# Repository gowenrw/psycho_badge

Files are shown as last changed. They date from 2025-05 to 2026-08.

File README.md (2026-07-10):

# psycho_badge

This is where all the files for psycho_badge will be stored.

This includes code and art and cad and fab files.  All the things.

## File Structure

This is the file structure of this repository

* [/](/README.md) <- YOU ARE HERE
* [/3d_parts/](./3d_parts/) - 3D models of parts used in this project
* [/art/](./art/) - Artwork and other graphics created by this project
  * [/art/fonts/](./art/fonts/) - Fonts used in art and graphics
  * [/art/inspiration/](./art/inspiration/) - Art and graphics pulled from other sources used as inspiration for this project
  * [/art/logos/](./art/logos/) - Logos used in this project
* [/code/](./code/) - All project related Code / Firmware
* [/docs/](./docs/) - Documentation created by this project including web pages
* [/eda/](./eda/) - Electronic Design Automation files (i.e. KiCad)
  * [/eda/psycho_badge/](./eda/psycho_badge/) - KiCad 9.x project folder for the psycho_badge PCB
* [/reference_parts/](./reference_parts/) - Submodule of Third Party Documentation related to components
* [./README.md](/README.md) - This File
* [./LICENSE](/LICENSE) - Currently set to MIT

Note: the reference_parts directory is a link to a submodule repository.
To add it use the following cmd after cloning this:
```
git submodule add https://github.com/gowenrw/reference_parts reference_parts
```
This will make a link to the current commit of that repo.
To update it to a newer commit after its been added use this cmd:
```
git submodule update --init --recursive
```

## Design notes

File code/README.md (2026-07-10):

# Code

This is where all the project related Code / Firmware is located

# File Structure

This is the file structure of this repository

* [/](/README.md) - Home
* [/code/](/code/) - All project related Code / Firmware <-YOU ARE HERE

# Arduino IDE/CLI

The code presented here is mostly Arduino code.

In order to use this code and push new code to the ESP32 on the badge we recommend using the Arduino IDE/CLI software.
This can be downloaded for various platforms at [arduino.cc](https://www.arduino.cc/en/software).

The Arduino IDE UI will require some manual configuration to work with the badge ESP32 and our code.

The Arduino CLI can be used instead and allows for scripting much of the initial setup and use of whichever IDE you like (in my case I use VSCode).

# Arduino Versions

These are the Arduino IDE and CLI versions we have tested the code with:

* Arduino IDE v 2.3.2
  * [Windows MSI Link](https://downloads.arduino.cc/arduino-ide/arduino-ide_2.3.2_Windows_64bit.msi)
  * [Linux 64bit AppImage Link](https://downloads.arduino.cc/arduino-ide/arduino-ide_2.3.2_Linux_64bit.AppImage)
  * [MacOS ARM64bit DMG Link](https://downloads.arduino.cc/arduino-ide/arduino-ide_2.3.2_macOS_arm64.dmg)
  * [Installation Instructions](https://docs.arduino.cc/software/ide-v2/tutorials/getting-started/ide-v2-downloading-and-installing)
* Arduino CLI v 0.35.3
  * [Windows MSI Link](https://github.com/arduino/arduino-cli/releases/download/v0.35.3/arduino-cli_0.35.3_Windows_64bit.msi)
  * [Linux 64bit Tarball Link](https://github.com/arduino/arduino-cli/releases/download/v0.35.3/arduino-cli_0.35.3_Linux_64bit.tar.gz)
  * [MacOS ARM64bit Tarball Link](https://github.com/arduino/arduino-cli/releases/download/v0.35.3/arduino-cli_0.35.3_macOS_ARM64.tar.gz)
  * [Installation Instructions](https://arduino.github.io/arduino-cli/0.35/installation/)

WARNING - DO NOT use Arduino CLI v 1.x if you want the scripts here to work, it is very buggy concerning local config files and relative paths

# Quickstart

If you want to jump right in and start compiling and uploading code using the Arduino CLI and the scripts provided then checkout the [QUICKSTART page](QUICKSTART.md).

# Arduino IDE setup and use

Some additional setup is required to use the Arduino IDE with the ESP32 on the badge:

* Add the ESP32 boards manager URL in preferences
  * Under File->Preferences find the "Additional boards manager URLs" section and add the following
  * https://espressif.github.io/arduino-esp32/package_esp32_index.json
  * Then click OK and close the IDE.  When it is reopened it wil download the ESP32 board definitions.
* Select the board "ESP32 Dev Module"
  * You need to select a board to associate with the code even if that board is not connected
  * In the "Select Board" dropdown, choose "ESP32 Dev Module" from the list
  * The first time you do this it may download some addiotional software.
* Connect the ESP32 via USB cable and select the COM port if it is not autodetected
  * In most cases it should autodetect the port
  * Sometimes on first connect you need to help it by going to Tools->Port and choosing the port
* This code exceeds the normal partition size so make sure you select the Minimal SPIFFS Partition type
  * This setting can be found under Tools -> Partition Scheme
* This code uses the AdaFruit NeoPixel library which needs to be installed
  * The library can be installed via the Arduino IDE library manager or manually
  * Installation instructions can be found at [the adafruit neopixel github page](https://github.com/adafruit/Adafruit_NeoPixel)

Once the Arduino IDE environment has been set up you can simply open one of the sketches here, make whatever changes you like, then compile and upload the code to the badge.

# Arduino CLI

In an effort to bring portability to the code here (since this is lacking in the Arduino 2.x IDE) we will be providing a local configuration file for the Arduino CLI and scripts to make use of it.

While we cannot ensure this will work on all systems, the files provided should at a minimum help you configure your local environment.

## Using the CLI Local Config

The arduino cli will use a global default config if a config file is not specified.

A local config file is provided named ```arduino-cli.yml``` which uses relative path references for the data and staging and build and user area that Arduino CLI should use.

These directories are local to the repository code directory and the CLI will install all its needed files here instead of in the various places it usually defualts to on differnt systems.

While this might duplicate many files on your system if they are already installed in default locations, it provides a consistent cross platform way of knowing exactly what libraries, headers, etc., that Arduino will use in the compilation of your code.

NOTE that the .gitignore for this repository has been set up to ignore the local directories used to store the core and library files to prevent these files from accidentally getting uploaded to github.

To use the Arduino CLI with this local config file simply add the ```--config-file arduino-cli.yml``` argument to each CLI command.

For example, the command below uses the local config file and will dump the current config to the screen
```
arduino-cli --config-file arduino-cli.yml config dump
```

## Setup for CLI

There are a few things that need to be done to setup the Arduino CLI for use with the badge ESP32 and our code.

The ESP32 board core files must be loaded as well as any libraries the code will use.

To simplify this setup we have created setup bash script named ```cli-setup.sh``` that can be run on Linux and Windows (via Git Bash for Windows).

To perform the CLI setup via the script execute it in the code directory
```
bash ./cli-setup.sh
```

This script will save any std_out and std_err output to a file named ```arduino_cli_setup.log``` which you can review if you are having issues.

To perform the CLI setup manually without this script you can use the commands outlined below.

### Installing the ESP32 board core for CLI

Since the config is specifying a third party core for the ESP32 we need to pull an initial index from it.  This search command will pull that index.
```
arduino-cli --config-file arduino-cli.yml core search esp32
```

Next we need to install the ESP32 board core files using this command.
```
arduino-cli --config-file arduino-cli.yml core install esp32:esp32
```

If the ESP32 board core files were already installed the above will simply say already installed.

To update the core file indexs to check for newer versions of previously installed cores, use the following command
```
arduino-cli --config-file arduino-cli.yml core update-index
```

To upgrade any previously installed cores use the following command
```
arduino-cli --config-file arduino-cli.yml core upgrade
```

### Installing the Neopixel Library

This code uses the AdaFruit NeoPixel library which needs to be installed

If this is the first time we are installing a library we will need the indexes so this search command will get them
```
arduino-cli --config-file arduino-cli.yml lib search 'Adafruit NeoPixel'
```

Next we need to install the Adafruit NeoPixel library files with this command
```
arduino-cli --config-file arduino-cli.yml lib install 'Adafruit NeoPixel'
```

If the Adafruit NeoPixel library files were already installed the above will simply say already installed.

To upgrade a previously installed version of this library use the following command
```
arduino-cli --config-file arduino-cli.yml lib upgrade 'Adafruit NeoPixel'
```

### Installing Other Libraries

In addition to the Neopixel Library above the CTF portion of our code requires a few more libraries.

These should be installed using the same steps as above.

This is the list of additional libraries needed

* "AsyncTCP"
* "ESPAsyncWebSrv"
* "DNSServer"

## Connect badge ESP32 board via CLI

The following command will dump a list of all available board cores installed
```
arduino-cli --config-file arduino-cli.yml board listall
```

Make sure the ESP32 we are using on the badge is in that list
```
  ESP32 Dev Module                 esp32:esp32:esp32
```

If it is not then retry the CLI setup to install the core files.

Next we will connect the badge ESP32 to our machine using a USB C cable
and check if the CLI can see it.

The following command will list all the connected boards the CLI sees
```
arduino-cli --config-file arduino-cli.yml board list
```

This will show the detected COM port and board type (which may be Unknown)
```
  Port Protocol Type                Board Name FQBN Core
  COM4 serial   Serial Port (USB)   Unknown
```

Don't worry if the board FQBN shows up as Unknown since we can set that

Take note of the COM port since we will need that to communicate with it later

## Compile code via CLI

At this point we should be ready to compile and upload code to the badge ESP32 board.

In the following examples we will be referencing the sketch ```psycho_badge_01``` code so you will need to change this for whichever sketch you wish to use.

The following command will compile the named sketch for use with our board fqbn
```
arduino-cli --config-file arduino-cli.yml compile --fqbn esp32:esp32:esp32 --build-path _build --export-binaries psycho_badge_01 --build-property build.partitions=min_spiffs --build-property upload.maximum_size=1966080
```

The arg ```--build-path _build``` is optional to have it put all build artifacts here instead of temp for ease of troubleshooting.

The arg ```--export-binaries``` will save the final binary files into ```<sketch_name>/build/<fqbn>/``` for use by upload.

The build property args ```--build-property build.partitions=min_spiffs --build-property upload.maximum_size=1966080``` make sure that the partition size and upload size are set properly.
Our code is THIC and wont fit in the default partition size.

When the CLI compile is run it should show you compile stats and/or errors similar to this
```
  Sketch uses 1827197 bytes (92%) of program storage space. Maximum is 1966080 bytes.
  Global variables use 48884 bytes (14%) of dynamic memory, leaving 278796 bytes for local variables.
  Maximum is 327680 bytes.
  Used library        Version Path
  Adafruit NeoPixel   1.11.0  .\code\libraries\Adafruit_NeoPixel
  WiFi                2.0.0   .\code\_data\packages\esp32\hardware\esp32\2.0.11\libraries\WiFi
  AsyncTCP            1.1.4   .\code\libraries\AsyncTCP
  DNSServer           2.0.0   .\code\_data\packages\esp32\hardware\esp32\2.0.11\libraries\DNSServer
  ESPAsyncWebSrv      1.2.6   .\code\libraries\ESPAsyncWebSrv
  FS                  2.0.0   .\code\_data\packages\esp32\hardware\esp32\2.0.11\libraries\FS
  Used platform Version Path
  esp32:esp32   2.0.11  .\code\_data\packages\esp32\hardware\esp32\2.0.11
```

### Script to Compile code via CLI

To simplify the above we have created a bash script named ```cli-compile.sh``` that takes a single command line argument of the sketch name.

To perform the compile via the script execute it in the code directory
```
bash ./cli-compile.sh psycho_badge_01
```

## Upload code via CLI

Now we are ready to upload the binary we compiled to the badge ESP32 board.

Note that the binary file needed is saved to ```<sketch_name>/build/<fqbn>/``` and will be named ```<sketch_name>.ino.bin```
The code we have written here may include binaries which can be used without compiling and if you make changes and compile then these files should be overwritten.

The following command will upload the named sketch binary to the badge
```
arduino-cli --config-file arduino-cli.yml upload -p COM4 --fqbn esp32:esp32:esp32 --input-file psycho_badge_01/build/esp32.esp32.esp32/psycho_badge_01.ino.bin
```

NOTE: Saving the compiled binary in a defined place and uploading from an input file allows for quickly changing between different code without the need to compile each again.

It should show you upload stats and/or errors
```
  esptool.py v4.5.1
  Serial port COM4
  Connecting....
  Chip is ESP32-D0WD-V3 (revision v3.0)
  Features: WiFi, BT, Dual Core, 240MHz, VRef calibration in efuse, Coding Scheme None
  Crystal is 40MHz
  MAC: a8:42:e3:47:f0:50
  Uploading stub...
  Running stub...
  Stub running...
  Changing baud rate to 921600
  Changed.
  Configuring flash size...
  Flash will be erased from 0x00001000 to 0x00005fff...
  ...
  Compressed 18960 bytes to 13073...
  Writing at 0x00001000... (100 %)
  Wrote 18960 bytes (13073 compressed) at 0x00001000 in 0.3 seconds (effective 538.9 kbit/s)...
  Hash of data verified.
  ...
  Compressed 732656 bytes to 475614...
  Writing at 0x00010000... (3 %)
  Writing at 0x0001c1bd... (6 %)
  ...
  Writing at 0x000bcec0... (96 %)
  Writing at 0x000c2b72... (100 %)
  Wrote 732656 bytes (475614 compressed) at 0x00010000 in 6.3 seconds (effective 925.8 kbit/s)...
  Hash of data verified.
  Leaving...
  Hard resetting via RTS pin...
```

### Script to Upload code via CLI

To simplify the above we have created a bash script named ```cli-upload.sh``` that takes two command line arguments of the sketch name and serial port.

To perform the compile via the script execute it in the code directory
```
bash ./cli-upload.sh psycho_badge_01 COM4
```

## Monitor Serial Output

To monitor the serial output you can use the arduino-cli or your favorite serial app.

The following command will list all the connected boards so you can get the serial port
```
arduino-cli --config-file arduino-cli.yml board list
```

The arduino-cli monitor command with serial port (from above) and baud config can be used like this:
```
arduino-cli monitor --port COM4 --config baudrate=115200
```

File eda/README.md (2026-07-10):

# Electronic Design Automation

This is where all the Electronic Design Automation files for the PCB(s) will be stored.
The EDA used is KiCad 9.x unless otherwise specified.

The KiCad projects have been configured to use local libraries for long term sustainability per the best practices listed [HERE](https://hackaday.com/2017/05/18/kicad-best-practises-library-management/) and elsewhere.

## File Structure

This is the file structure of this repository

* [/](/README.md) - Home
* [/eda](/eda/) - Electronic Design Automation files - YOU ARE HERE
  * [/eda/psycho_badge/](/eda/psycho_badge/) - KiCad 9.x project folder for the psycho_badge PCB
    * ./3d_models/ - This directory contains footprint 3d model files
    * ./gerber/ - This directory contains gerber formatted files for manufacturing
    * ./lib_fp/ - This directory contains footprint module directories
    * ./lib_sh/ - This directory contains schematic library files
    * ./snapshots/ - This directory contains prints of schematic / cad files and images of preview / final product
  * [/eda/psycho_sao/](/eda/psycho_sao/) - KiCad 9.x project folder for the psycho_badge SAO PCBs
    * ./3d_models/ - This directory contains footprint 3d model files
    * ./gerber/ - This directory contains gerber formatted files for manufacturing
    * ./lib_fp/ - This directory contains footprint module directories
    * ./lib_sh/ - This directory contains schematic library files
    * ./snapshots/ - This directory contains prints of schematic / cad files and images of preview / final product

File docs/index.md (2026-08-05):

---
layout: default
---

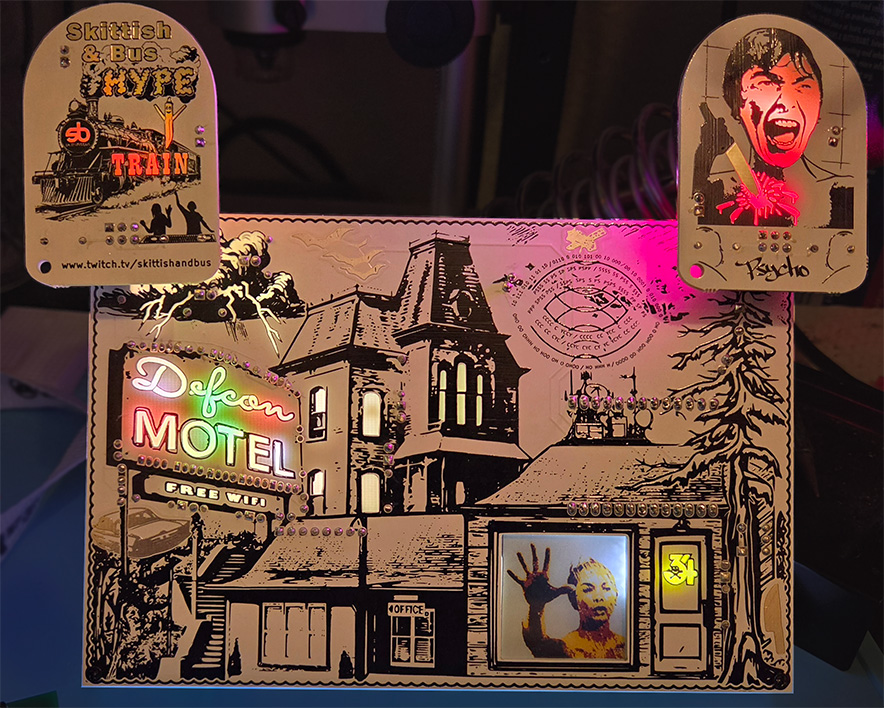
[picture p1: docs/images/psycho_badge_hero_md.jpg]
Hero Image


# Psycho Badge

Welcome to the Psycho Badge website.

This badge was designed for the DEFCON 34 security conference in August 2026.

On this page you will find all the details about this badge including an operations guide, some information about assembly, and a detailed review of the art and cicuit design and pcb design.

-- [@alt_bier](https://twitter.com/alt_bier)

---

# Overview

The badge theme was based on the 1960 movie Psycho by Alfred Hitchcock.

I wanted to make use of a multi-color eink display as a way to show scenes from the motel room and I think this worked out perfectly for that.

I also wanted to make use of electro-luminescent paint for the neon sign, but alas I couldn't work out the technical details in time to make that work on this badge.  But I think the back lit solder mask voids I ended up going with looks great.

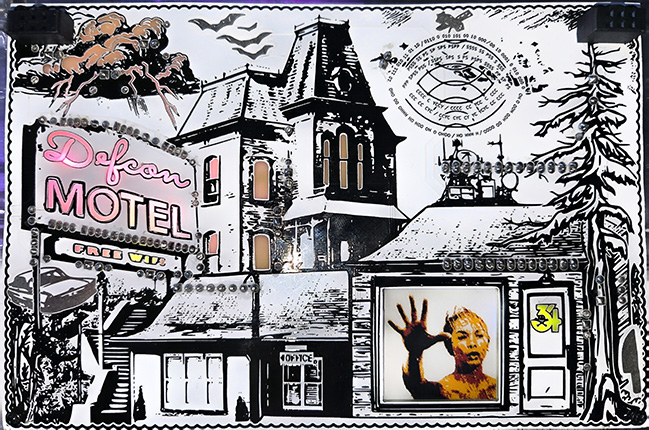
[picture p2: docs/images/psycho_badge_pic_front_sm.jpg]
Badge Pic Front


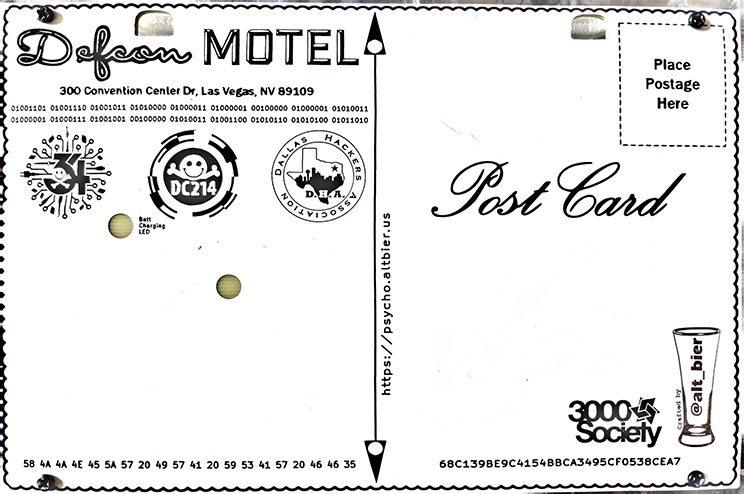
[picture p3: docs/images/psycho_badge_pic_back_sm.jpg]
Badge Pic Back


The badge has two SAO connectors and I made a Psycho themed SAO that pairs well with the badge.

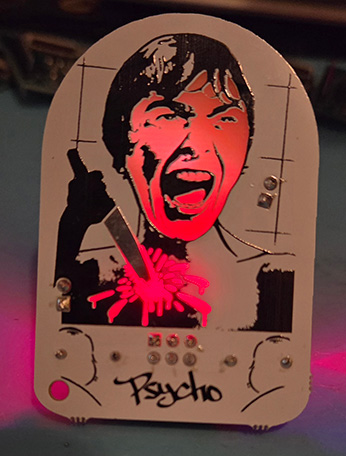
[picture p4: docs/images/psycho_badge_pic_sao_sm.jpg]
Badge Pic SAO


---

# Operations Guide

## Basic Operation

The on/off switch controls the battery power.  Due to a miscalculation on my part the switch is ON if it is in the down position relative to the top of the badge and OFF in the up position.

The badge can operate on USB C power with the battery switched off and it is recommended for the battery to be off when flashing code or using data to the ESP.

To charge the battery make sure the battery is turned on and plug it into USB power.  You will see an LED indicator on the back of the badge light up while the battery is charging and that light will go off when the battery is fully charged.

## Capacitive Touch Functions

### Short Press Of Touch Pads
To change the color of the LEDs in the neon sign press the BATS on the top left area of the badge.

To toggle the mode of the LEDs in the neon sign from static color to color wheel shifting colors or back again press the SATELLITE on the top right area of the badge.

To Turn the "Free Wifi" LEDs on or off press the CAR on the bottom left area of the badge.

To Turn the Defcon 34 Logo on the Door on or off press the KNIFE on the bottom right area of the badge. Note: This light also acts as a screen light since the EINK display is not backlit.

### Long Press Of Touch Pads

To change the display image to the next one in order press and hold the KNIFE for about 20 seconds.

To change the display image to the previous one in order press and hold the CAR for about 20 seconds.

To turn off all LEDs on the front of the badge while keeping the badge powered on (useful for battery charging unless you like a night lite) press and hold the BATS for about 40 seconds.

---

# Crypto Challenge

This is still a work in progress, but I will be adding more details soon.

---

# Details

Lets get into the details of this badge, like Art and Schematics and PCB design and Component choices.

## Pinout and Bill of Materials

Since there is a lot of information to cover, I have put the pinout and bill of materials on a separate page here:
[Psycho Badge Pinout and Bill of Materials](psycho_badge_pinout_and_BOM.md)

## Schematics 

Since the ESP Dev board has an embedded battery charge circuit and the fact that I moved all the eink display circuitry to a seperate dev board, the schematic for the main badge was fairly simple.

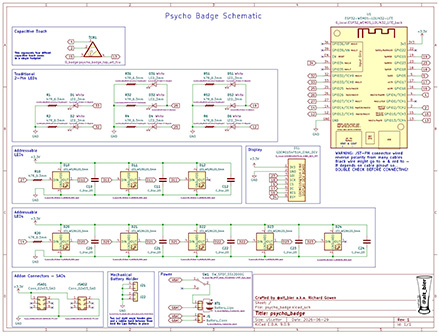
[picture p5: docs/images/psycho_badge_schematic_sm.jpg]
Badge Schematic


The schematic for the eink display dev board was a bit more complex but I basically just stole its design from the dev board that the nice people at Good Display sell since they put thier schematic online.

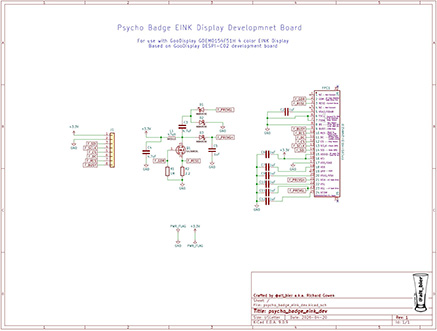
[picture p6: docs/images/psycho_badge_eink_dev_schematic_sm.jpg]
Eink Display Dev Schematic


The SAO schematic is basically a cut and paste from what I did for the G0dzilla badge minus the extra resistors at different values, making it a much simpler template I can reuse in the future as well.

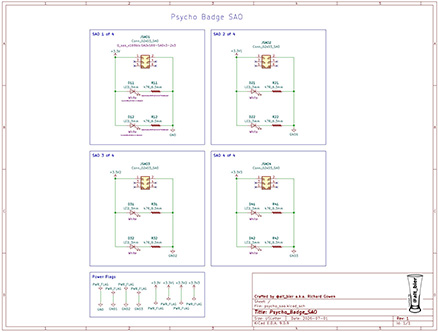
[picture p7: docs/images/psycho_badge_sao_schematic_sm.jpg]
Badge SAO Schematic


## PCB Design

The PCB layout and tracing of the badge PCBs was a challenge due to all the solder mask voids and capacitive touch areas and cutouts and other areas to avoid.

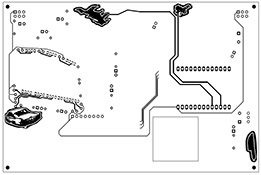
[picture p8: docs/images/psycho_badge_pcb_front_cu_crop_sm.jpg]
Badge PCB Front CU


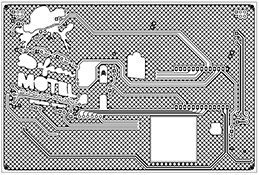
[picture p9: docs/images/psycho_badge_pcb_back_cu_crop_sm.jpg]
Badge PCB Back CU


The PCB layout and tracing of the eink dev board was fairly easy, with the hardest part being squishing everything together to keep the PCB size as small as possible.

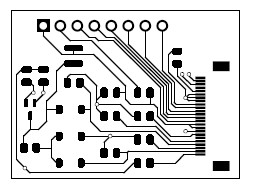
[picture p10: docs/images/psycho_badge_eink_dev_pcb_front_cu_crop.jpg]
Eink Display Dev PCB Front CU


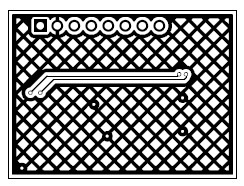
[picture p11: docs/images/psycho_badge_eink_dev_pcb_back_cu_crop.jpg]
Eink Display Dev PCB Back CU


The PCB layout and tracing of the SAO was simple given how few components there are.

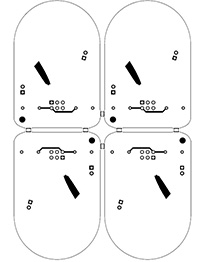
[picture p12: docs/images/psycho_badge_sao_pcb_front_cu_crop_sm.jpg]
Badge SAO PCB Front CU


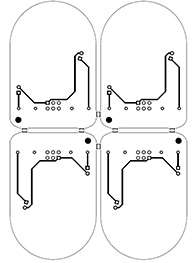
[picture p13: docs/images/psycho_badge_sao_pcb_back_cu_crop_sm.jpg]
Badge SAO PCB Back CU


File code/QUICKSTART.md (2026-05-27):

# Code Quickstart

Notes:

* You will need Arduino CLI Installed and a Bash shell (on Windows Git Bash is provided by Git for Windows)
* The CTF code is a precompiled library so you cant change that for now, source to be released after defcon
* The current code that is loaded on the badge is the sketch named ```psycho_badge_01```

## Setting up Arduino CLI environment

Follow these steps:

* Change directory to the code directory if you arent already there
* Run the following command preceding it with ```bash``` if needed by your OS
  * ```./cli-setup.sh```
* If it completes without errors then setup is complete
  * If you have errors then refer to the main README doc or script file to try the steps manually

## Compiling Code

Once you have made whatever changes you wanted to the code here is how we compile it.

* Change directory to the code directory if you arent already there
* Run the following command preceding it with ```bash``` if needed by your OS changing the sketch name if needed
  * ```./cli-compile.sh psycho_badge_01```
* If it completes without errors then the compile is complete
  * If you have errors then read what they are and make the appropriate changes to your code

## Upload Code

Once the code has been compiled we can upload it to the badge.

Follow these steps:

* Change directory to the code directory if you arent already there
* Run the following command
  * ```arduino-cli --config-file arduino-cli.yml board list```
* Take note of the serial port name of the connected board 
* Run the following command preceding it with ```bash``` if needed and changing the serial port to above
  * ```./cli-upload.sh psycho_badge_01 COM6```

## Serial Monitor

Once the code has been uploaded you can use the serial monitor to look for any text the code is sending.

* Run the following command changing the serial port to what board list showed above
  * ```arduino-cli monitor --port COM6 --config baudrate=115200```

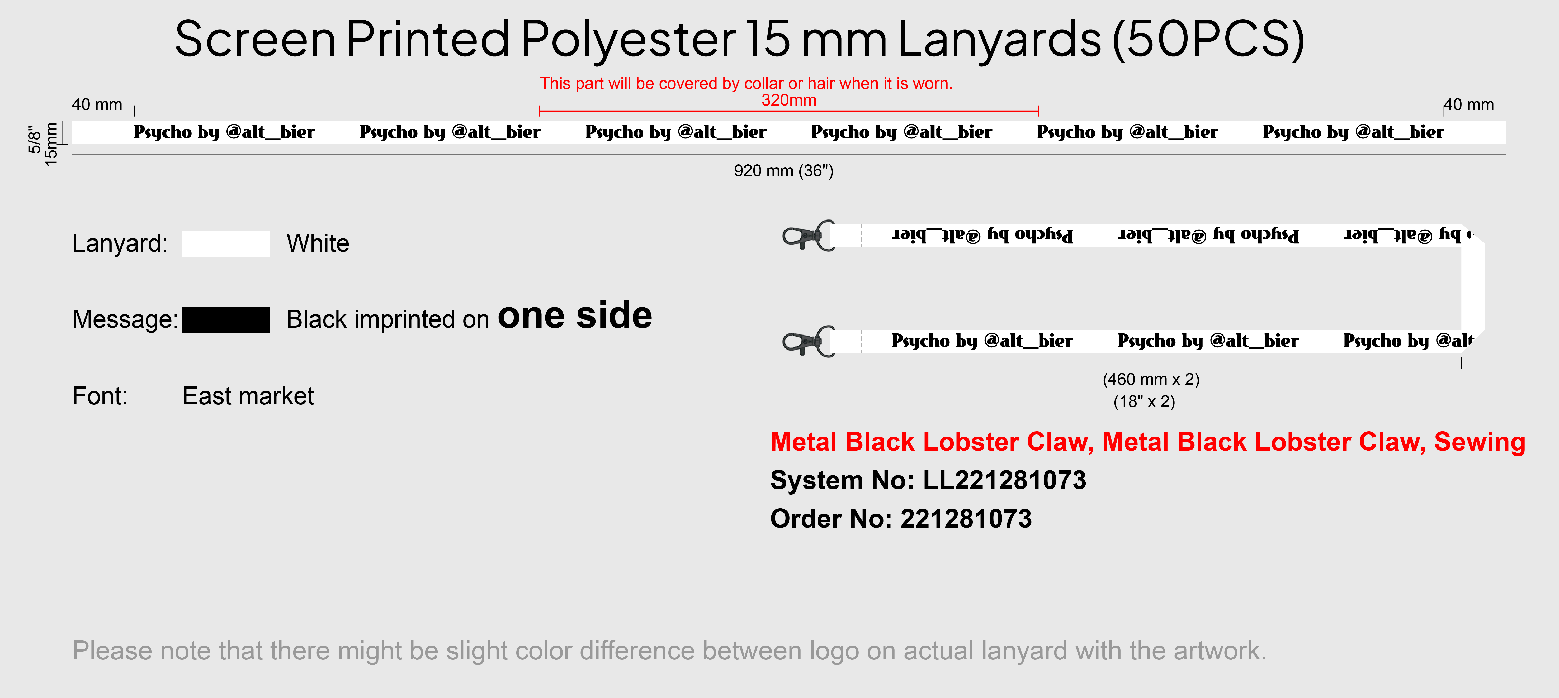
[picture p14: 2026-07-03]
docs/lanyard_proof.png

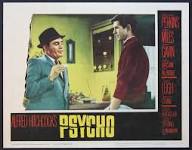
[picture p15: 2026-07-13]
art/inspiration/PsychoLC5A_2.jpg

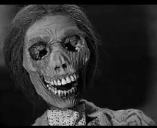
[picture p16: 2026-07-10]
art/inspiration/Screenshot 2026-07-10 091427.png

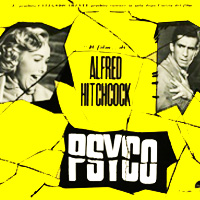
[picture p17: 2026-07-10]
art/psycho_display_img01.jpg

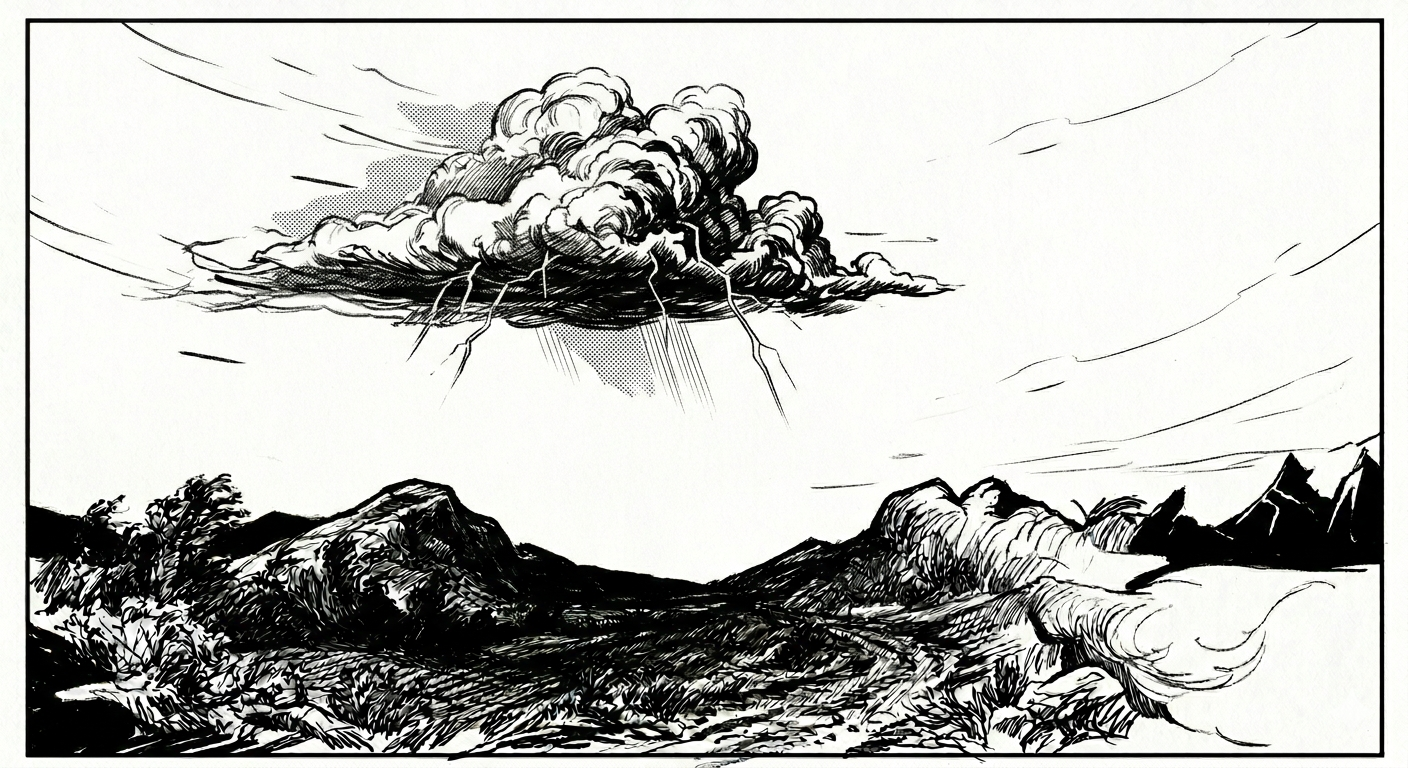
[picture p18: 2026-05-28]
art/inspiration/alt_bier_image_rrnbitrrnbitrrnb.png

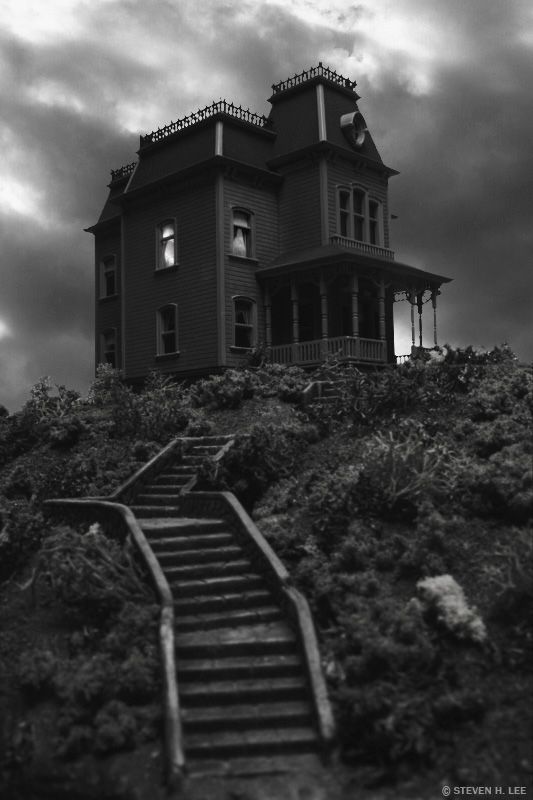
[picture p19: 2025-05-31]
art/inspiration/5f103922b00b9d7b980ad2bd9242dba4.jpg

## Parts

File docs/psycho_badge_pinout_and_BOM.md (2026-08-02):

# Psycho Badge Pinout and Bill of Materials

## Pinout

ESP32 PINS and Their Connections on the Badge

NEOPIXEL Strings
* 27 - Neo String 1 - D10, D11, D12 - Defcon
* 14 - Neo String 2 - D20, D21, D22, D23, D24 - MOTEL

Tradional LEDs
* 22 - Built In LED
* 33 - D1 - FREE
* 32 - D2 - WIFI
* 26 - D31, D32 - Clouds
* 25 - D4 - Clouds
* 19 - D51, D52 - Mansion
* 12 - D6 - Room_Door

EINK Dev Board
* 23 - DevBd 3 - SDI
* 18 - DevBd 4 - SCK
* 5  - DevDb 5 - CS
* 17 - DevBd 6 - DS
* 16 - DevBd 7 - RES
* 34 - DevBd 8 - BSY
* 0  - Remap ESP32 MISO default pin 19 (not used by EINK but conflict with LED)

Capacitive Touch Pads
* 4  - TCH1 1 - Bats
* 2  - TCH1 2 - Satelite
* 15 - TCH1 3 - Car
* 13 - TCH1 4 - Knife

## Bill of Materials

Controller - Qty 1
* ESP32-WEMOS-LOLIN32-LITE v1.0 with USB-C connector
  * https://www.aliexpress.us/item/3256808856916958.html

Addressable LEDs - Qty 8
* WS2812D F5 5mm LED (NeoPixel)
  * https://www.aliexpress.us/item/2251832645784910.html

Traditional LEDs White - Qty 8
* 3mm Round White LEDs
  * https://www.aliexpress.us/item/2251832158199793.html

Resistors 47Ohm - Qty 10
* 47 Ohm 1/4W Resistor
  * https://www.aliexpress.us/item/3256805626032565.html

Capacitors 100nF - Qty 8
* Ceramic Disc Capacitor 0.1uF 50V 104PF 100NF
  * https://www.amazon.com/Cermant-Ceramic-Capacitor-Electronic-Components/dp/B09XV2H8JQ

SAO Connectors (Badge Side) - Qty 2
* 2.54mm 0.1" Pitch Female Pin Header Strip 2x3 Pin 6 Pin With Polarizing Key
  * https://www.aliexpress.us/item/2251832874579437.html

LIPO Battery - Qty 1
* 103040 3.7V 1200mAh Polymer Lithium Rechargeable Battery
  * https://www.aliexpress.us/item/3256811756405914.html

JST Battery Connector Cable - Qty 1
* JST 1.25mm 2 Pin Micro Female Connector Plug with Red Black Wire
  * https://www.amazon.com/dp/B013JRWCBU

Header Pins 1x2/90-Degree for Battery Holding - Qty 2
* 1x2 2.54mm Male 90-Degree Right Angle Header Pins
  * https://www.amazon.com/dp/B07C89T16T

Rubber Bands for Battery Holding - Qty 2
* #8 Rubber Bands - 7/8" x 1/16"
  * https://www.amazon.com/dp/B0BN6MKF99

Two Position Slide Switch - Qty 1
* Slide Switch SS12D00 SS12D03G5 3pin Curved 90 Degree Needle 1P2T 2 Position 5mm Handle
  * https://www.aliexpress.us/item/2251832665517359.html

EINK Display - Qty 1
* GDEM0154F61H GooDisplay 1.54 inch E-paper Four Color (Yellow and Red) Display 200x200
  * https://www.aliexpress.us/item/3256806898128301.html
  * https://www.good-display.com/product/555.html

Custom Dev Board for EINK Display - Qty 1
* Custom PCB for EINK Display (See psycho_badge_eink_dev schematic for details)
  * Parts for the custom dev board (SMT components)
    * FPC Connector FPC05-H0.5-24AH2.0 24 Position 0.5mm Pitch Double-Sided - Qty 1
      * https://www.lcsc.com/product-detail/C19267963.html
    * Ceramic Capacitor 1uF X7R ±10% 25V 0805 - Qty 8
      * https://www.lcsc.com/product-detail/C53084463.html
    * Ceramic Capacitor 4.7uF X7R ±10% 25V 0805 - Qty 2
      * https://www.lcsc.com/product-detail/C513766.html
    * Resistor 2.2Ohm ±1% 0.125W 0805 - Qty 1
      * https://www.lcsc.com/product-detail/C137549.html
    * Resistor 1MOhm ±1% 0.125W 0805 - Qty 1
      * https://www.lcsc.com/product-detail/C2933280.html
    * Schottky Diode MBR0530 0.5A 30V SOD-123 - Qty 3
      * https://www.lcsc.com/product-detail/C53100353.html
    * Transistor MOSFET SI1308EDL 30V 1.4A 360mW SOT-323 - Qty 1
      * https://www.lcsc.com/product-detail/C7603347.html
    * Inductor NR3015 47uH ±20% 350mA 1.195Ohm SMD-3mmx3mm - Qty 1
      * https://www.lcsc.com/product-detail/C42370344.html

Custom 3D printed spacer insert for PCB sandwich mounting - Qty 1
* 3D printed board spacer for mounting the PCBs
  * 4inch x 6inch overall outer dimentions, 10mm tall, 5mm think with 1.5mm holes for screw mounting, cutout on one side for esp/switch access, divots on top for lanyard hole access.
  * [/3d_parts/board_spacer.3mf](/3d_parts/board_spacer.3mf)

M2 Mounting Screws - Qty 8
* M2 Carbon Steel Cross Phillips Countersunk Pan Head Self Tapping Screws
  * https://www.aliexpress.us/item/3256803991037432.html

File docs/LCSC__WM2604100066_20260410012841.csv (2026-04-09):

LCSC Part Number | Manufacture Part Number | Manufacturer | Customer NO. | Package | Description | RoHS | Quantity | Unit Price($) | Ext.Price($) | Estimated lead time (business days) | Updated lead time | Date Code / Lot No.
C19267963 | FPC05-H0.5-24AH2.0 | XYECONN |  | SMD,P=0.5mm,Surface Mount,Right Angle | FFC/FPC Connector 24 Position 0.5mm Pitch Double-Sided Contacts, Top and Bottom Entry Surface Mount, Right Angle | YES | 150 | 0.088 | 13.20
C53084463 | CC0805X7R25V105KN | TORCH |  | 0805 | 1uF X7R ±10% 25V 0805 Ceramic Capacitors RoHS | YES | 1000 | 0.0066 | 6.60
C513766 | CS2012X7R475K250NRE | SAMWHA |  | 0805 | 4.7uF ±10% 25V Ceramic Capacitor X7R 0805 | YES | 500 | 0.0124 | 6.20
C137549 | RC0805FR-072R2L | YAGEO |  | 0805 | 125mW 2.2Ω 150V Thick Film Resistor ±1% ±200ppm/℃ 0805 Chip Resistor - Surface Mount RoHS | YES | 500 | 0.0077 | 3.85
C2933280 | FRC0805F1004TS | FOJAN |  | 0805 | 1MΩ ±1% 125mW 0805 Thick Film Resistor | YES | 1000 | 0.0017 | 1.70
C53100353 | MBR0530 | TECH PUBLIC |  | SOD-123 | 5.5A 1 Independent 30V 430mV@500mA 5.5A SOD-123 Single Diodes RoHS | YES | 500 | 0.0114 | 5.70
C7603347 | SI1308EDL | TECH PUBLIC |  | SOT-323 | 30V 1.4A 360mW Surface Mount SOT-323 | YES | 300 | 0.058 | 17.40
C42370344 | NR3015S470MT | Magnetsyc |  | SMD,3x3mm | 350mA 47uH 350mA 1.195Ω ±20% SMD,3x3mm Fixed Inductors RoHS | YES | 200 | 0.0226 | 4.52

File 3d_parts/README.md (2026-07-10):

# 3d_parts

3D models of parts used in this project

## File Structure

This is the file structure of this repository

* [/](/README.md) - Home
* [/3d_parts/](/3d_parts/) - 3D models of parts used in this project <- YOU ARE HERE

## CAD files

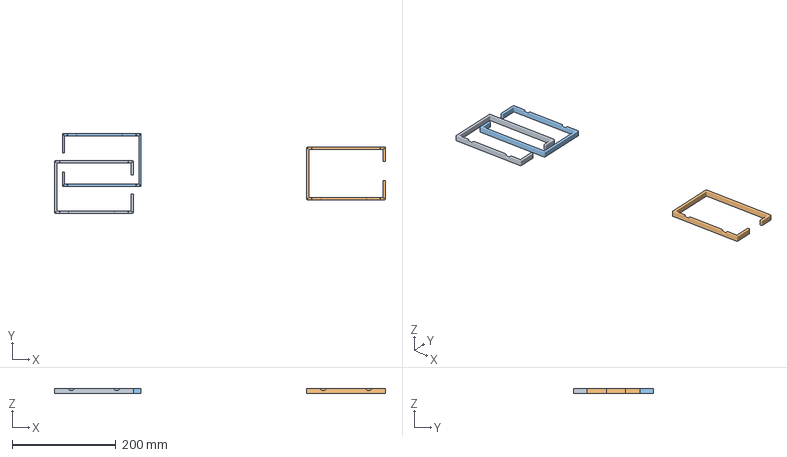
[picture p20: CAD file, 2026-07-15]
3d_parts/CE3PRO_psycho_badge_rev2-board_spacer-2.3mf
638.9 x 153.7 x 10.0 mm
psycho_badge_rev2-board_spacer.3mf
psycho_badge_rev2-board_spacer.3mf(1)
psycho_badge_rev2-board_spacer.3mf(3)

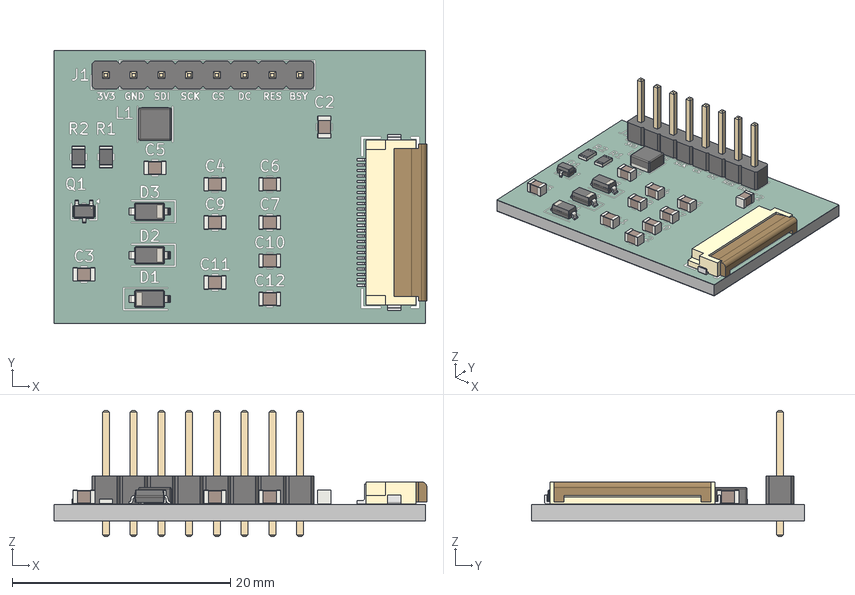
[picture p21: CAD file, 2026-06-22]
eda/psycho_sao/3d_models/psycho_badge_eink_dev.step
34.2 x 25.0 x 11.5 mm
PinHeader_1x08_P2.54mm_Vertical
lock
pins
D_SOD-123 x 3
C_0805_2012Metric x 10
SOT-323_SC-70
R_0805_2012Metric x 2
L_APV_ANR3015
psycho_badge_eink_dev_silkscreen x 2
psycho_badge_eink_dev_soldermask x 2
psycho_badge_eink_dev_PCB

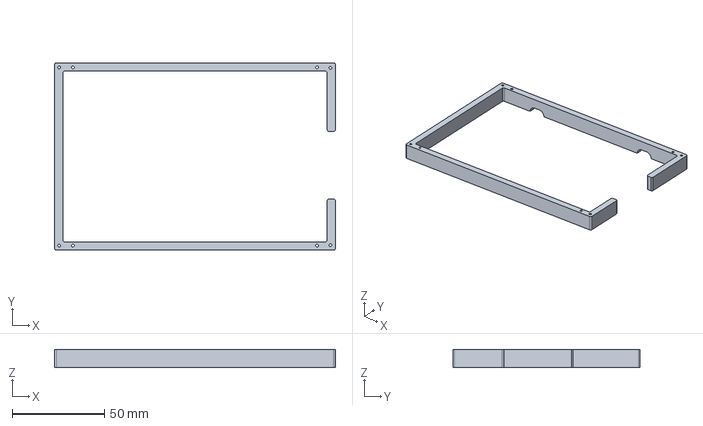
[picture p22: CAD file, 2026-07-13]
3d_parts/psycho_badge_rev2.FCStd
152.4 x 101.6 x 10.0 mm

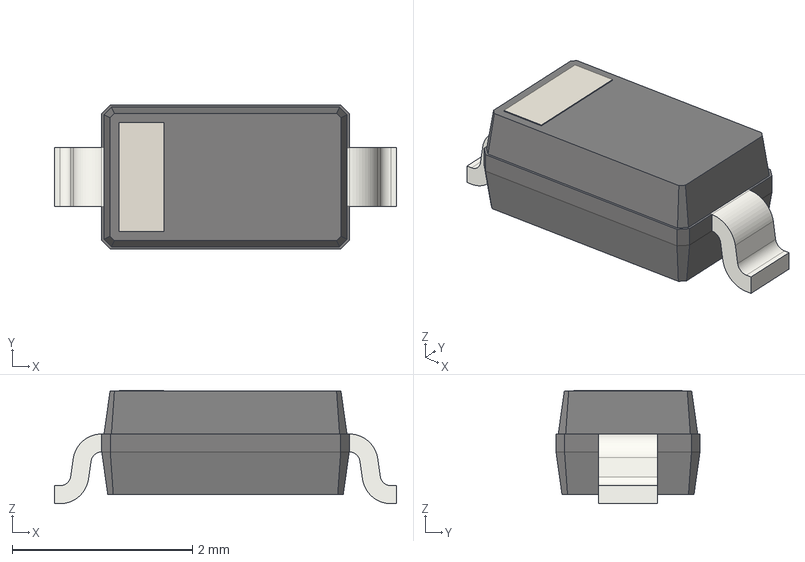
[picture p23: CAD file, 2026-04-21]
eda/psycho_sao/3d_models/D_SOD-123.step
3.80 x 1.60 x 1.26 mm

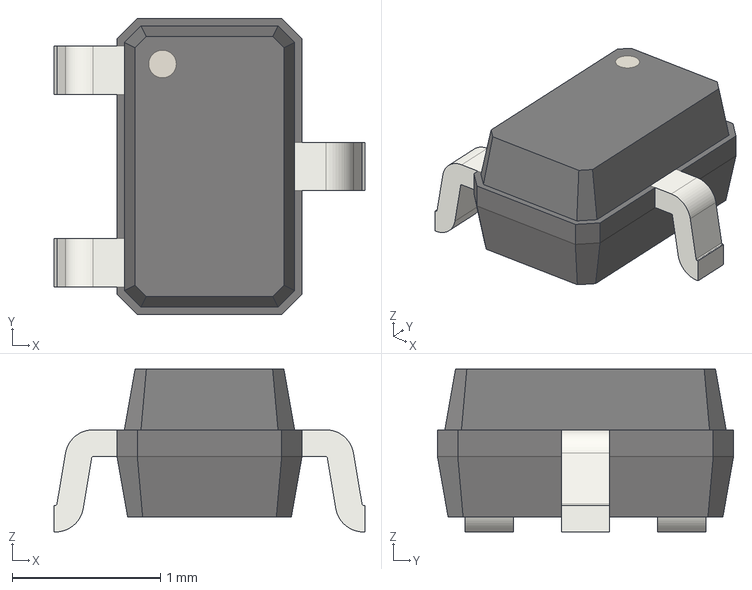
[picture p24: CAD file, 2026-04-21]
eda/psycho_sao/3d_models/SOT-323_SC-70.step
2.10 x 2.00 x 1.10 mm

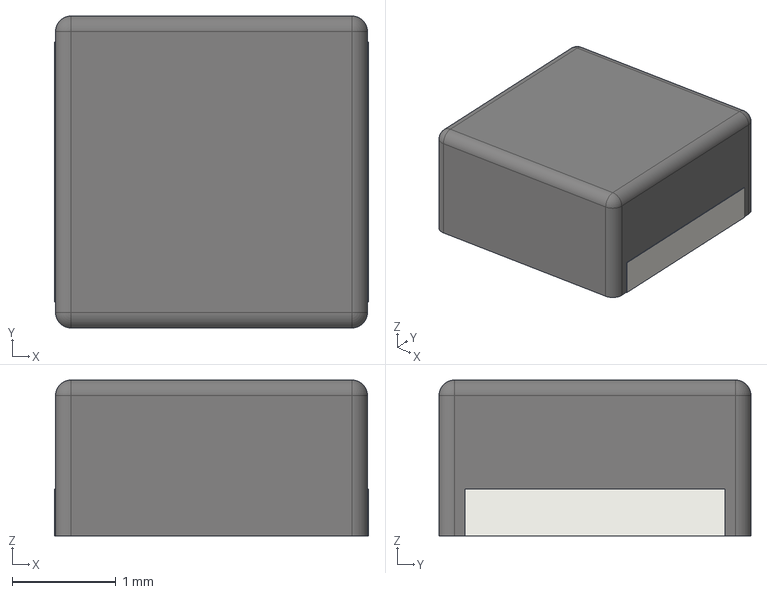
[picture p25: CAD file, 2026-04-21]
eda/psycho_sao/3d_models/L_APV_ANR3015.step
3.02 x 3.00 x 1.50 mm

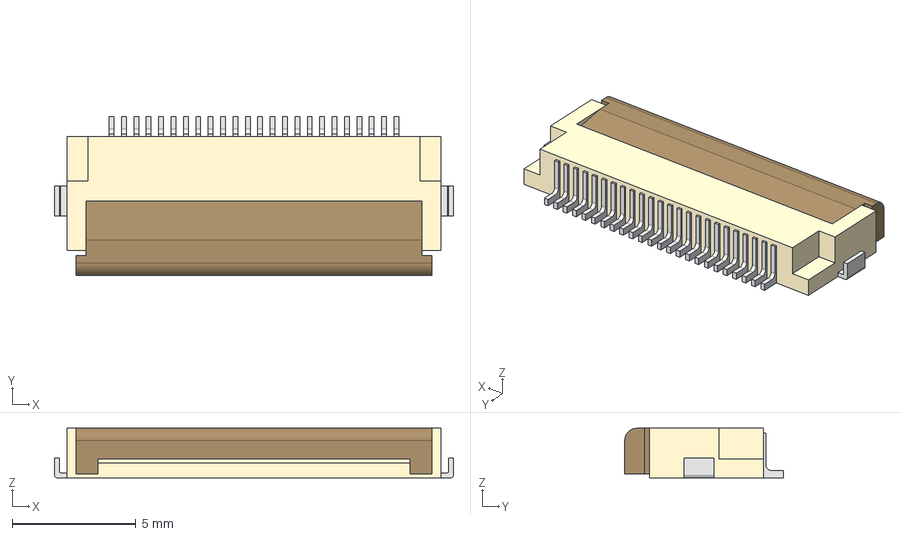
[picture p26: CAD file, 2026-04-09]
eda/psycho_sao/3d_models/Hirose_FH12-24S-0.5SH_1x24-1MP_P0.50mm_Horizontal.step
16.1 x 6.40 x 2.00 mm
lock
pins

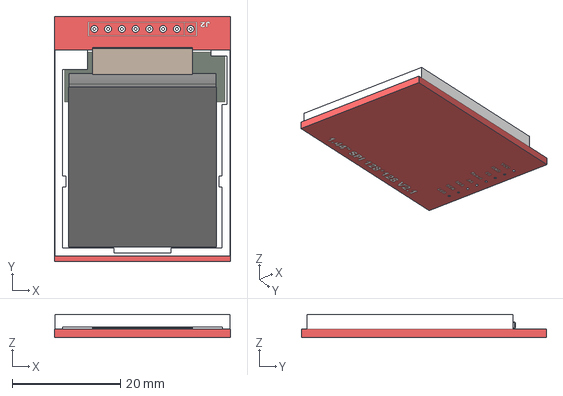
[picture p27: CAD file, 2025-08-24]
eda/psycho_sao/3d_models/TFT_LCD_ST7735S_MSP1443_SPI_1_44IN.STEP
32.5 x 45.2 x 4.32 mm

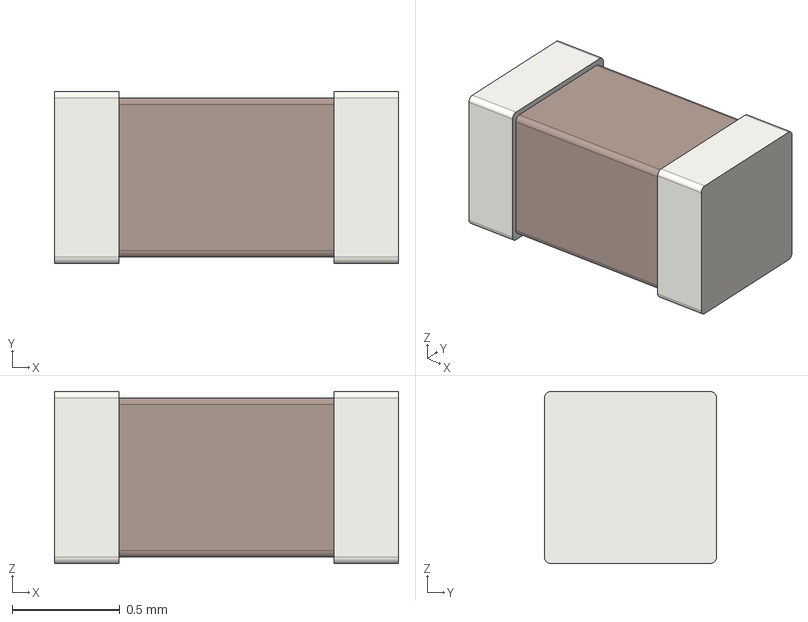
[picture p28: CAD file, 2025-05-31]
eda/psycho_sao/3d_models/C_0603_1608Metric.step
1.60 x 0.8 x 0.8 mm

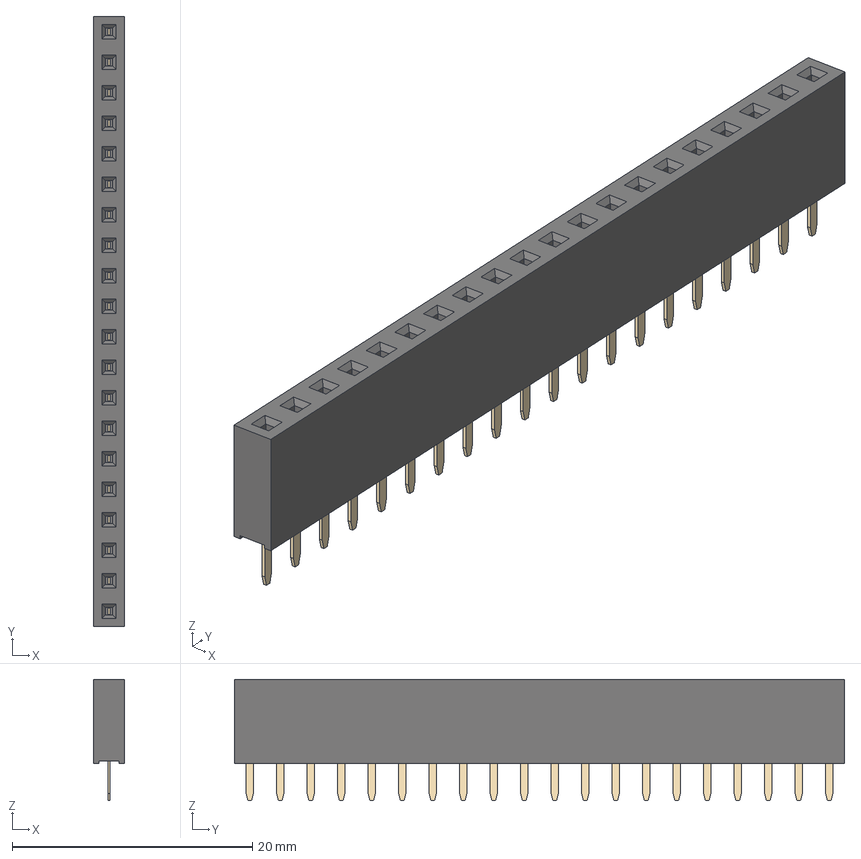
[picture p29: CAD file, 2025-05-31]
eda/psycho_sao/3d_models/PinSocket_1x20_P2.54mm_Vertical.step
2.54 x 50.8 x 10.1 mm

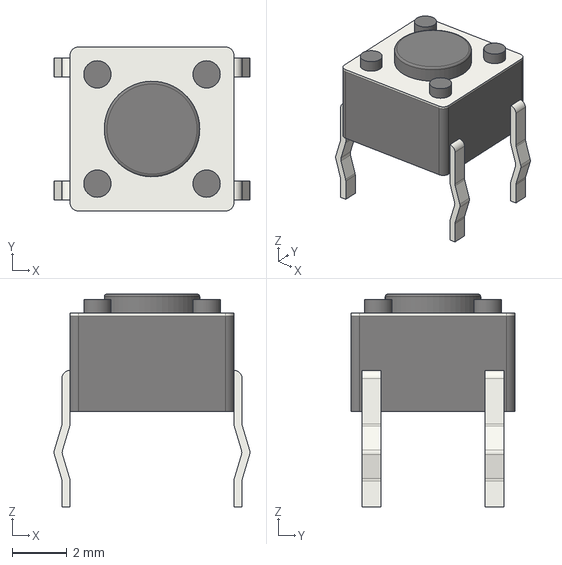
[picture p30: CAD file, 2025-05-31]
eda/psycho_sao/3d_models/SW_PUSH_6mm.step
7.17 x 6.00 x 7.80 mm

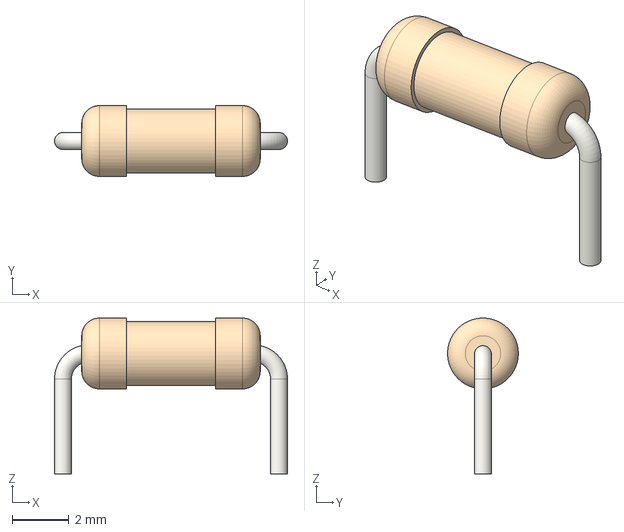
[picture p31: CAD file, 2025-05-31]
eda/psycho_sao/3d_models/R_Axial_DIN0207_L6.3mm_D2.5mm_P7.62mm_Horizontal.step
8.22 x 2.50 x 5.50 mm

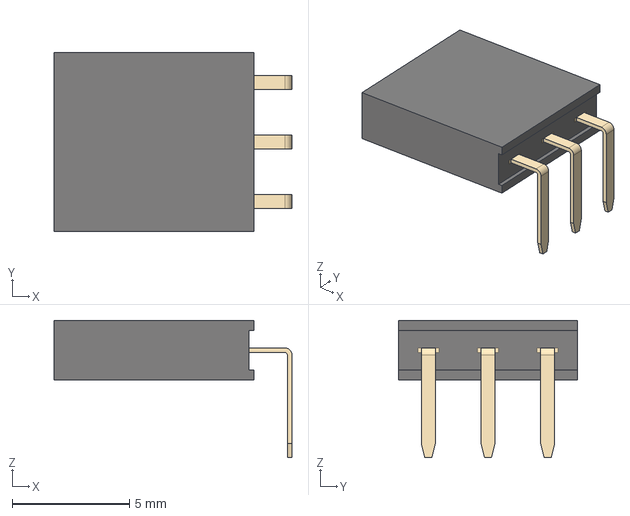
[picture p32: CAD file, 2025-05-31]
eda/psycho_sao/3d_models/PinSocket_1x03_P2.54mm_Horizontal.step
10.1 x 7.62 x 5.84 mm

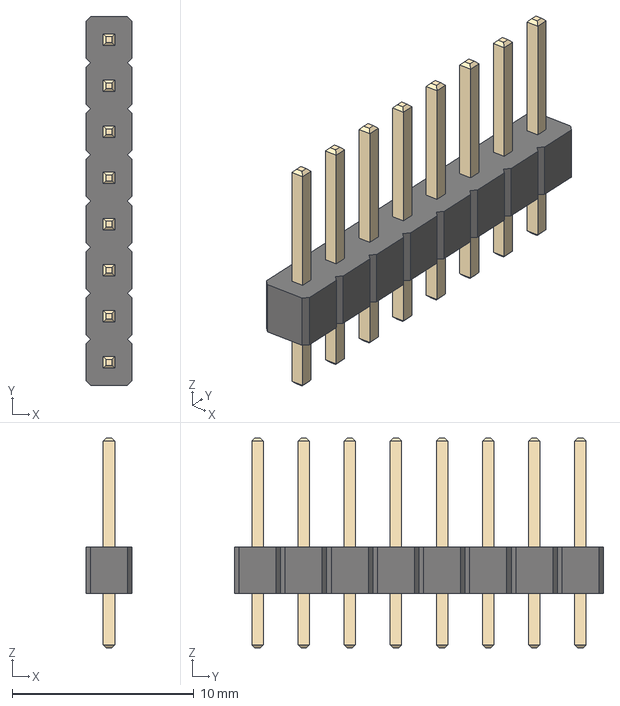
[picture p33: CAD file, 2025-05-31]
eda/psycho_sao/3d_models/PinHeader_1x08_P2.54mm_Vertical.step
2.54 x 20.3 x 11.5 mm

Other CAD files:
3d_parts/psycho_badge_rev2-board_spacer.3mf
3d_parts/CE3PRO_psycho_badge_rev2-board_spacer-1.3mf
3d_parts/board_spacer.3mf
eda/psycho_sao/3d_models/LED_D5.0mm_Horizontal_O1.27mm_Z3.0mm.step
3d_parts/psycho_badge.FCStd
eda/psycho_badge/gerber/psycho_badge_eink_dev_export/psycho_badge_eink_dev-F_Paste.dxf
eda/psycho_badge/gerber/psycho_badge_eink_dev_export/psycho_badge_eink_dev-F_Silkscreen.dxf
eda/psycho_sao/3d_models/BatteryHolder_2466_1xAAA.step
eda/psycho_sao/3d_models/BatteryHolder_2468_2xAAA.step
eda/psycho_sao/3d_models/Battery_Holder_3xAAA_Simple.step
eda/psycho_sao/3d_models/Battery_Holder_CR2032_BS-2-1.stp
eda/psycho_sao/3d_models/CP_Radial_D5.0mm_P2.00mm.step
eda/psycho_sao/3d_models/CP_Radial_D6.3mm_P2.50mm.step
eda/psycho_sao/3d_models/CUI_PXO7803-500-M-TR.step
eda/psycho_sao/3d_models/C_0805_2012Metric.step
eda/psycho_sao/3d_models/C_1206_3216Metric.step
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

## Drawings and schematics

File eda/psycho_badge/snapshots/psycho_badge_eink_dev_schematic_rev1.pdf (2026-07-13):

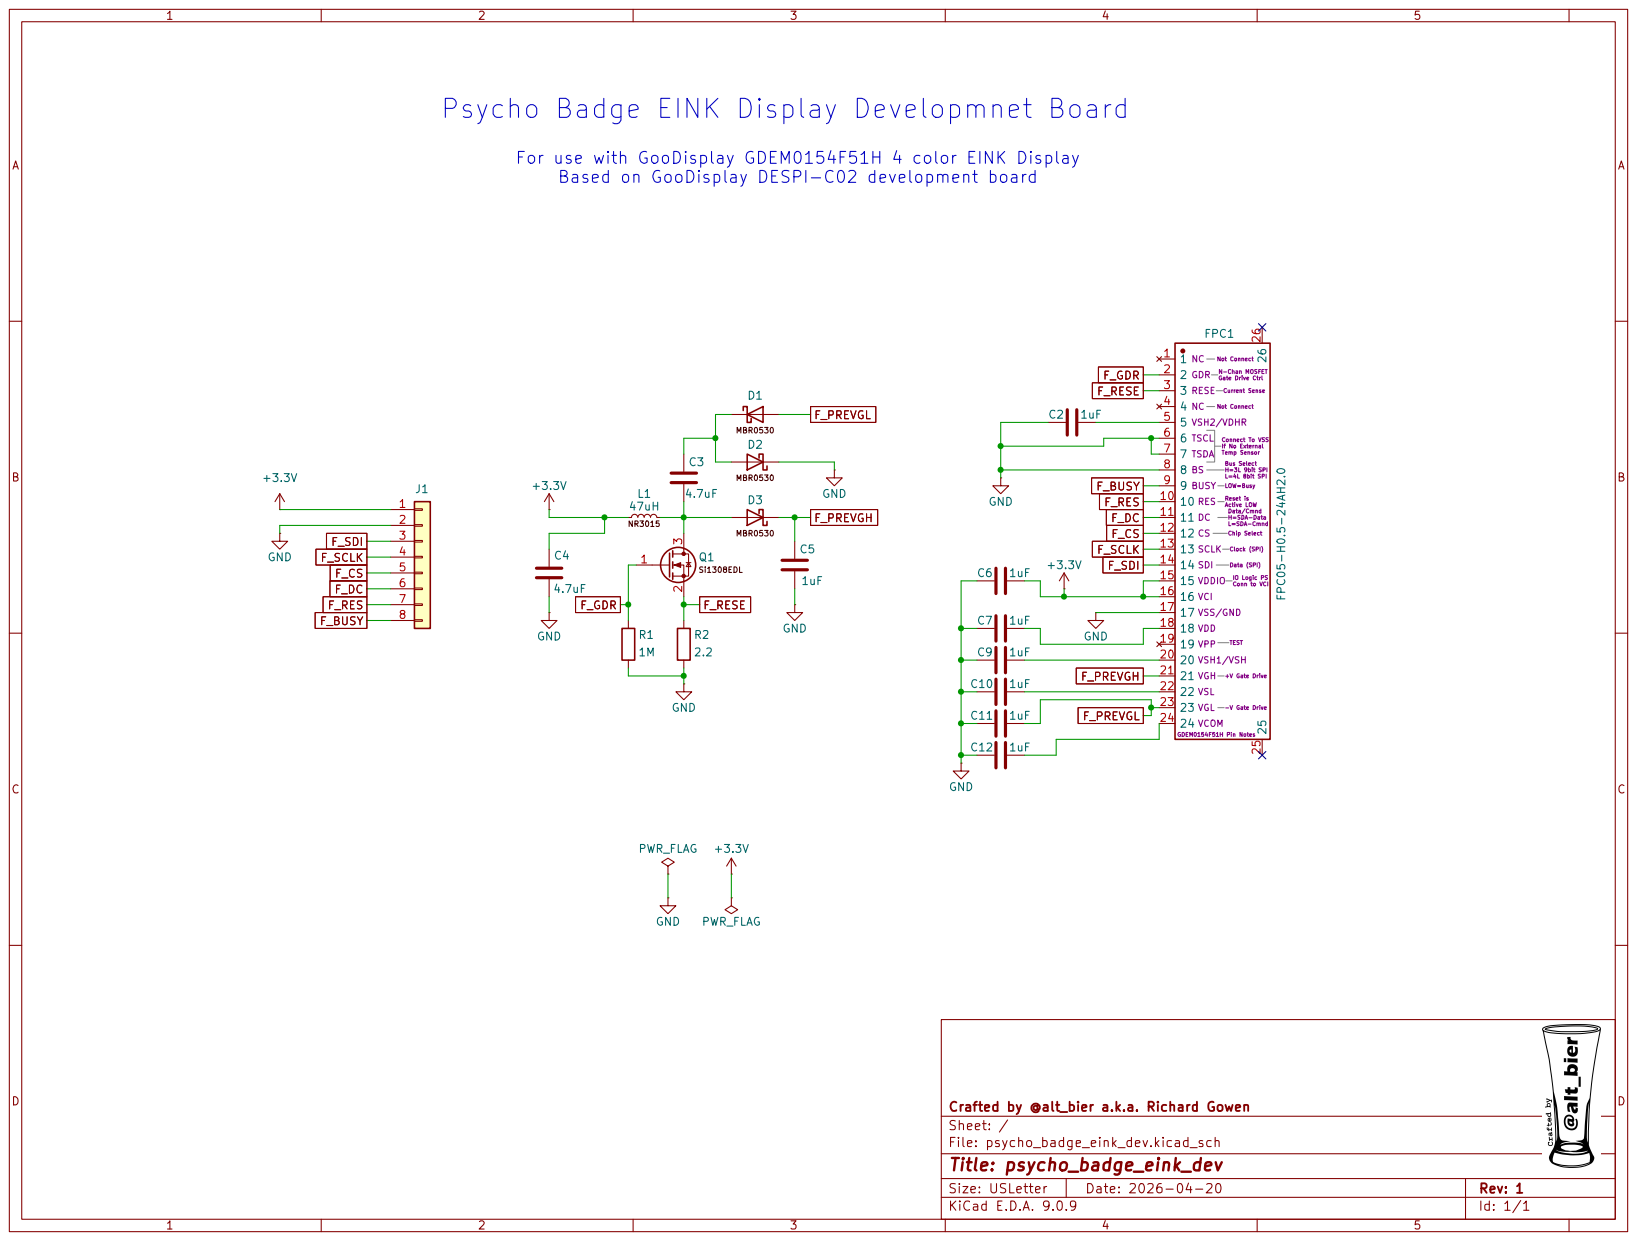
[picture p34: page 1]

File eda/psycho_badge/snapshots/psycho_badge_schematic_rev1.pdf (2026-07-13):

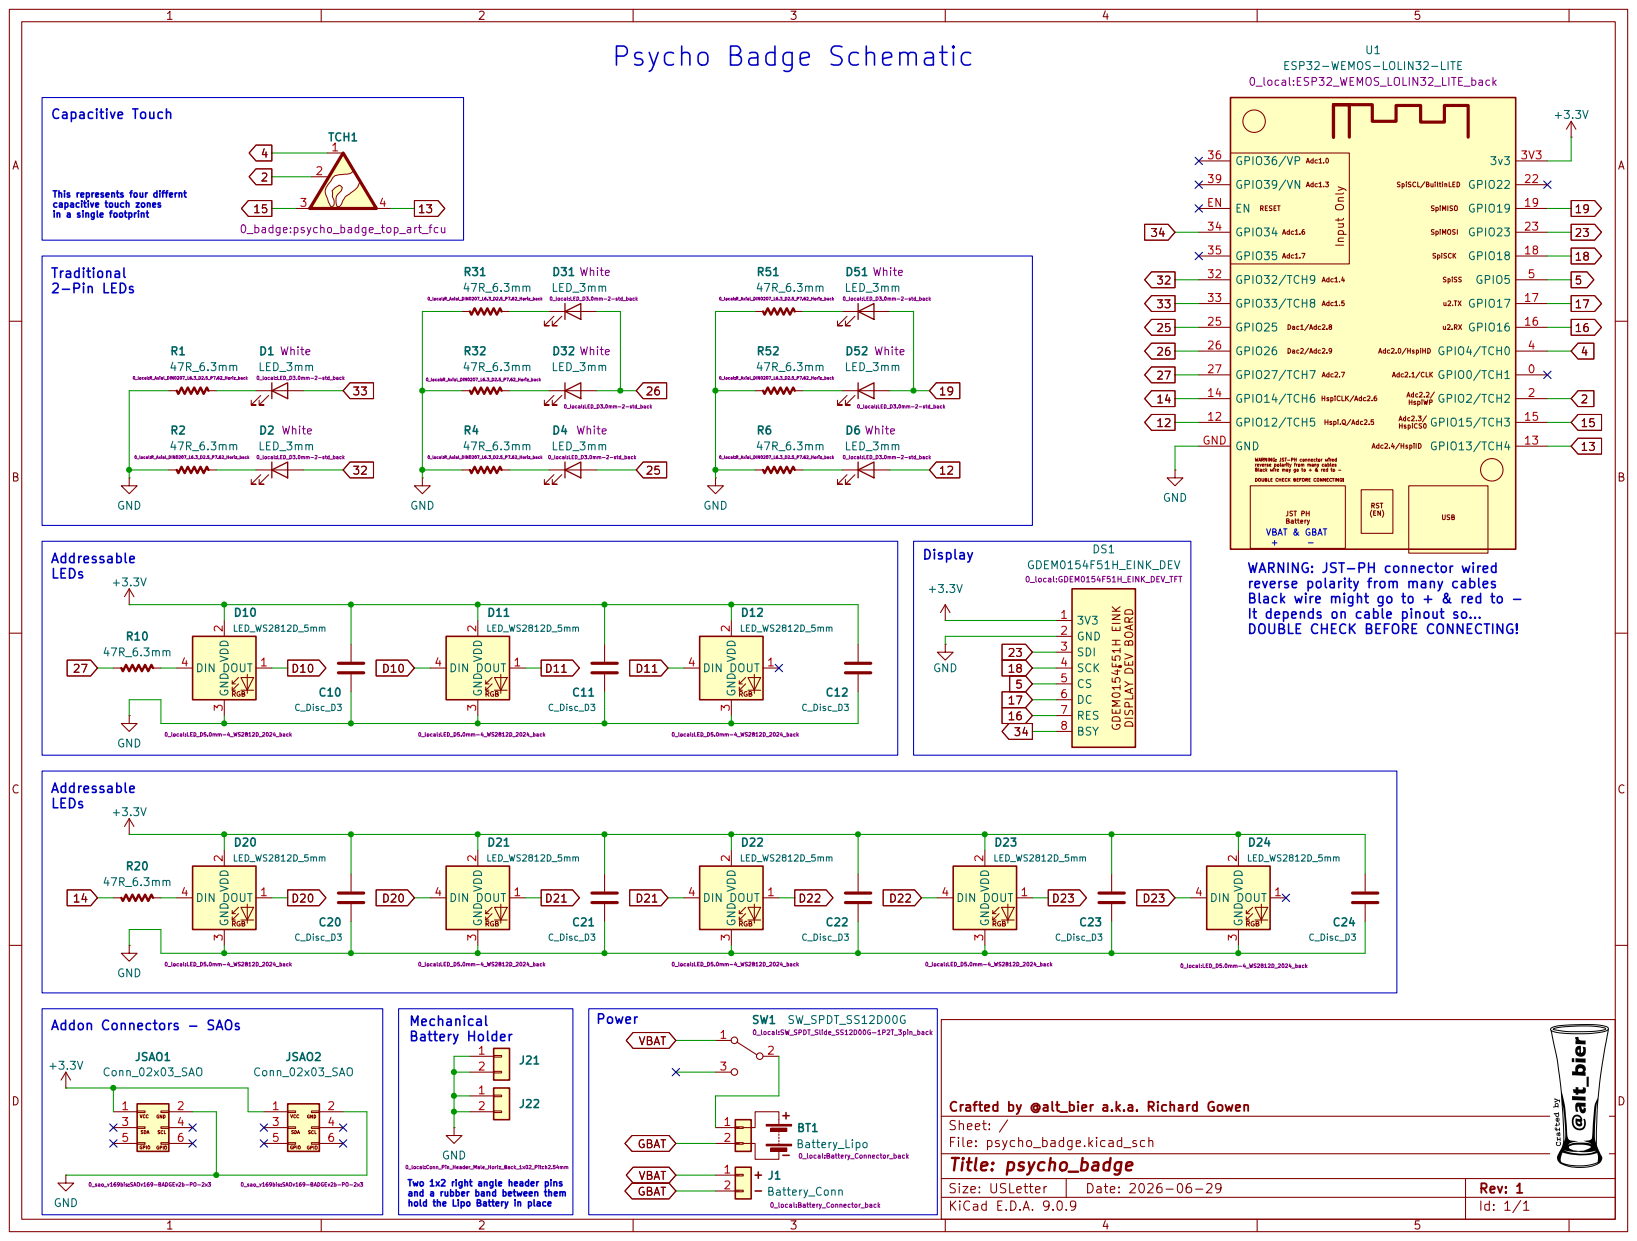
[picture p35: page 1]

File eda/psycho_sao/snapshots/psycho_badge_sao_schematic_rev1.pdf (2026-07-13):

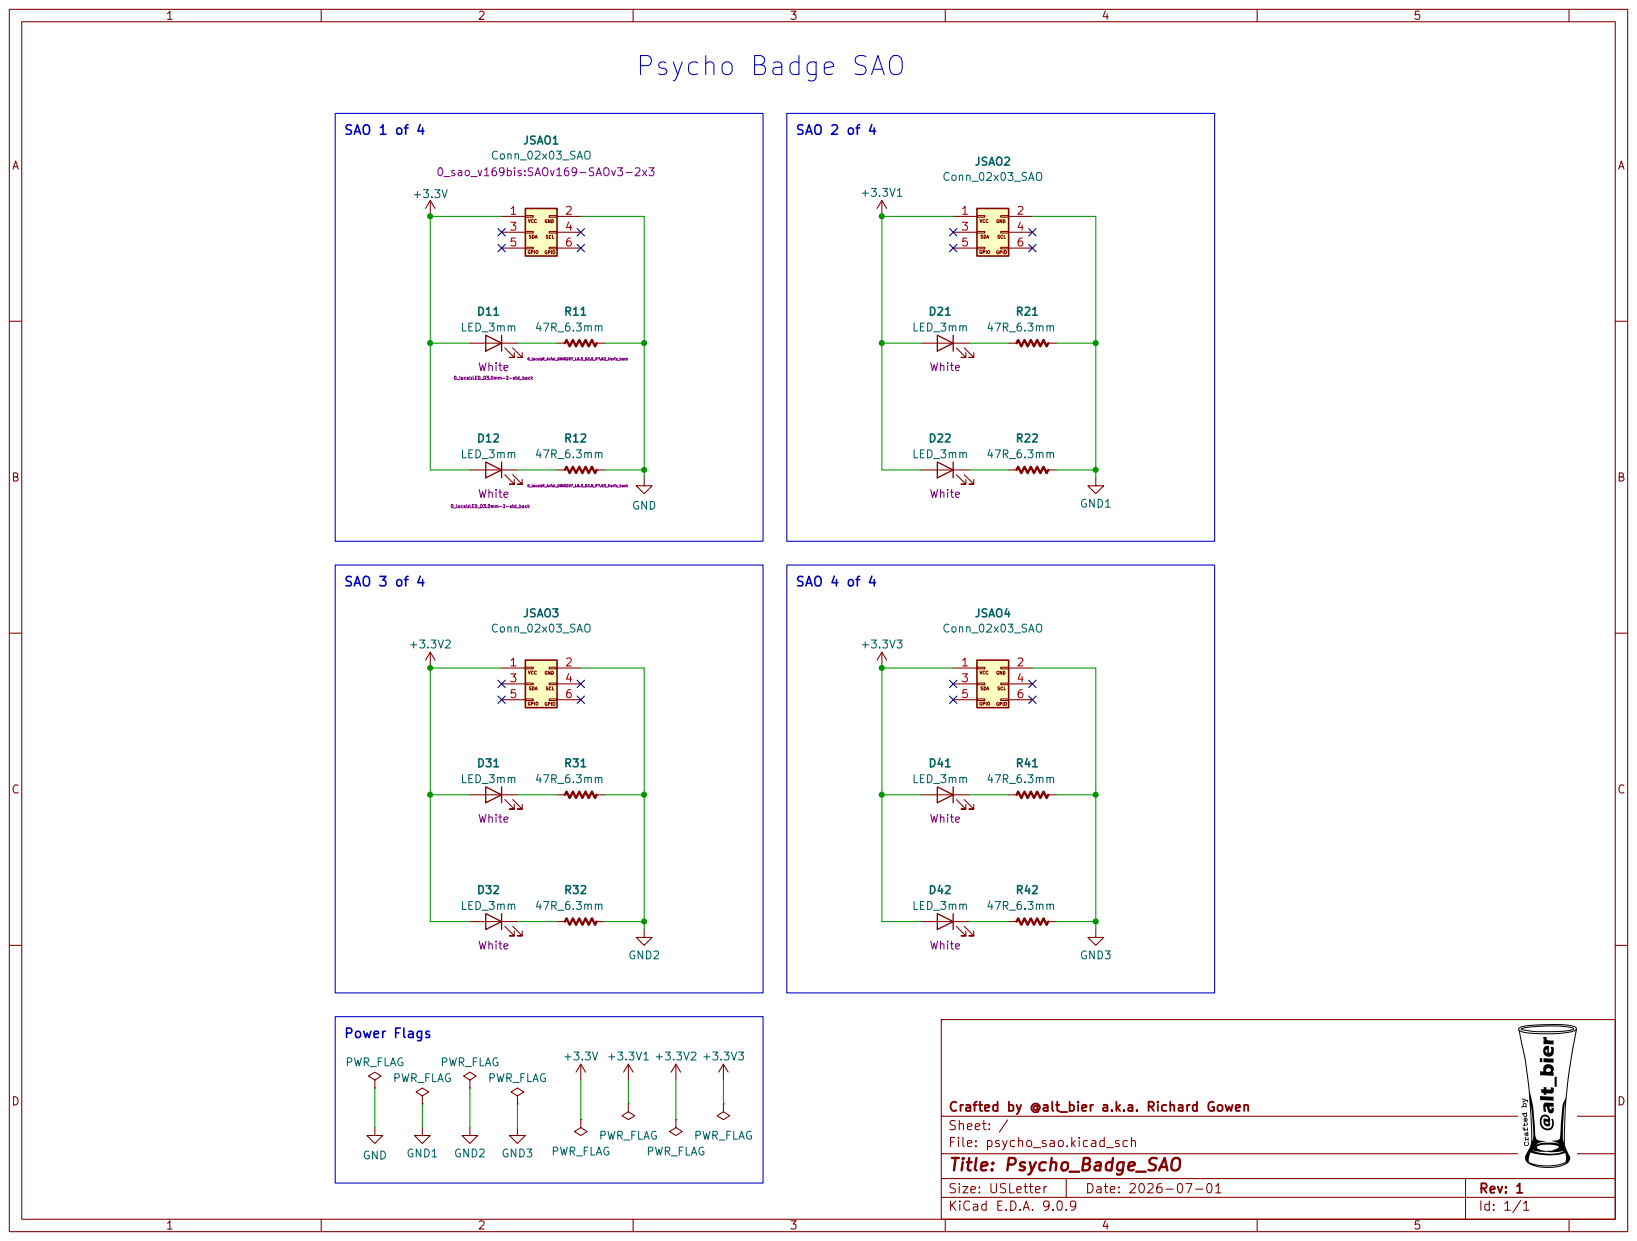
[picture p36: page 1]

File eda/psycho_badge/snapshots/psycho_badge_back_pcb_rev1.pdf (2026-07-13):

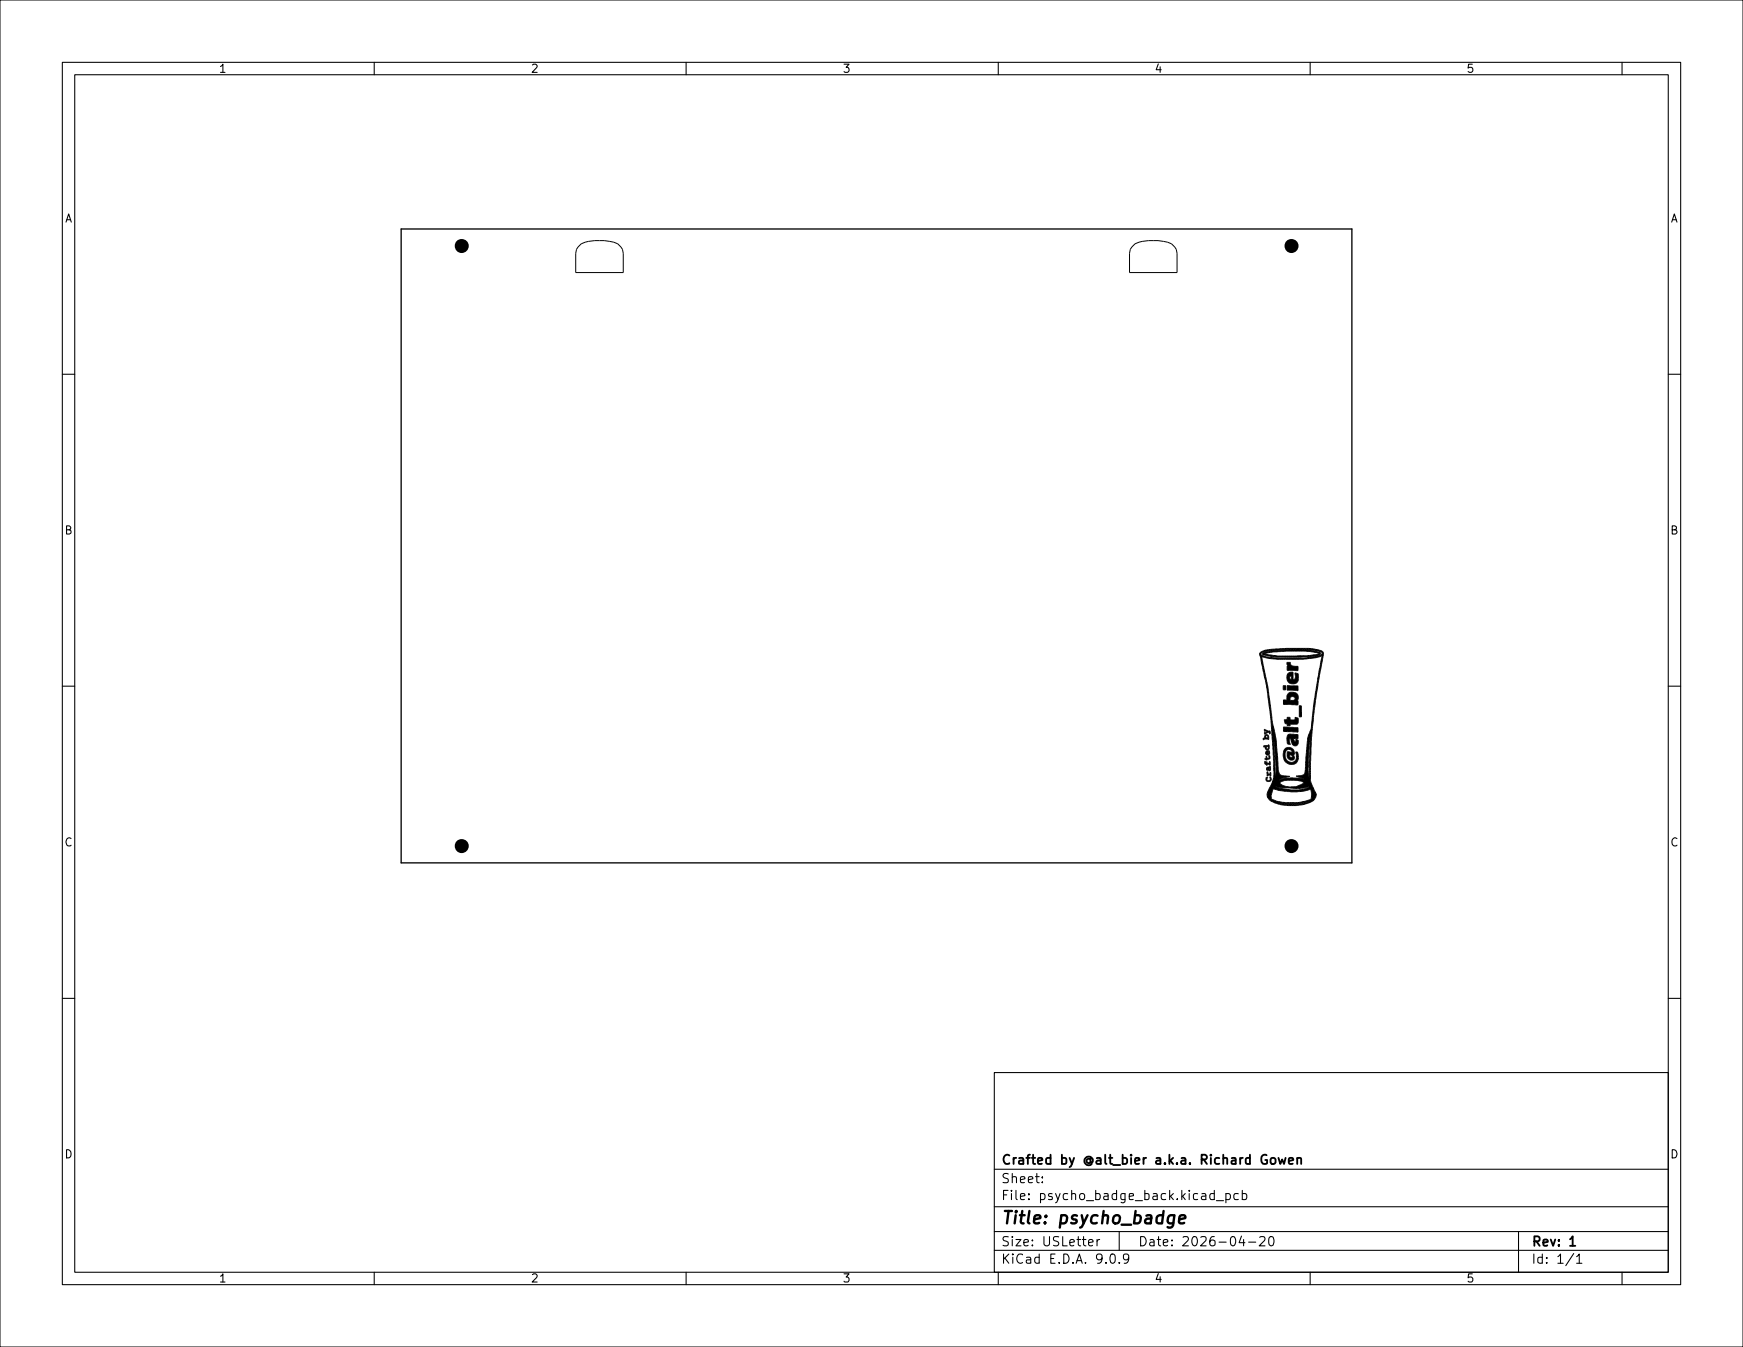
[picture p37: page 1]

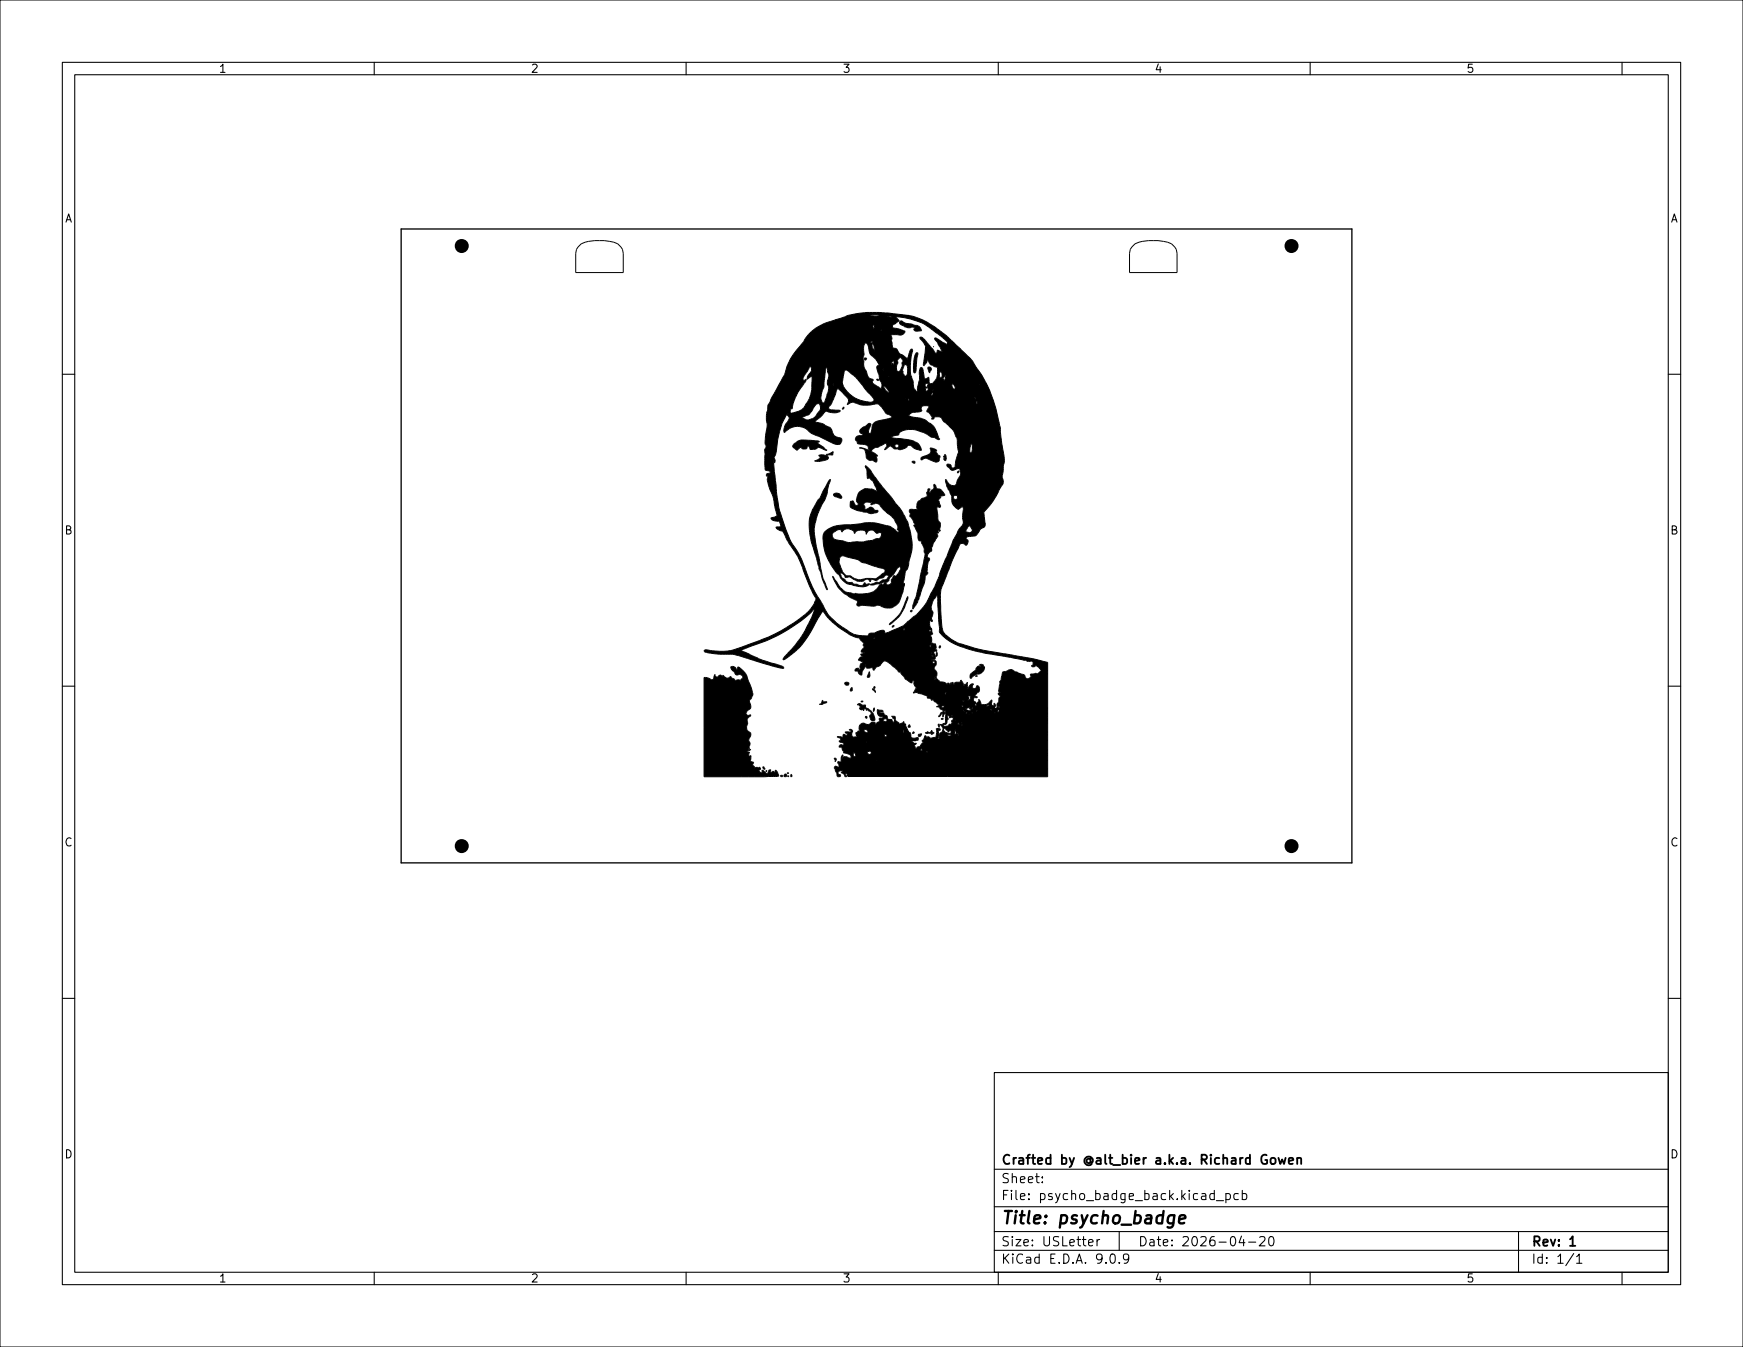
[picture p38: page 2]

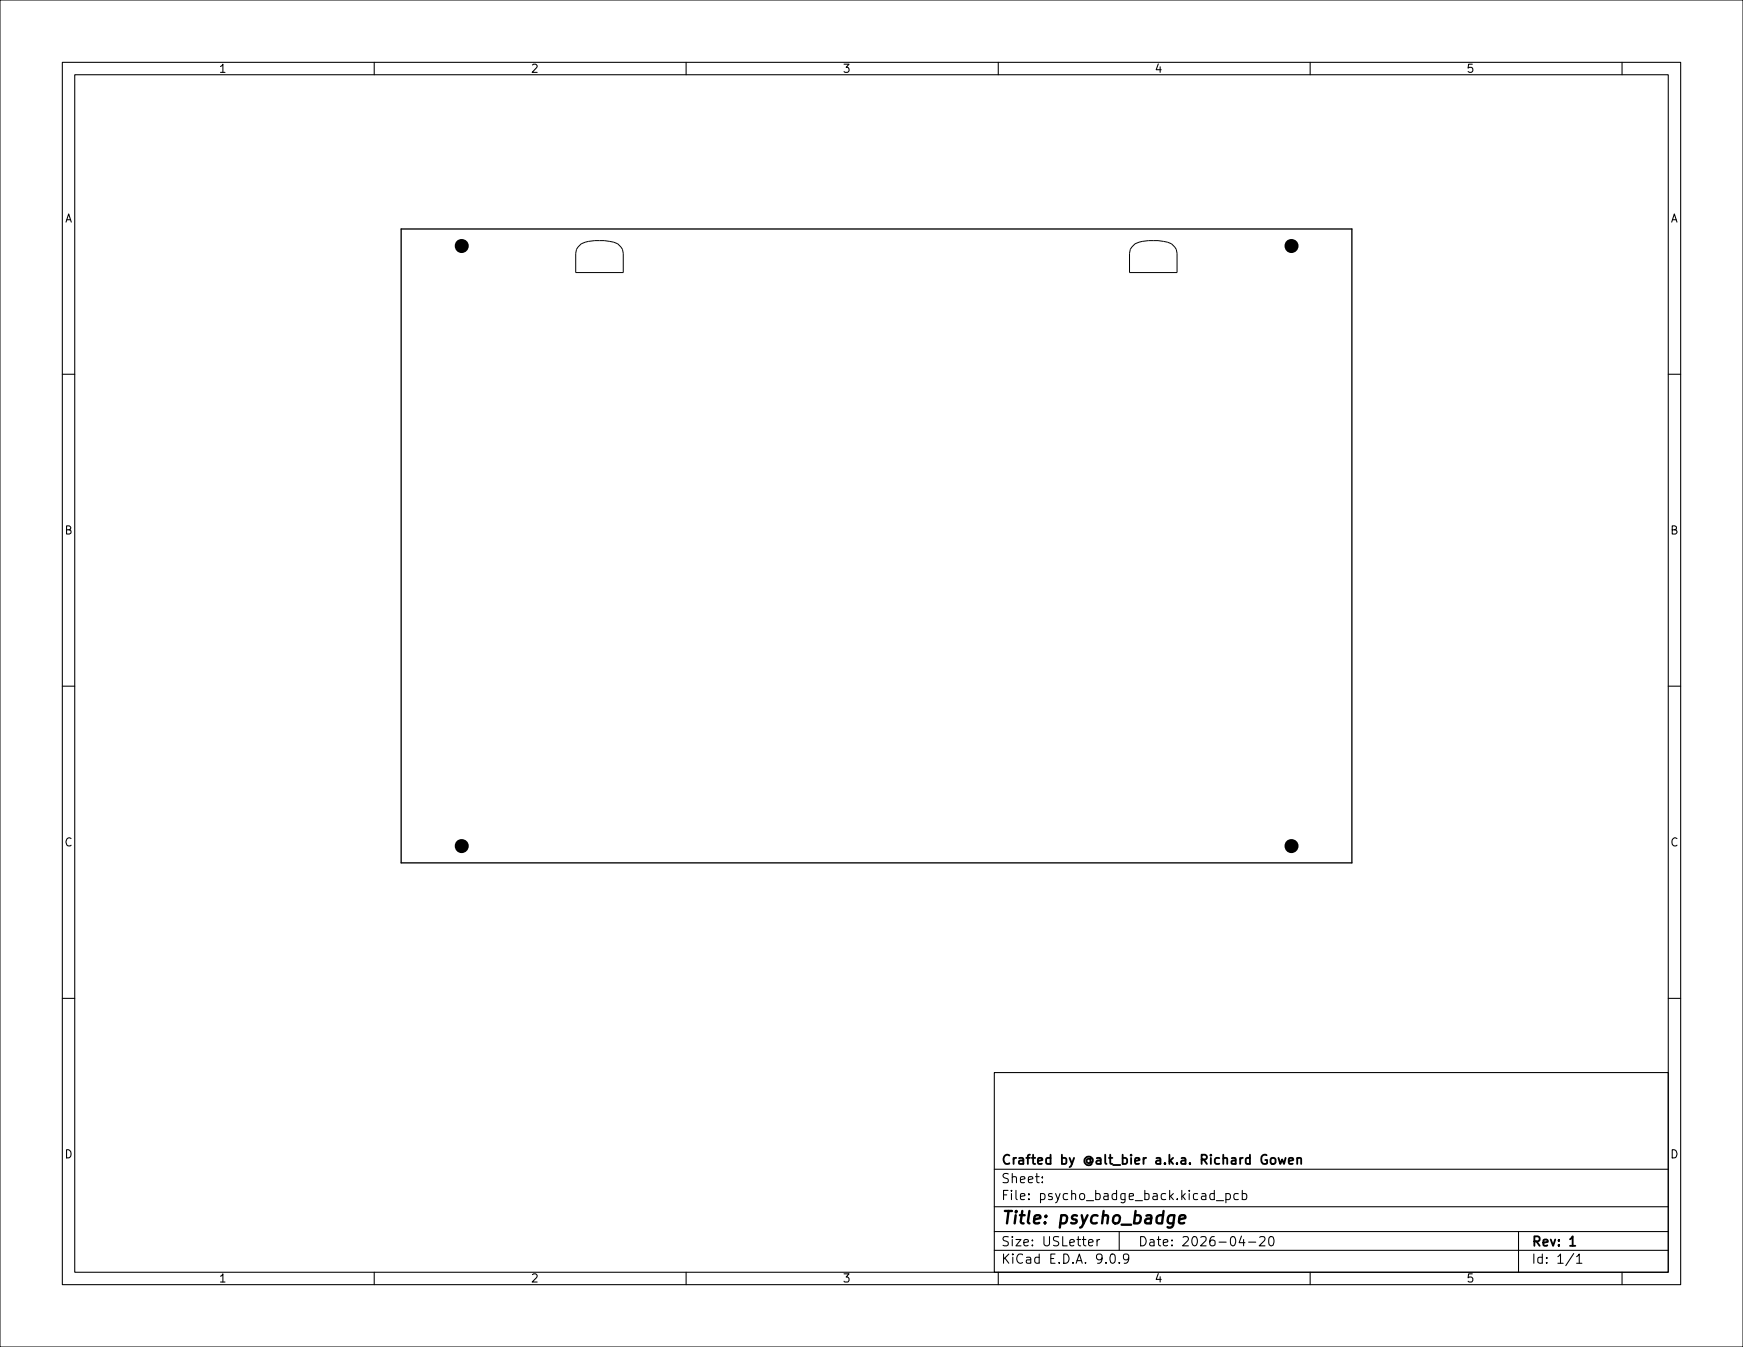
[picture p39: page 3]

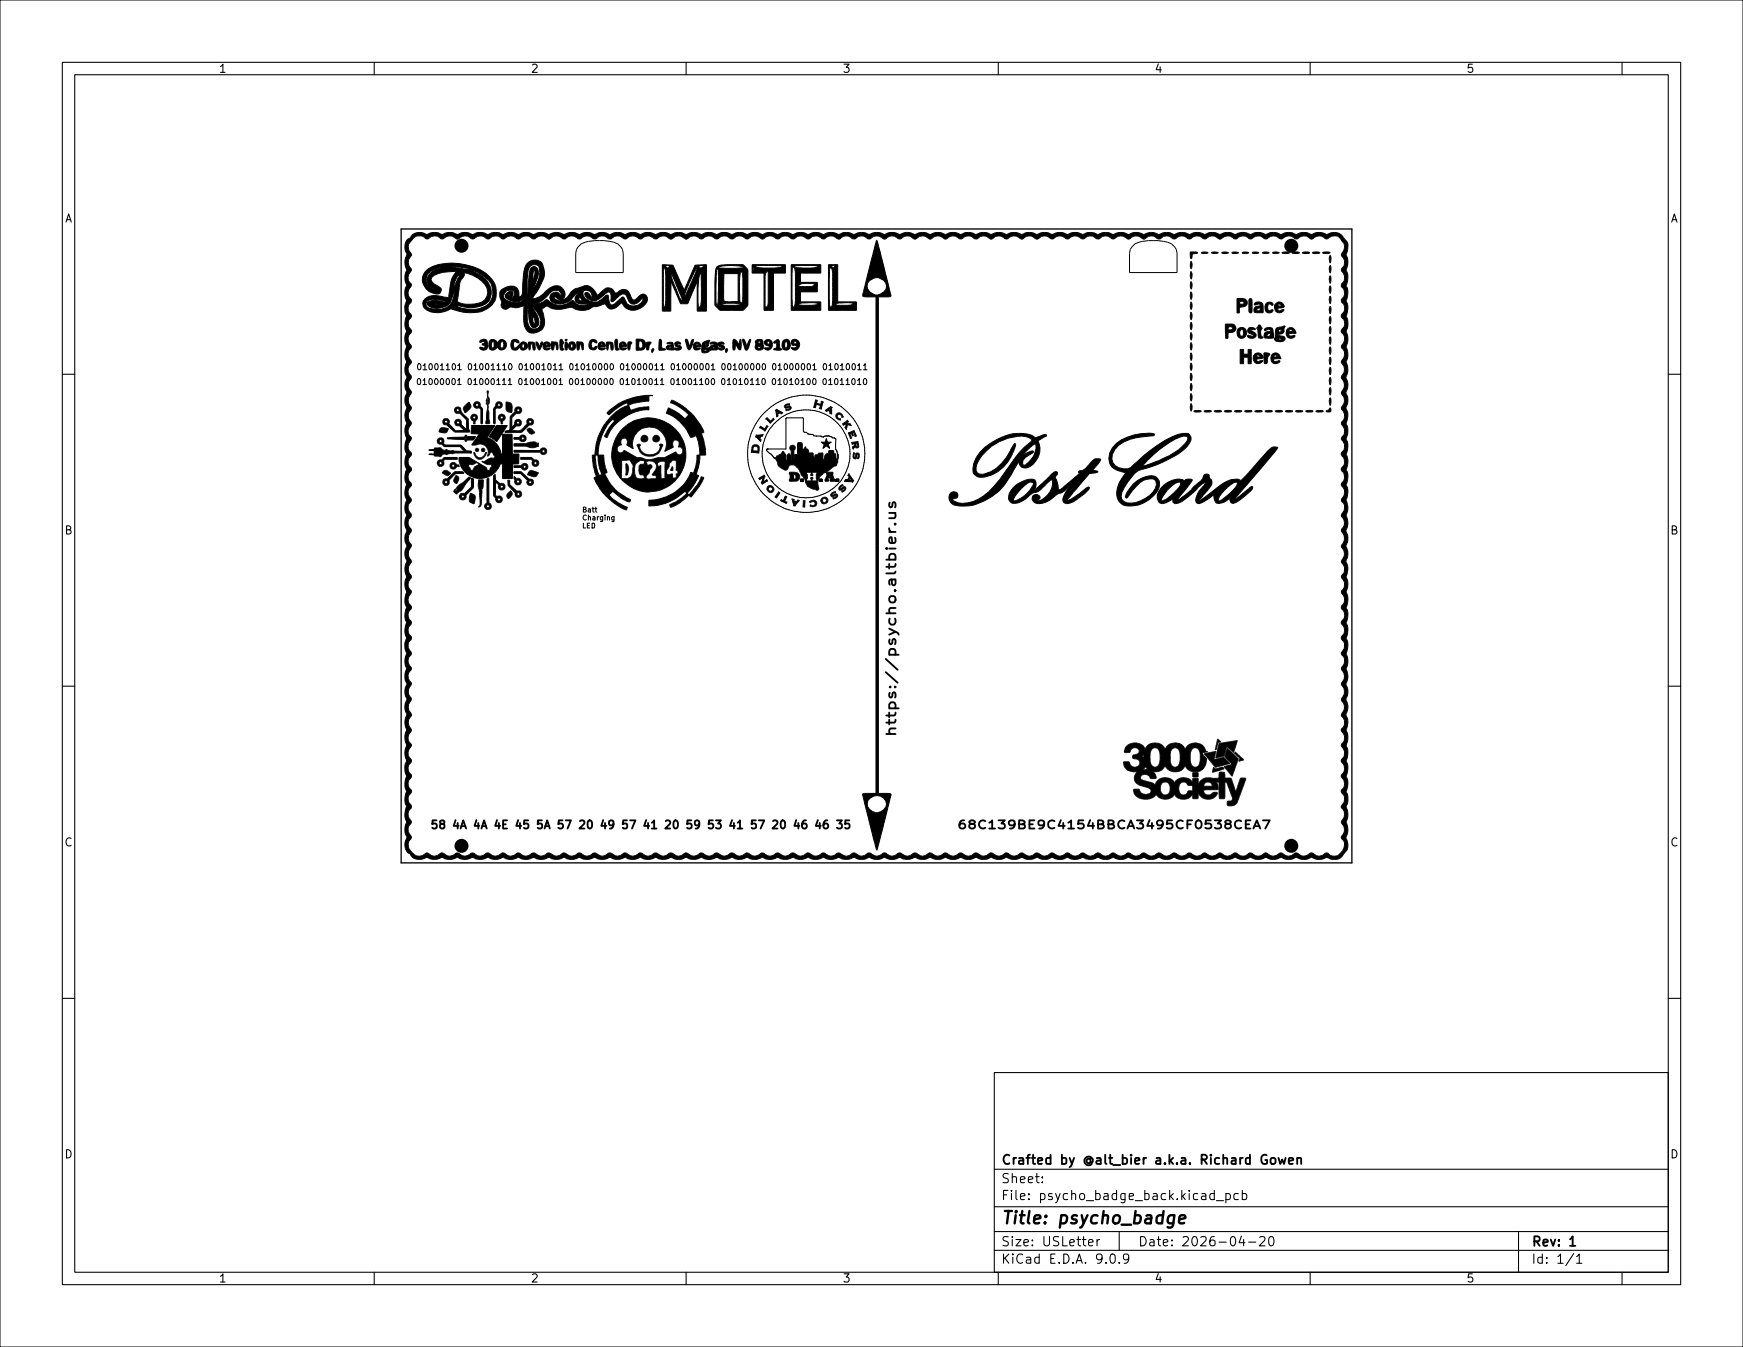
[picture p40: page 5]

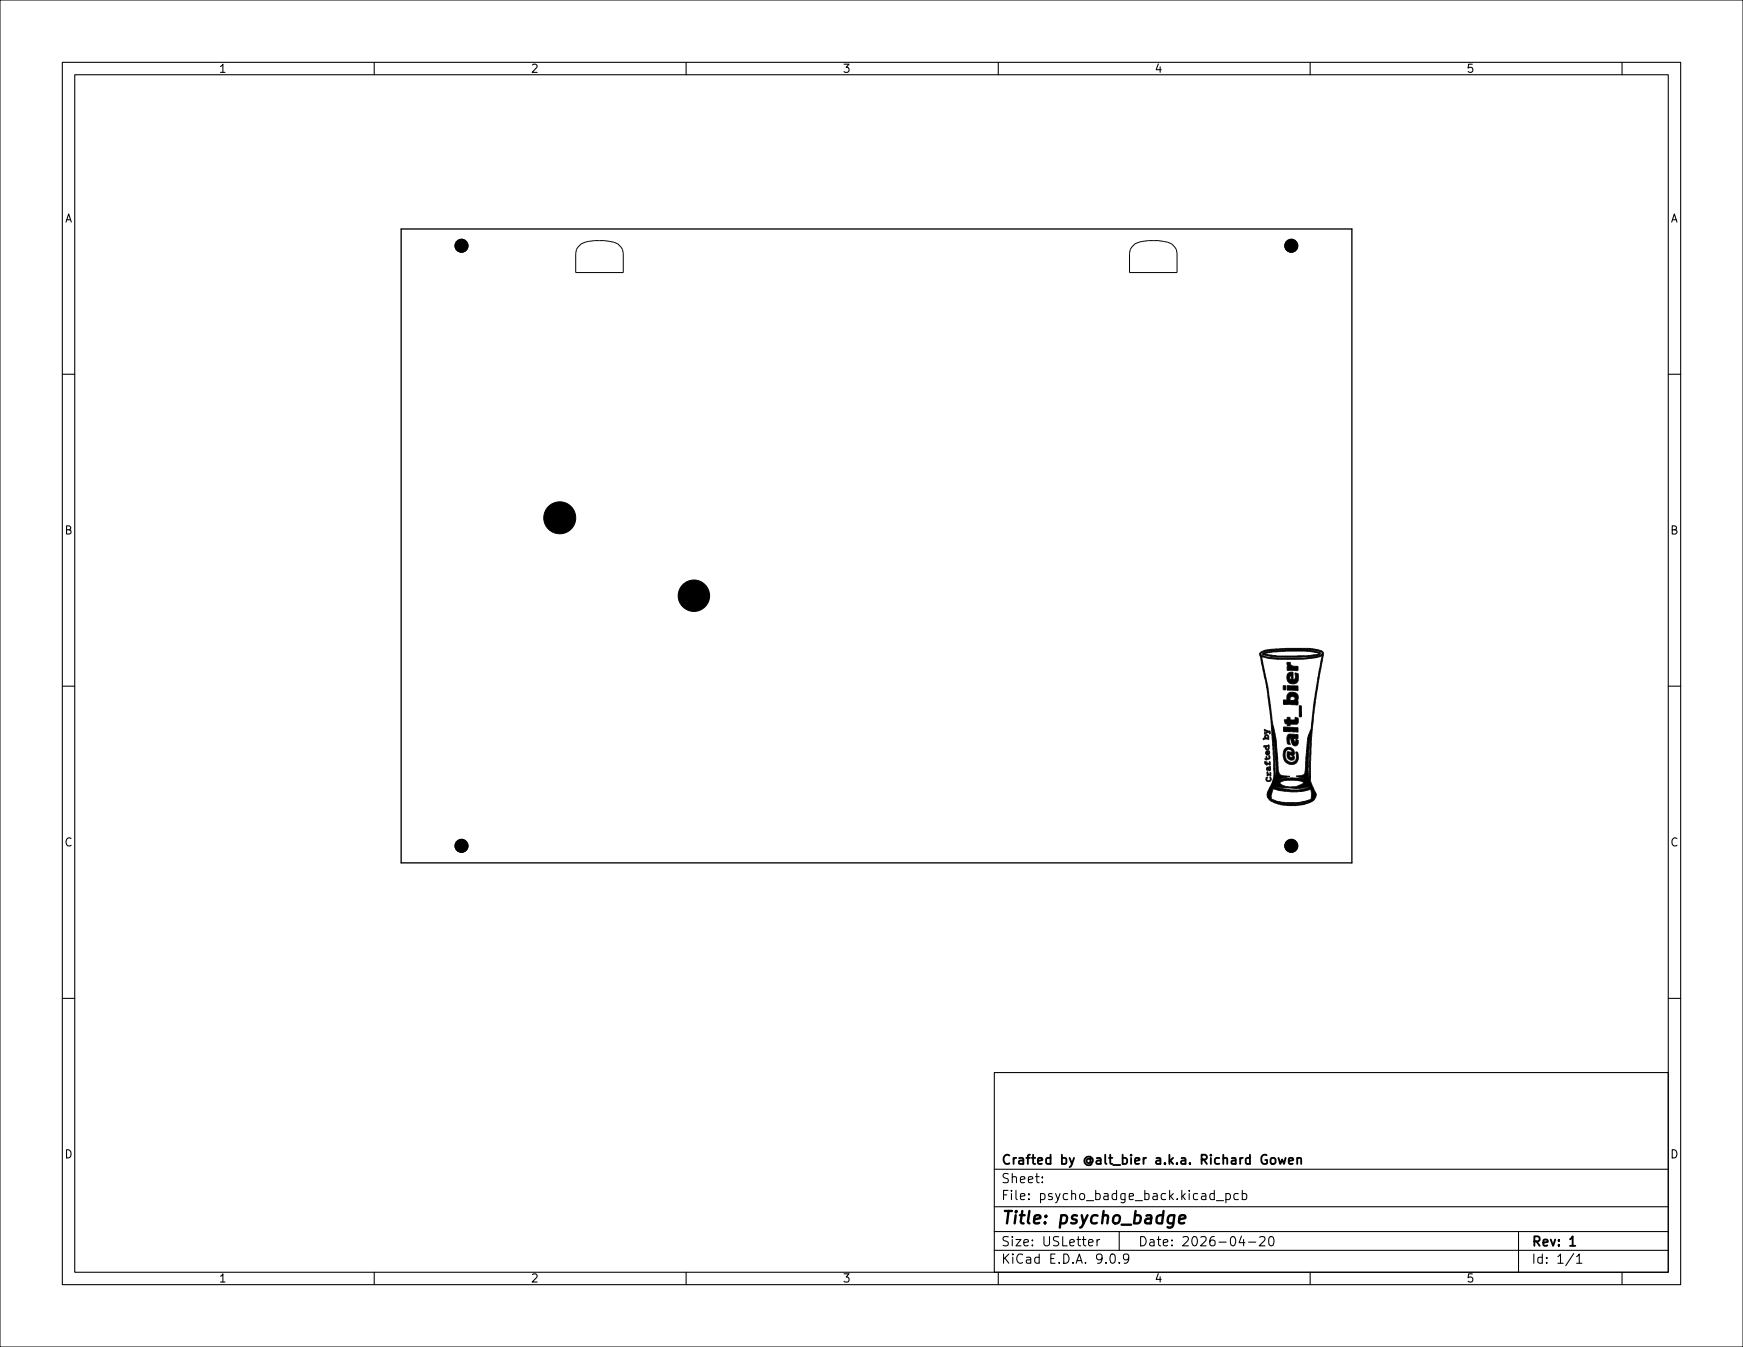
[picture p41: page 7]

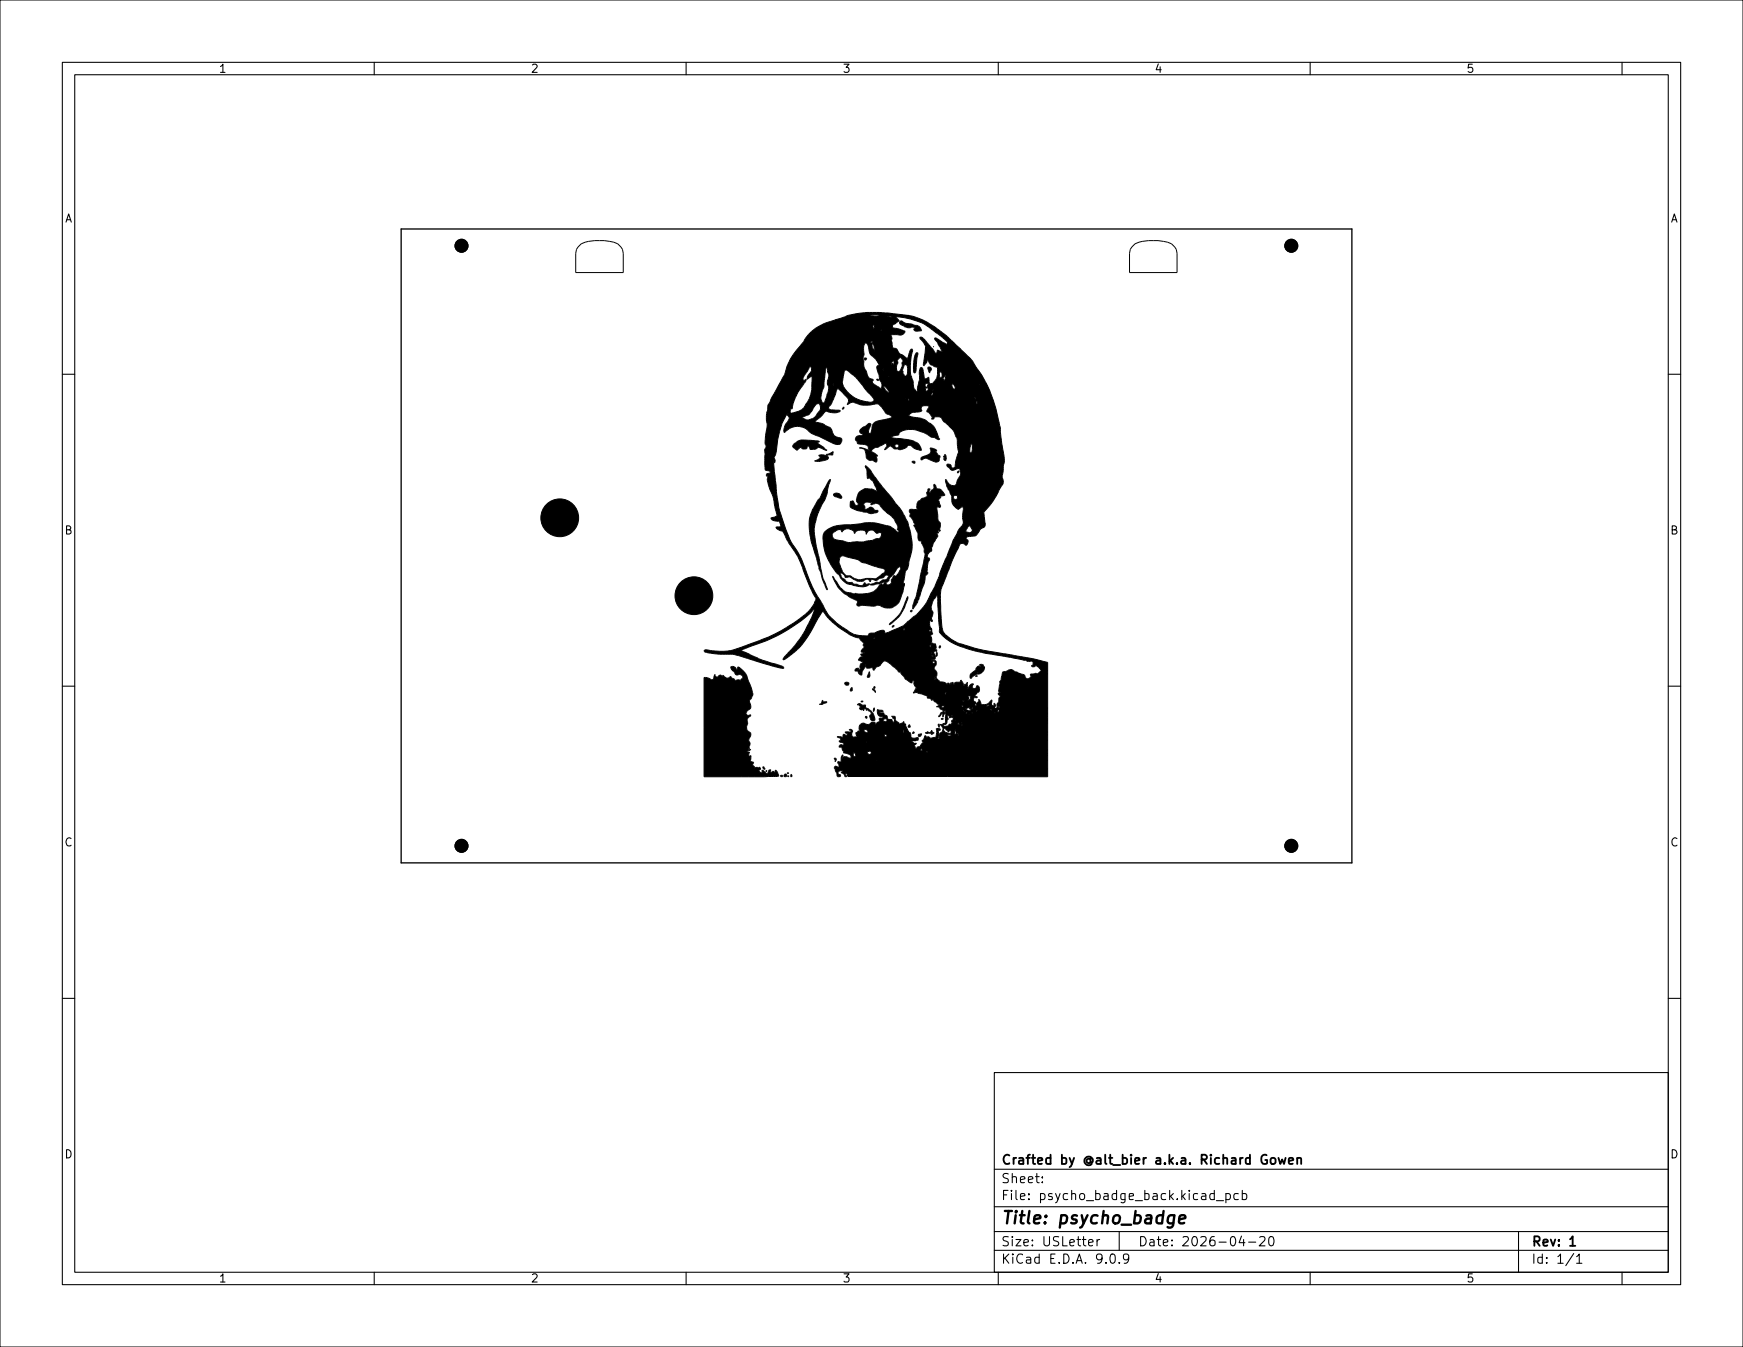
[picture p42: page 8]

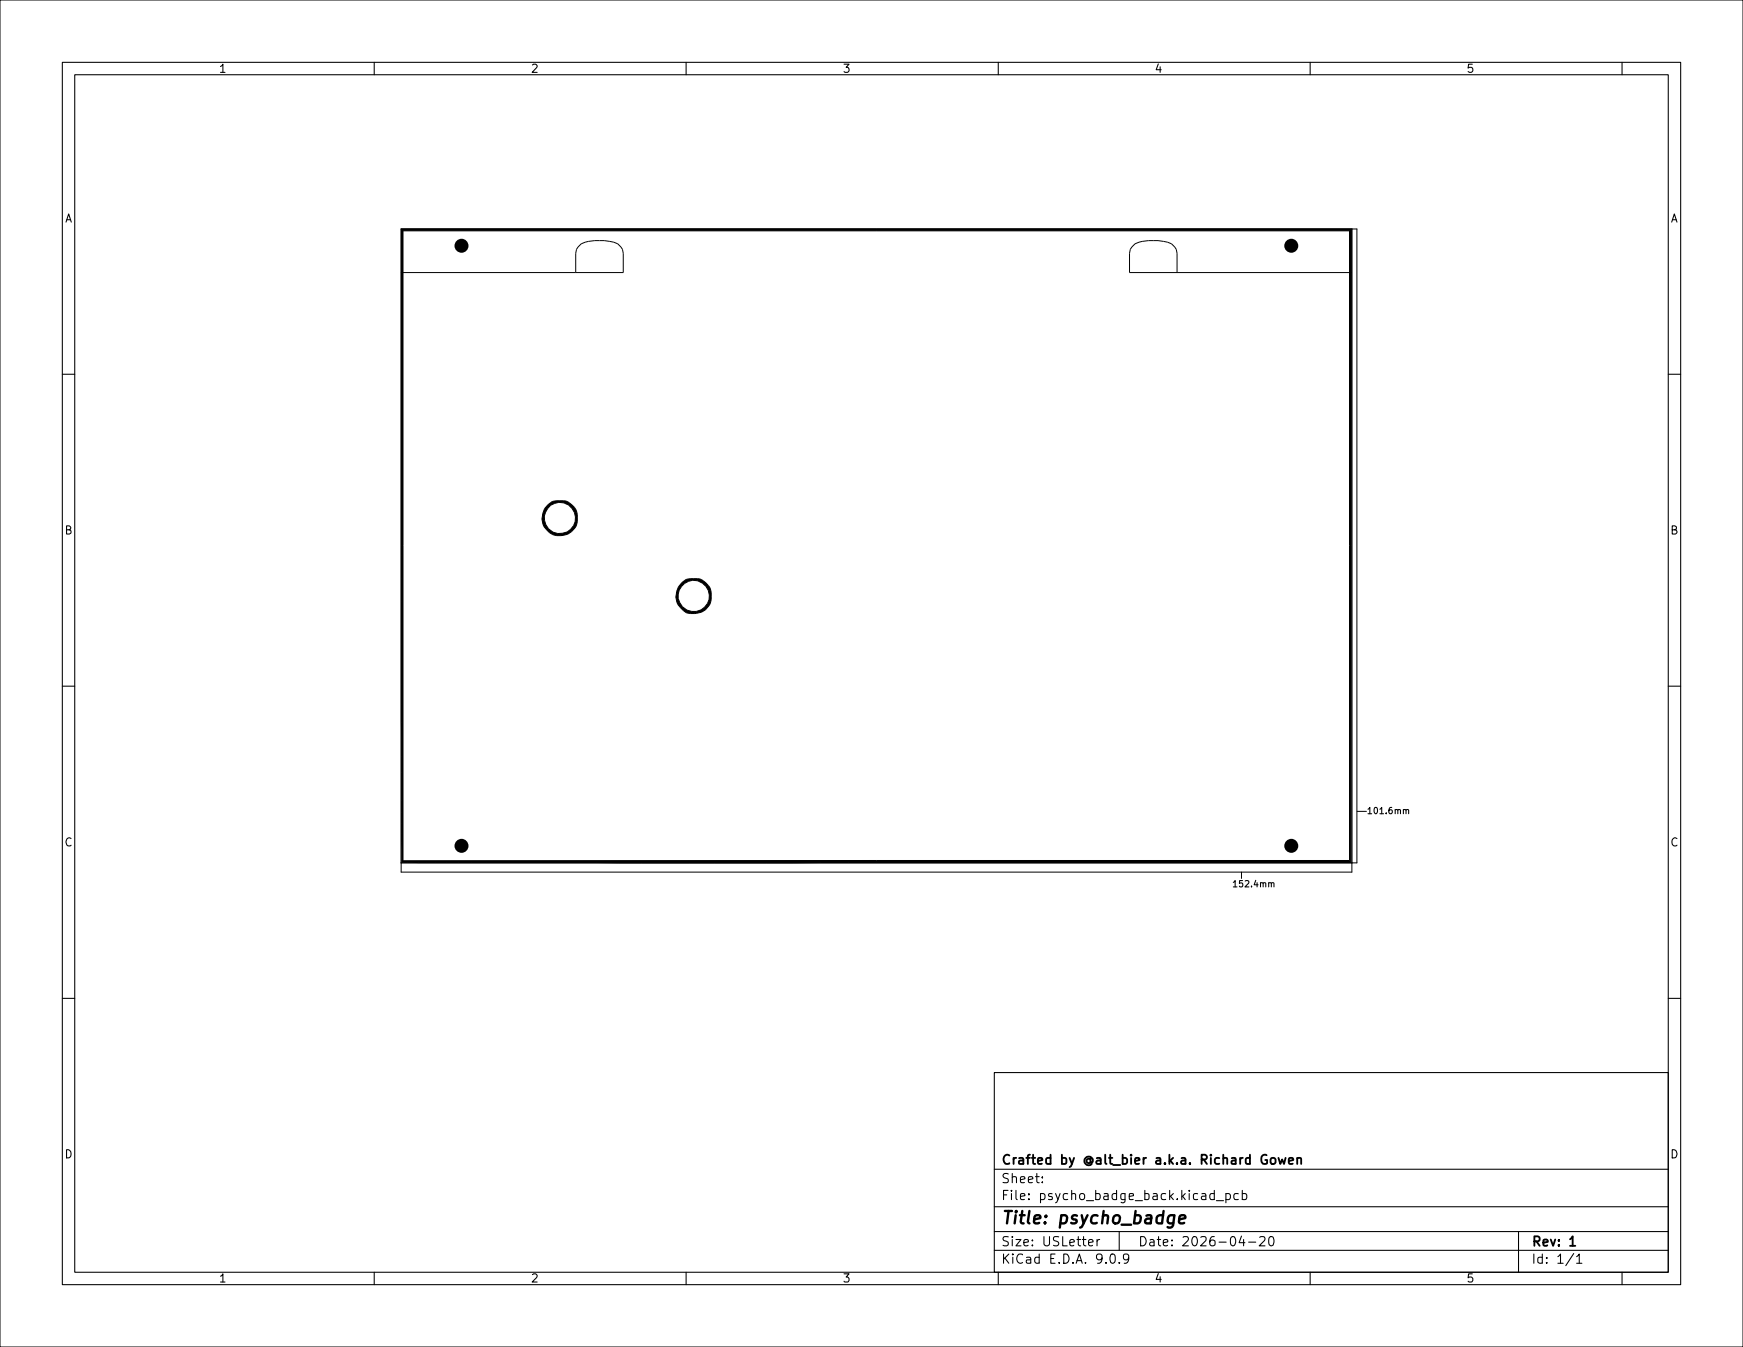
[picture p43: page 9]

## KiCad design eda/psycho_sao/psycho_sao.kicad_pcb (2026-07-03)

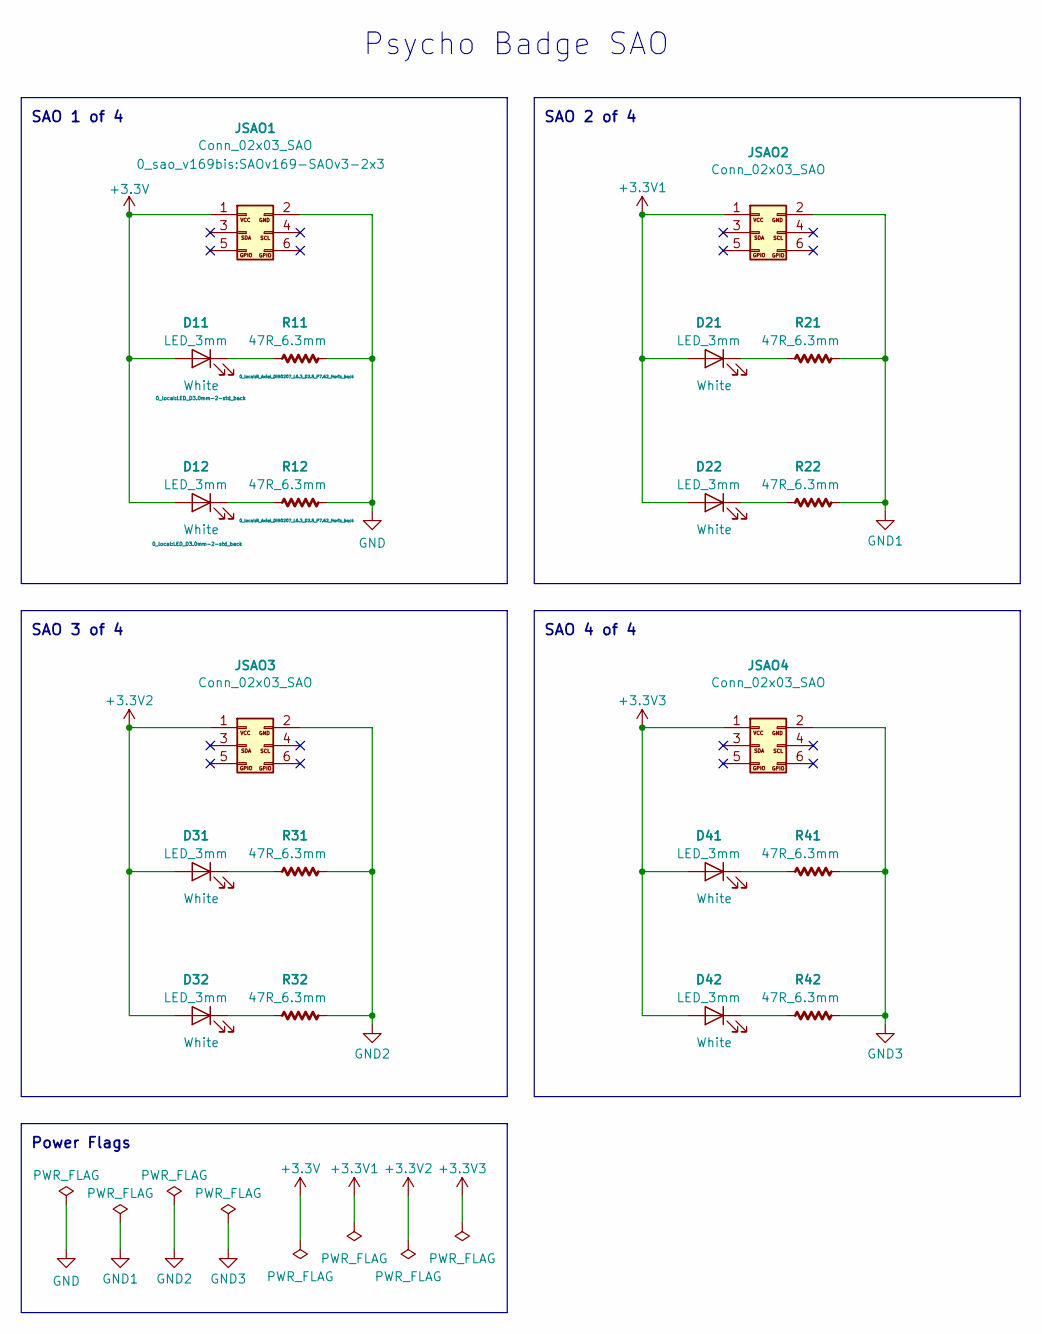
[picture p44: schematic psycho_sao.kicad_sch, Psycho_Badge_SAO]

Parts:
D11, D12, D21, D22, D31, D32, D41, D42: LED_3mm; LED_D3.0mm-2-std_back
JSAO1, JSAO2, JSAO3, JSAO4: Conn_02x03_SAO; SAOv169-SAOv3-2x3
R11, R12, R21, R22, R31, R32, R41, R42: 47R_6.3mm; R_Axial_DIN0207_L6.3_D2.5_P7.62_Horiz_back

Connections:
+3.3V: D11.2 (A), D12.2 (A), JSAO1.1
+3.3V1: D21.2 (A), D22.2 (A), JSAO2.1
+3.3V2: D31.2 (A), D32.2 (A), JSAO3.1
+3.3V3: D41.2 (A), D42.2 (A), JSAO4.1
GND: JSAO1.2, R11.2, R12.2
GND1: JSAO2.2, R21.2, R22.2
GND2: JSAO3.2, R31.2, R32.2
GND3: JSAO4.2, R41.2, R42.2
unnamed: D11.1 (K), R11.1
unnamed: D12.1 (K), R12.1
unnamed: D21.1 (K), R21.1
unnamed: D22.1 (K), R22.1
unnamed: D31.1 (K), R31.1
unnamed: D32.1 (K), R32.1
unnamed: D41.1 (K), R41.1
unnamed: D42.1 (K), R42.1

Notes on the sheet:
SAO 1 of 4
SAO 4 of 4
Psycho Badge SAO
Power Flags
SAO 3 of 4
SAO 2 of 4

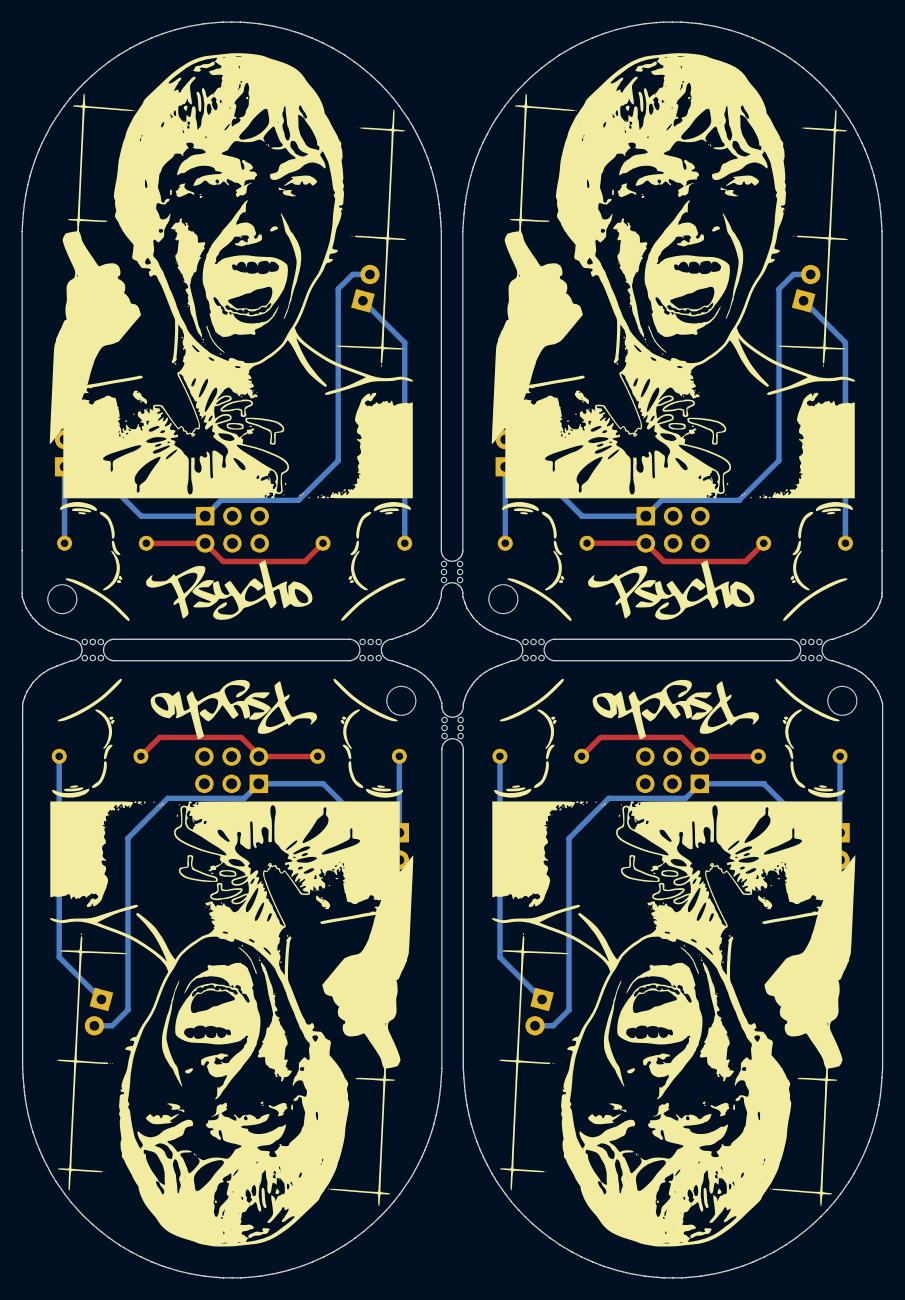
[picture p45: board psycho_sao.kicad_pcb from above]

Board: 2 copper layers, 80.2 x 117.1 mm, 33 parts (0 on the bottom side), 16 nets.

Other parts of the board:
Fold: LED_Fold_Indicator_1; LED_Fold_Indicator_back
Fold#2, Fold#3, Fold#4, Fold#5, Fold#6, Fold#7, Fold#8: LED_Fold_Indicator_1; LED_Fold_Indicator_back
Psycho_BMask: Psycho_BMask; Scream_Face_B_Mask
Psycho_FCu: Psycho_FCu; Scream_Face_F_Cu
Psycho_FMask: Psycho_FMask; Scream_Face_F_Mask
Psycho_FSilk: Psycho_FSilk; Scream_Face_F_Silk
sao_edgecuts_02: Edge Cuts; SAO_edgecuts_02

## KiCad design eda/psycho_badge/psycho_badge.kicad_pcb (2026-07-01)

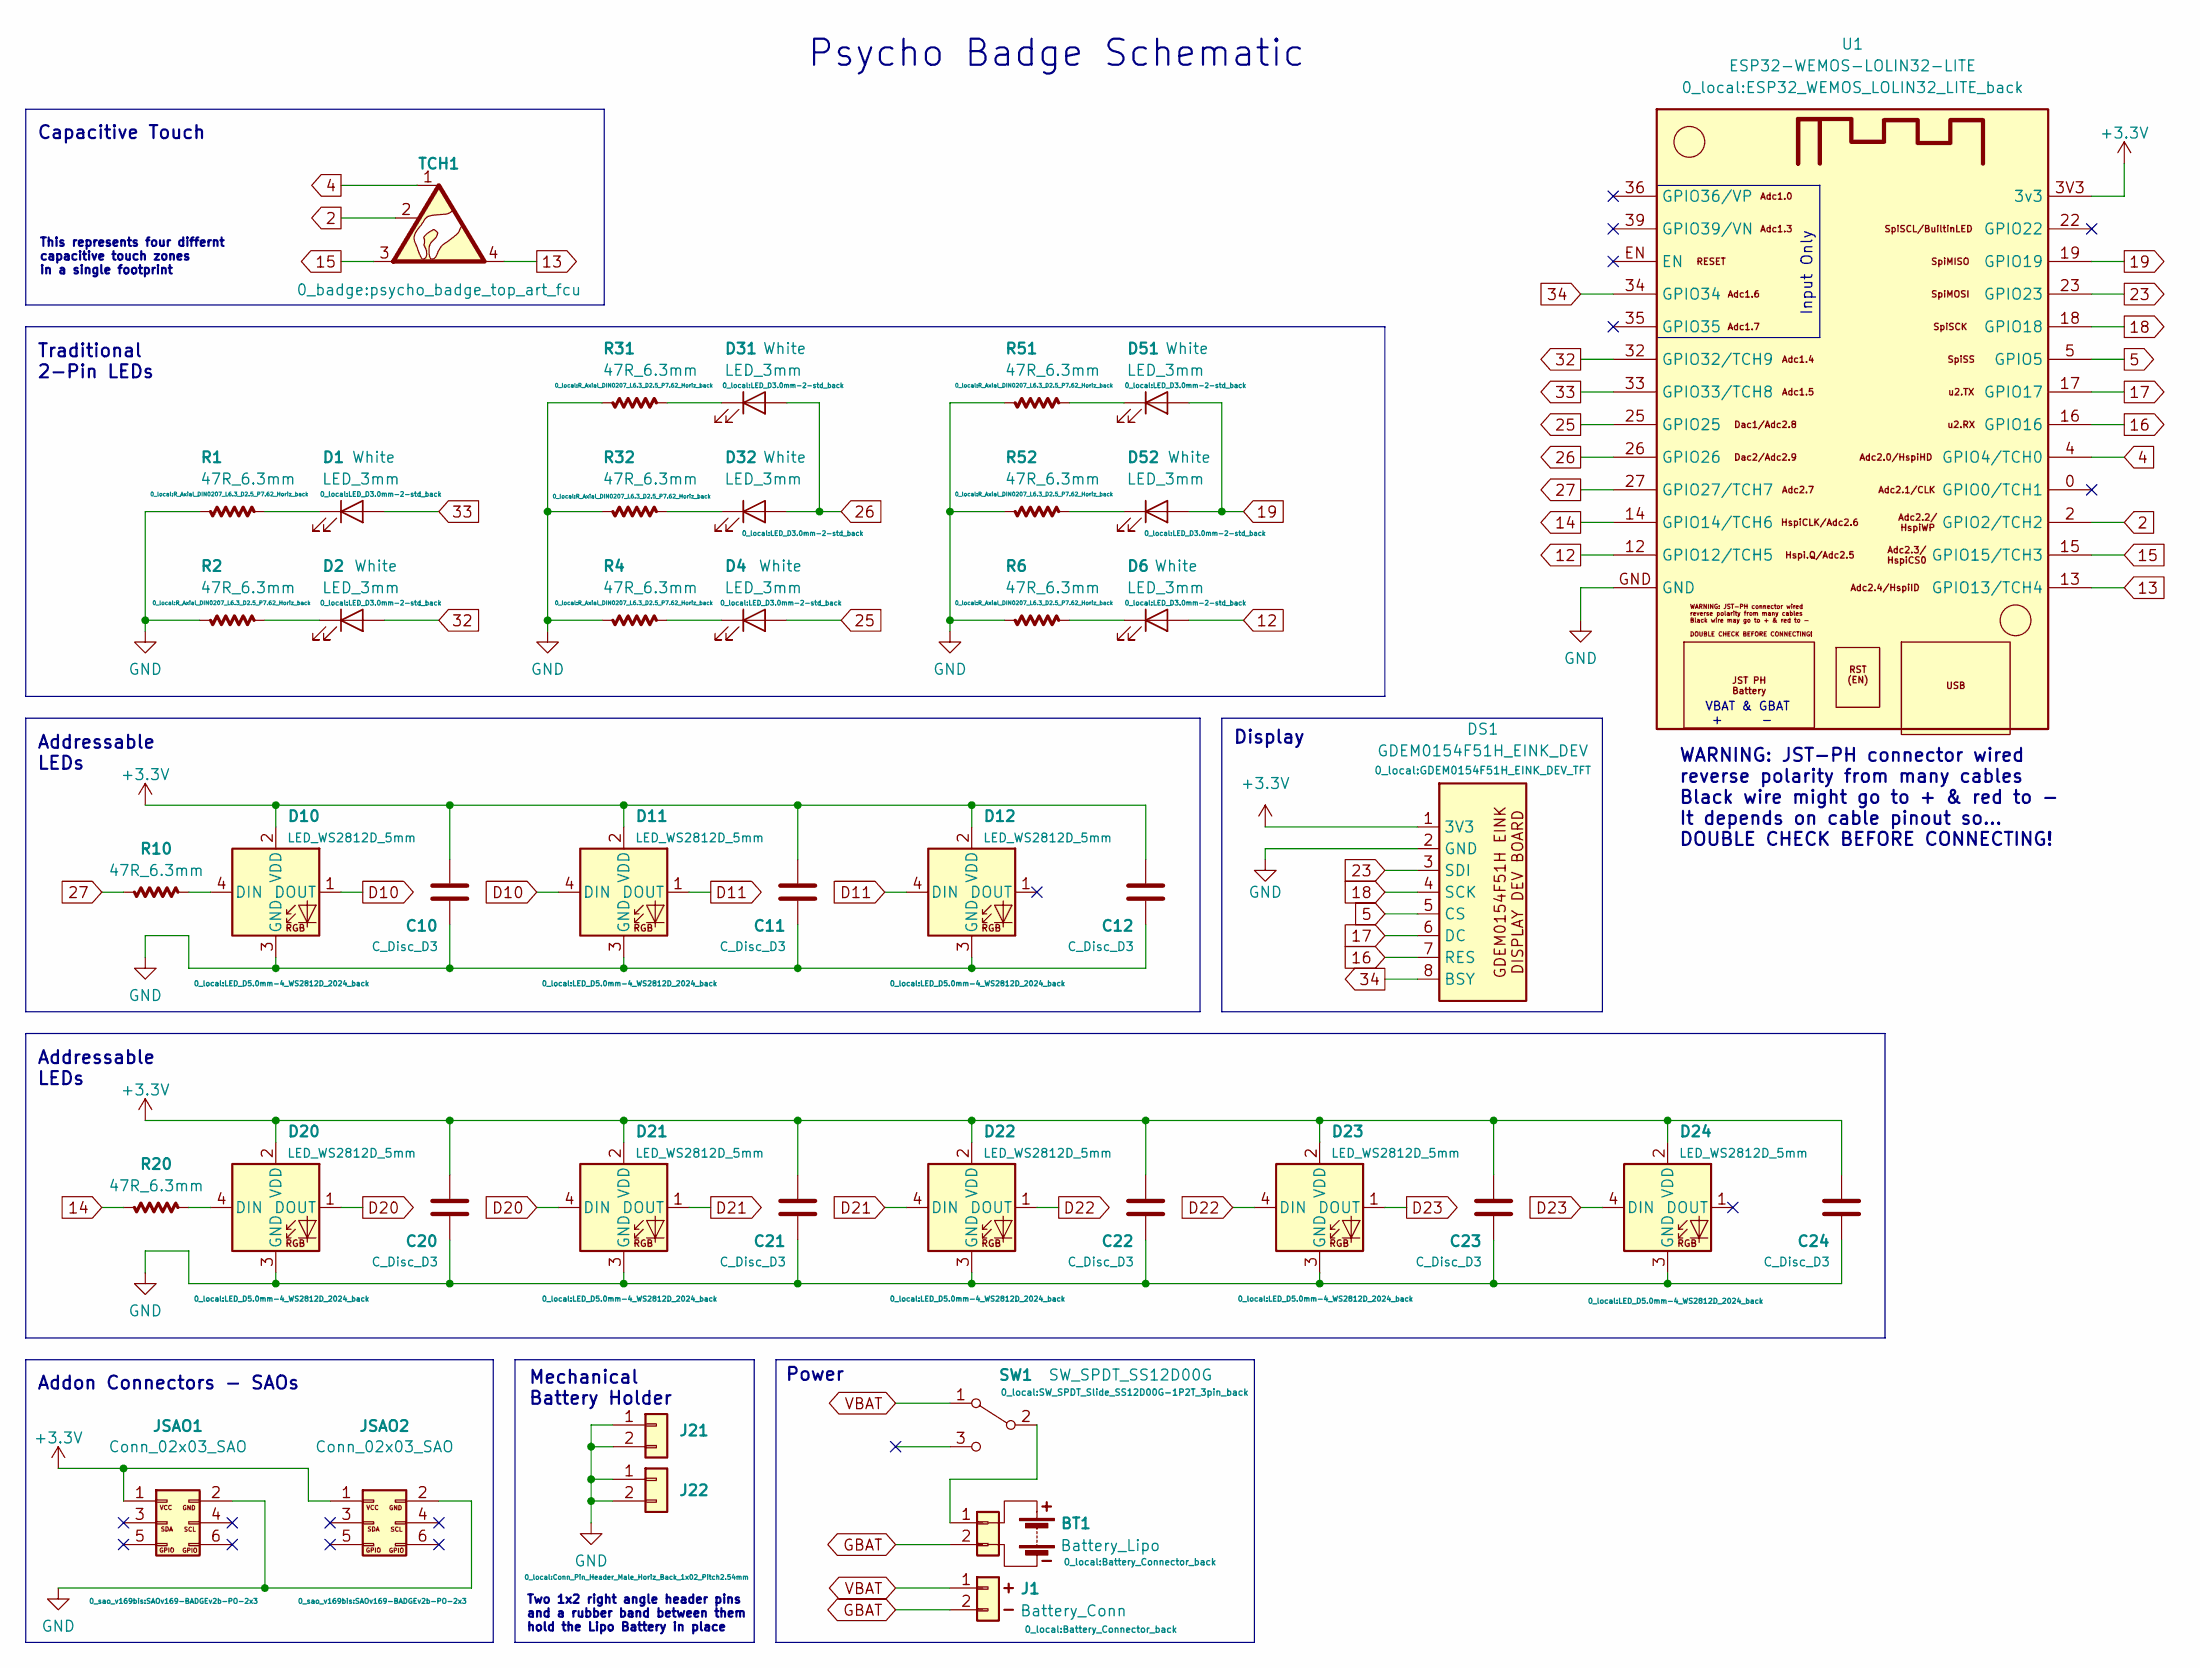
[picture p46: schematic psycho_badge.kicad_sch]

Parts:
BT1: Battery_Lipo; Battery_Connector_back
C10, C11, C12, C20, C21, C22, C23, C24: C_Disc_D3; C_Disc_D3_back
D1, D2, D4, D6, D31, D32, D51, D52: LED_3mm; LED_D3.0mm-2-std_back
D10, D11, D12, D20, D21, D22, D23, D24: LED_WS2812D_5mm; LED_D5.0mm-4_WS2812D_2024_back
DS1: GDEM0154F51H_EINK_DEV; GDEM0154F51H_EINK_DEV_TFT
J1: Battery_Conn; Battery_Connector_back
J21, J22: 01x02; Conn_Pin_Header_Male_Horiz_Back_1x02_Pitch2.54mm
JSAO1, JSAO2: Conn_02x03_SAO; SAOv169-BADGEv2b-PO-2x3
R1, R2, R4, R6, R10, R20, R31, R32, R51, R52: 47R_6.3mm; R_Axial_DIN0207_L6.3_D2.5_P7.62_Horiz_back
SW1: SW_SPDT_SS12D00G; SW_SPDT_Slide_SS12D00G-1P2T_3pin_back
TCH1: SYM_Touch_lg_x4; psycho_badge_top_art_fcu
U1: ESP32-WEMOS-LOLIN32-LITE; ESP32_WEMOS_LOLIN32_LITE_back

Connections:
2: TCH1.2, U1.2 (GPIO2/TCH2)
4: TCH1.1, U1.4 (GPIO4/TCH0)
5: DS1.5 (CS), U1.5 (GPIO5)
12: D6.2 (A), U1.12 (GPIO12/TCH5)
13: TCH1.4, U1.13 (GPIO13/TCH4)
14: R20.2, U1.14 (GPIO14/TCH6)
15: TCH1.3, U1.15 (GPIO15/TCH3)
16: DS1.7 (RES), U1.16 (GPIO16)
17: DS1.6 (DC), U1.17 (GPIO17)
18: DS1.4 (SCK), U1.18 (GPIO18)
19: D51.2 (A), D52.2 (A), U1.19 (GPIO19)
23: DS1.3 (SDI), U1.23 (GPIO23)
25: D4.2 (A), U1.25 (GPIO25)
26: D31.2 (A), D32.2 (A), U1.26 (GPIO26)
27: R10.2, U1.27 (GPIO27/TCH7)
32: D2.2 (A), U1.32 (GPIO32/TCH9)
33: D1.2 (A), U1.33 (GPIO33/TCH8)
34: DS1.8 (BSY), U1.34 (GPIO34)
+3.3V: C10.1, C11.1, C12.1, C20.1, C21.1, C22.1, C23.1, C24.1, D10.2 (VDD), D11.2 (VDD), D12.2 (VDD), D20.2 (VDD), D21.2 (VDD), D22.2 (VDD), D23.2 (VDD), D24.2 (VDD), DS1.1 (3V3), JSAO1.1, JSAO2.1, U1.3V3 (3v3)
D10: D10.1 (DOUT), D11.4 (DIN)
D11: D11.1 (DOUT), D12.4 (DIN)
D20: D20.1 (DOUT), D21.4 (DIN)
D21: D21.1 (DOUT), D22.4 (DIN)
D22: D22.1 (DOUT), D23.4 (DIN)
D23: D23.1 (DOUT), D24.4 (DIN)
GBAT: BT1.2, J1.2
GND: C10.2, C11.2, C12.2, C20.2, C21.2, C22.2, C23.2, C24.2, D10.3 (GND), D11.3 (GND), D12.3 (GND), D20.3 (GND), D21.3 (GND), D22.3 (GND), D23.3 (GND), D24.3 (GND), DS1.2 (GND), J21.1, J21.2, J22.1, J22.2, JSAO1.2, JSAO2.2, R1.2, R2.2, R4.2, R6.2, R31.2, R32.2, R51.2, R52.2, U1.GND
unnamed: BT1.1, SW1.2 (B)
unnamed: D1.1 (K), R1.1
unnamed: D2.1 (K), R2.1
unnamed: D4.1 (K), R4.1
unnamed: D6.1 (K), R6.1
unnamed: D10.4 (DIN), R10.1
unnamed: D20.4 (DIN), R20.1
unnamed: D31.1 (K), R31.1
unnamed: D32.1 (K), R32.1
unnamed: D51.1 (K), R51.1
unnamed: D52.1 (K), R52.1
VBAT: J1.1, SW1.1 (A)

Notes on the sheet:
Power
Traditional 2-Pin LEDs
This represents four differnt capacitive touch zones in a single footprint
Input Only
Two 1x2 right angle header pins and a rubber band between them hold the Lipo Battery in place
VBAT & GBAT + -
Mechanical Battery Holder
Addressable LEDs
Addon Connectors - SAOs
WARNING: JST-PH connector wired reverse polarity from many cables Black wire might go to + & red to - It depends on cable pinout so... DOUBLE CHECK BEFORE CONNECTING!
Psycho Badge Schematic
Capacitive Touch
Display

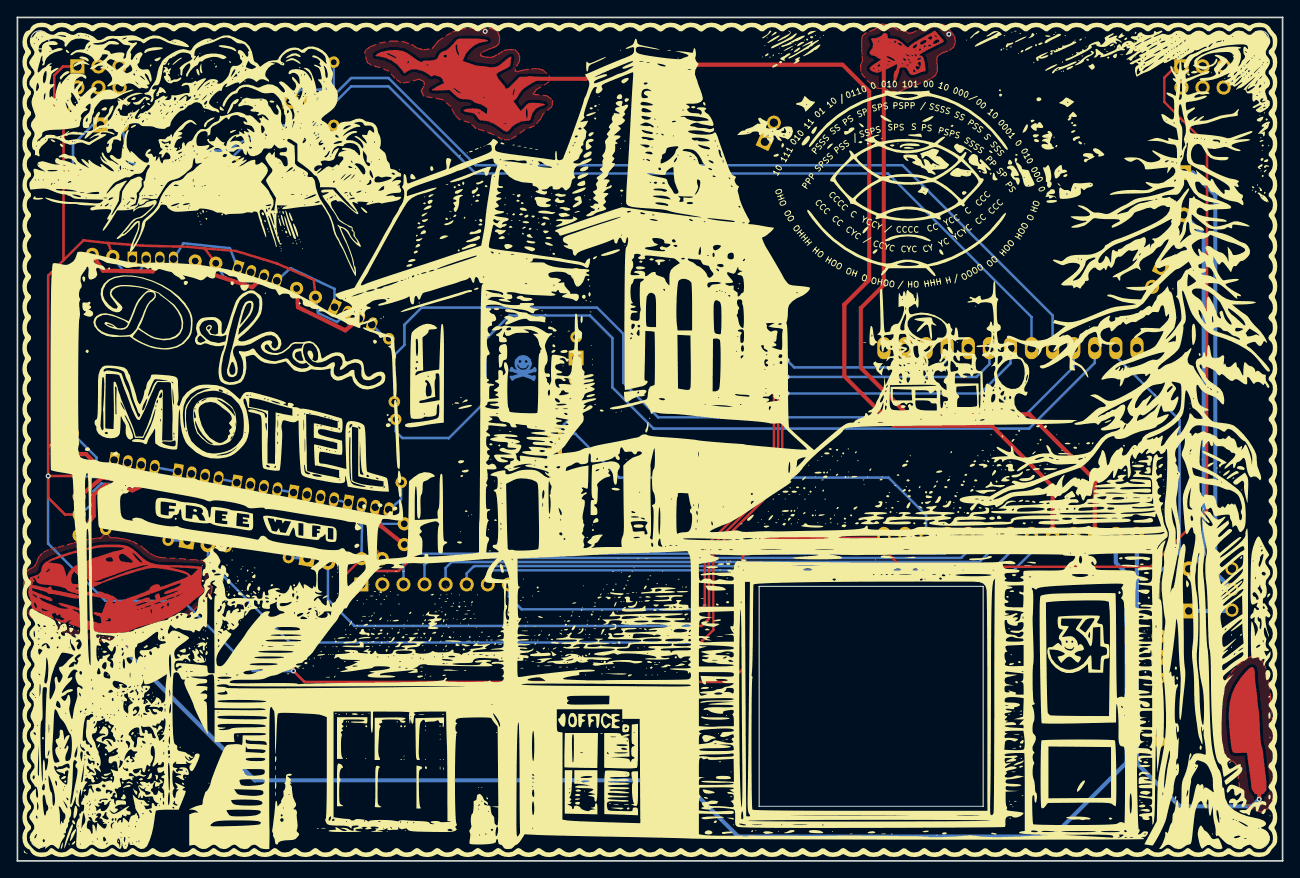
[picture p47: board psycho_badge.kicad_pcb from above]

Board: 2 copper layers, 152.4 x 101.6 mm, 55 parts (0 on the bottom side), 39 nets.

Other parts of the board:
Fold: LED_Fold_Indicator_1; LED_Fold_Indicator_back
Fold#2, Fold#3, Fold#4, Fold#5, Fold#6, Fold#7, Fold#8, Fold#9: LED_Fold_Indicator_1; LED_Fold_Indicator_back
G-FMask: LOGO; psycho_badge_top_art_fmsk
G-Silk: LOGO; psycho_badge_top_art

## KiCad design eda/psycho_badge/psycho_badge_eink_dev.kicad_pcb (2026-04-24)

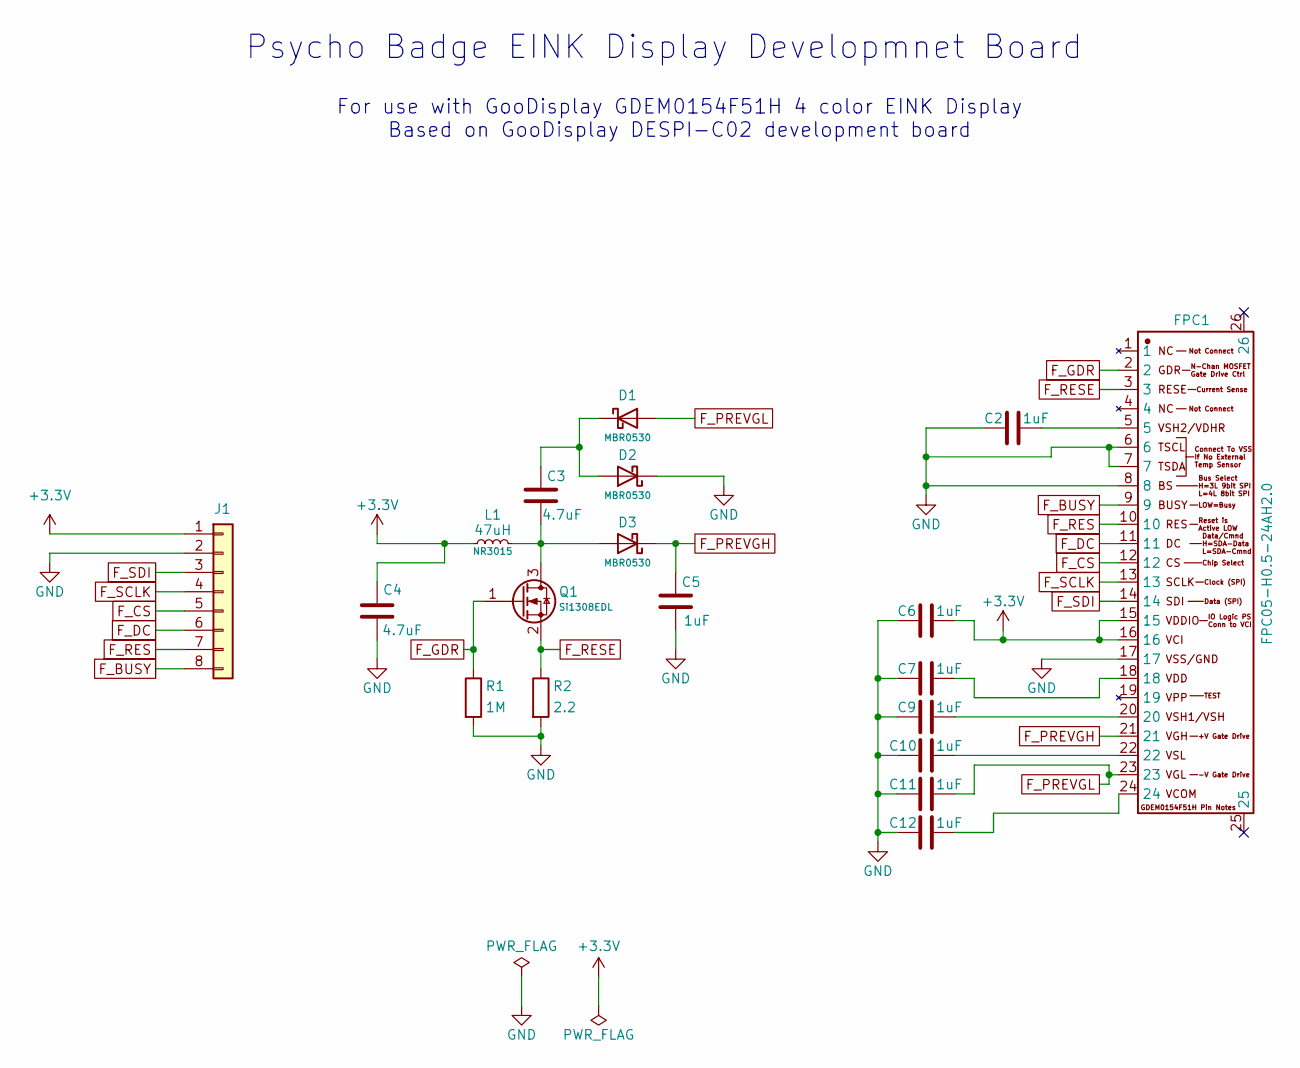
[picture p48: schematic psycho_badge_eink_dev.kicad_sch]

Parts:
C2, C5, C6, C7, C9, C10, C11, C12: 1uF; C_0805_2012Metric
C3, C4: 4.7uF; C_0805_2012Metric
D1, D2, D3: MBR0530; D_SOD-123
FPC1: FPC05-H0.5-24AH2.0; FPC-SMD_24P-P0.50_FPC05-H0.5-24AH2.0; Manufacturer Part FPC05-H0.5-24AH2.0
J1: Conn_01x08; Conn_Pin_Header_Straight_1x08_Pitch2.54mm
L1: 47uH; L_APV_ANR3015
Q1: Si1308EDL; SOT-323_SC-70
R1: 1M; R_0805_2012Metric
R2: 2.2; R_0805_2012Metric

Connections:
+3.3V: C4.2, C6.2, FPC1.15, FPC1.16, J1.1, L1.1
F_BUSY: FPC1.9, J1.8
F_CS: FPC1.12, J1.5
F_DC: FPC1.11, J1.6
F_GDR: FPC1.2, Q1.1 (G), R1.1
F_PREVGH: C5.2, D3.1 (K), FPC1.21
F_PREVGL: C11.2, D1.2 (A), FPC1.23
F_RES: FPC1.10, J1.7
F_RESE: FPC1.3, Q1.2 (S), R2.1
F_SCLK: FPC1.13, J1.4
F_SDI: FPC1.14, J1.3
GND: C2.1, C4.1, C5.1, C6.1, C7.1, C9.1, C10.1, C11.1, C12.1, D2.1 (K), FPC1.6, FPC1.7, FPC1.8, FPC1.17, J1.2, R1.2, R2.2
unnamed: C2.2, FPC1.5
unnamed: C7.2, FPC1.18
unnamed: C9.2, FPC1.20
unnamed: C10.2, FPC1.22
unnamed: C12.2, FPC1.24
unnamed: C3.2, D1.1 (K), D2.2 (A)
unnamed: C3.1, D3.2 (A), L1.2, Q1.3 (D)

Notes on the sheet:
For use with GooDisplay GDEM0154F51H 4 color EINK Display Based on GooDisplay DESPI-C02 development board
Psycho Badge EINK Display Developmnet Board

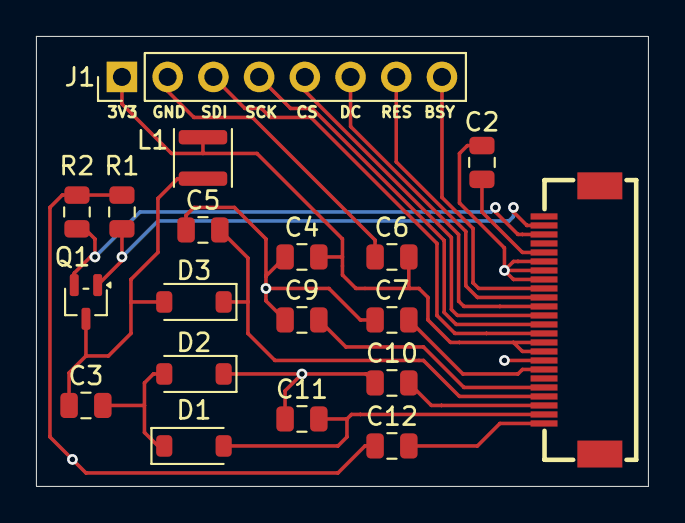
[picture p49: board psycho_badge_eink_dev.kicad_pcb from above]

Board: 2 copper layers, 34.0 x 25.0 mm, 19 parts (0 on the bottom side), 19 nets.

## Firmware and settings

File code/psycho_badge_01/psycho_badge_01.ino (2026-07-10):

// psycho badge code rev01

// Include Libraries
#include <Arduino.h>
#include <WiFi.h>
#include "Adafruit_NeoPixel.h"
#include "SPI.h"
#include <driver/adc.h>
#include <esp_wifi_types.h>
#include <esp_wifi.h>
// EINK Display Libraries
#include "Display_EPD_W21_spi.h"
#include "Display_EPD_W21.h"
#include "Ap_29demo.h"
// Include CTF Library
// #include <psycho_badge_lib.h>


// Pin Definitions
//
// Pins to Avoid:
// GPIO 32 & 33: Connected to the 32kHz crystal oscillator for deep sleep. 
// GPIO 0, 2, 12, & 15 (Strapping Pins):
//   The ESP32 evaluates the voltage on these pins at startup to determine its boot mode
// GPIO 6, 7, 8, 9, 10, & 11: Internally connected to the SPI Flash memory. 
// GPIO 34, 35, 36 (VP), & 39 (VN): Input-only pins.
//
// Safe Pins to use on the LOLIN32 Lite:
// GPIO 4, 5, 13, 14, 25, 26, 27
// GPIO 16, 17, 18, 19, 21, 23
// (Note: GPIO 22 is used for the onboard LED on this board)
//
// NeoPixel Data Pins
#define NEO01_DATA 25
#define NEO02_DATA 26
//
// One color LED Pins
#define LED_D1 19
#define LED_D2 21
#define LED_D3 27
//
// Built-in LED
#define LED_BI 22
//
// Capacitive Touch Pins
#define TCH01_PIN 4   // ESP32 Touch0
#define TCH02_PIN 13  // ESP32 Touch4
#define TCH03_PIN 14  // ESP32 Touch6
//
// EINK Display mapping for ESP32 LOLIN D32
// BUSY -> 34
// RST -> 16
// DC -> 17
// CS -> SS(5)
// CLK -> SCK(18)
// SDI -> MOSI(23)
// GND -> GND, 3.3V -> 3.3V
#define EPD_BUSY_PIN 34
#define EPD_RST_PIN 16
#define EPD_DC_PIN 17
#define EPD_CS_PIN 5
#define EPD_CLK_PIN 18
#define EPD_SDI_PIN 23

// ENABLE EINK TEST LOOP - DISABLES MAIN BADGE LOOP
#define EINK_TEST_LOOP 1

// NeoPixel Properties
//
// Define NeoPixel Strips - (Num pixels, pin to send signals, pixel type, signal rate)
Adafruit_NeoPixel NEO01 = Adafruit_NeoPixel(4, NEO01_DATA, NEO_RGB + NEO_KHZ800);
Adafruit_NeoPixel NEO02 = Adafruit_NeoPixel(4, NEO02_DATA, NEO_RGB + NEO_KHZ800);

// LED Variables
//
// Main LED mode 0=default 1=battleone 2=?
int main_led_mode = 0;
//
// NeoPixel Big Color Value 32 bit = (W-8bit << 24) + (R-8bit << 16) + (G-8bit <<8) + (B-8bit)
uint32_t neo_big_color = 0;
uint8_t neo_col_whi = 0;
uint8_t neo_col_red = 0;
uint8_t neo_col_grn = 0;
uint8_t neo_col_blu = 0;
// Neo Color bitvector 1=red 2=green 4=blue (3=R&G 5=R&B 6=G&B 7=R&G&B)
int neo_color_bitv = 0;

// PWM Properties
//
// Signal Frequency in Hz
const int freq = 1000;
// Duty Cycle Resolution in bits (1-16)
const int resolution = 8;
// PWM channel Assignment (0-15)
const int LED_D1_pwm = 1;

// Wireless Properties
//
// WIFI status codes
const char* wl_status_to_string(wl_status_t status) {
  switch (status) {
    case WL_NO_SHIELD: return "WL_NO_SHIELD";
    case WL_IDLE_STATUS: return "WL_IDLE_STATUS";
    case WL_NO_SSID_AVAIL: return "WL_NO_SSID_AVAIL";
    case WL_SCAN_COMPLETED: return "WL_SCAN_COMPLETED";
    case WL_CONNECTED: return "WL_CONNECTED";
    case WL_CONNECT_FAILED: return "WL_CONNECT_FAILED";
    case WL_CONNECTION_LOST: return "WL_CONNECTION_LOST";
    case WL_DISCONNECTED: return "WL_DISCONNECTED";
  }
}

// Capacitive Touch Properties
//
// Touch Thresholds
int Touch01_Threshold = 28;
// Touch Initial Values
int Touch01_Value = 30;
//
// Touch Counters
//
// Touch Iteration Counter
int Touch01_IntCount = 0;
// Touch Iteration Flag
int Touch01_IntFlag = 0;
// Touch Loop Counter
int Touch01_LoopCount = 0;
// Touch Loop Threshold (Touch Held for X Loops of Main)
int Touch01_Loop_Threshold = 3;

// Analog Input Values
// int JSAO01_Value = 0;
// int JSAO02_Value = 0;

// Loop Control Properties
//
// Main Loop LED Iteration Delay Time [in ms] - Default 20
int LEDDelayTime = 20;
//
// Debug Serial - If set greater than 0 it writes to serial for debugging
// 0 = no debug text
// 1 = basic debug info once per main loop
// 2 = extra debug info
int DebugSerial = 2;

// //////////////////////////////////////////////////
//
// SETUP - RUN ONCE
//
// //////////////////////////////////////////////////
void setup(){
  // Add a delay to allow opening serial monitor
  delay(800);

  // setup the serial output baud rate
  Serial.begin(115200);

  if (DebugSerial >= 1) {
    Serial.println("Starting Setup");
  }

  // Turn Off WiFi/BT
  if (DebugSerial >= 2) {
    Serial.println("Turn Off WiFi / BlueTooth");
  }
  setModemSleep();

  // Configure LED PWM functionalitites per channel
  if (DebugSerial >= 2) {
    Serial.println("Configure PWM Channels");
  }
  ledcSetup(LED_D1_pwm, freq, resolution);

  // Attach the channel to the GPIO to be controlled
  if (DebugSerial >= 2) {
    Serial.println("Attach PWM Channels to LED Pins");
  }
  ledcAttachPin(LED_D1, LED_D1_pwm);

  //Normal LED output
  if (DebugSerial >= 2) {
    Serial.println("Set Output for non-PWM LED Pins");
  }
  pinMode(LED_BI, OUTPUT);

  // Initialize the NeoPixels
  if (DebugSerial >= 2) {
    Serial.println("Initialize NeoPixels");
  }
  NEO01.begin();
  // Set Neopixel Brightness (0-255 scale)
  NEO01.setBrightness(170);
  // Set an initial random color for neopixel functions
  setRandomColor();

  // Start all LEDs in OFF mode
  if (DebugSerial >= 2) {
    Serial.println("Turn OFF all LEDs");
  }
  ledAllOff();

  // Set a Random Seed
  int myrandseed = (analogRead(0) + analogRead(34) + (touchRead(TCH01_PIN) * 2));
  randomSeed(myrandseed);
  if (DebugSerial >= 2) {
    Serial.print("Set Random Seed "); Serial.println(myrandseed);
  }

  // Initialize EINK Display
  if (DebugSerial >= 2) {
    Serial.println("Initialize EINK Display");
  }
  pinMode(EPD_BUSY_PIN, INPUT); // BUSY 34
  pinMode(EPD_RST_PIN, OUTPUT); // RST 16
  pinMode(EPD_DC_PIN, OUTPUT);  // DC 17
  pinMode(EPD_CS_PIN, OUTPUT);  // CS 5
  pinMode(EPD_CLK_PIN, OUTPUT); // CLK 18
  pinMode(EPD_SDI_PIN, OUTPUT); // SDI/MOSI 23
  //
  // EINK SPI Setup
  SPI.beginTransaction(SPISettings(10000000, MSBFIRST, SPI_MODE0)); 
  SPI.begin ();

  if (DebugSerial >= 1) {
    Serial.println(F("Setup Done!"));
  }

  // END OF SETUP
}

// //////////////////////////////////////////////////
//
// LOOP - MAIN 
//
// //////////////////////////////////////////////////
void loop(){
  if (DebugSerial >= 1) {
    Serial.println("******************** TOP OF MAIN LOOP ********************");
  }

  // //////////////////////////////////
  //     BEGIN EINK TEST LOOP
  // //////////////////////////////////
  //  SET EINK_TEST_LOOP TO 1
  //  TO RUN EINK TEST CODE
  //  INSTEAD OF MAIN BADGE LOOP
  // //////////////////////////////////
  if (EINK_TEST_LOOP == 1) {

    if (DebugSerial >= 1) {
      Serial.println("********** EINK TESTING **********");
    }

    BI_on(); // Turn on built-in LED to show badge is on

    // /************Full display Image *******************/
    if (DebugSerial >= 1) {
      Serial.println(" *** EPD Full Display Image ***");
      Serial.println(" **** EPD_init");
    }
    EPD_init();            // Full screen update initialization.
    if (DebugSerial >= 1) {
      Serial.println(" **** PIC_display");
    }
    PIC_display(gImage_1); // To Display one image using full screen update.
    if (DebugSerial >= 1) {
      Serial.println(" **** EPD_sleep");
    }
    EPD_sleep();           // Enter sleep mode - do not delete or reduce lifespan of screen.
    delay(5000);           // Delay for 5s.
    /************Fast update mode(12s) Image *******************/
    if (DebugSerial >= 1) {
      Serial.println(" *** EPD Fast Display Image ***");
      Serial.println(" **** EPD_init_Fast");
    }
    EPD_init_Fast();       // Fast screen update initialization.
    if (DebugSerial >= 1) {
      Serial.println(" **** PIC_display");
    }
    PIC_display(gImage_1); // To Display one image using full screen update.
    if (DebugSerial >= 1) {
      Serial.println(" **** EPD_sleep");
    }
    EPD_sleep();           // Enter sleep mode - do not delete or reduce lifespan of screen.
    delay(5000);           // Delay for 5s.
    /************Full display ALL BLACK *******************/
    if (DebugSerial >= 1) {
      Serial.println(" *** EPD Fast Display ALL BLACK ***");
      Serial.println(" **** EPD_init_Fast");
    }
    EPD_init_Fast();            // Full screen update initialization.
    if (DebugSerial >= 1) {
      Serial.println(" **** Display_All_Black");
    }
    Display_All_Black();   // To Display one image using full screen update.
    if (DebugSerial >= 1) {
      Serial.println(" **** EPD_sleep");
    }
    EPD_sleep();           // Enter sleep mode - do not delete or reduce lifespan of screen.
    delay(3000);           // Delay for 3s.
    /************Full display ALL YELLOW *******************/
    if (DebugSerial >= 1) {
      Serial.println(" *** EPD Fast Display ALL YELLOW ***");
      Serial.println(" **** EPD_init_Fast");
    }
    EPD_init_Fast();            // Full screen update initialization.
    if (DebugSerial >= 1) {
      Serial.println(" **** Display_All_Yellow");
    }
    Display_All_Yellow();  // To Display one image using full screen update.
    if (DebugSerial >= 1) {
      Serial.println(" **** EPD_sleep");
    }
    EPD_sleep();           // Enter sleep mode - do not delete or reduce lifespan of screen.
    delay(3000);           // Delay for 3s.
    /************Full display ALL RED *******************/
    if (DebugSerial >= 1) {
      Serial.println(" *** EPD Fast Display ALL RED ***");
      Serial.println(" **** EPD_init_Fast");
    }
    EPD_init_Fast();            // Full screen update initialization.
    if (DebugSerial >= 1) {
      Serial.println(" **** Display_All_Red");
    }
    Display_All_Red();     // To Display one image using full screen update.
    if (DebugSerial >= 1) {
      Serial.println(" **** EPD_sleep");
    }
    EPD_sleep();           // Enter sleep mode - do not delete or reduce lifespan of screen.
    delay(3000);           // Delay for 3s.
    /************Full display ALL WHITE *******************/
    if (DebugSerial >= 1) {
      Serial.println(" *** EPD Fast Display ALL WHITE ***");
      Serial.println(" **** EPD_init_Fast");
    }
    EPD_init_Fast();            // Full screen update initialization.
    if (DebugSerial >= 1) {
      Serial.println(" **** Display_All_White");
    }
    Display_All_White();   // To Display one image using full screen update.
    if (DebugSerial >= 1) {
      Serial.println(" **** EPD_sleep");
    }
    EPD_sleep();           // Enter sleep mode - do not delete or reduce lifespan of screen.
    delay(5000);           // Delay for 5s.

  }
  // //////////////////////////////////
  //     END EINK TEST LOOP
  // //////////////////////////////////

  // //////////////////////////////////
  //     START OF MAIN BADGE LOOP
  // //////////////////////////////////
  //     ENSURE EINK_TEST_LOOP NOT 1
  //     TO ENABLE MAIN BADGE LOOP
  // //////////////////////////////////
  if (EINK_TEST_LOOP != 1) {

    if (DebugSerial >= 1) {
      Serial.println("********** MAIN BADGE LOOP **********");
    }

    // Capacitive Touch Dynamic Threshold Adjustment
    // Adjust thresholds UP to account for assembly conditions and battery vs usb
    Touch01_Value = touchRead(TCH01_PIN);
    if ( (Touch01_Value / Touch01_Threshold) > 2 ) { Touch01_Threshold = int(Touch01_Threshold * 1.8); }

    // //////////////////////////////////
    //     START OF ITERATION LOOP
    // //////////////////////////////////
    
    // Iterate 0 to 254
    for(int i=0; i<255; i++){
      // Set position value to iteration value
      int pos = i;

      // DEBUG - Print current Iteration value to serial console for troubleshooting
      if (DebugSerial >= 2) {
        Serial.print(" Iteration="); Serial.print(i);
        Serial.print(" Pos="); Serial.print(pos);
      }

      //
      // TOUCH
      //
      // Read Touch Values
      Touch01_Value = touchRead(TCH01_PIN);
      //
      // **************************************************************
      //
      // Do Stuff If We Detect a Touch on TCH01_PIN
      if (Touch01_Value < Touch01_Threshold) {
        // DEBUG - Print current Touch value/threshold to serial console for troubleshooting
        if (DebugSerial >= 2) {
          Serial.print(" T1_TCH="); Serial.print(Touch01_Value);
          Serial.print("/"); Serial.print(Touch01_Threshold);
          Serial.print("-"); Serial.print(Touch01_IntCount);
          Serial.print("/"); Serial.print(Touch01_LoopCount);
        }
        // STUFF - TCH01_PIN TOUCHED
        if (Touch01_IntFlag == 0){
          // Put stuff to happen once per iteration loop here
          Touch01_IntFlag = 1;
        }
        // Put stuff to happen every iteration here
        Touch01_IntCount++;
        //
        // **************
        // FUNCTION TO CALL GOES HERE
        // EXAMPLE:
        // monarch_neo_color();
        // **************
      //
      // Do Stuff If We DONT Detect a Touch on TCH01_PIN
      } else {
        // DEBUG - Print current Touch value/threshold to serial console for troubleshooting
        if (DebugSerial >= 2) {
          Serial.print(" T1="); Serial.print(Touch01_Value);
          Serial.print("/"); Serial.print(Touch01_Threshold);
          Serial.print("-"); Serial.print(Touch01_IntCount);
          Serial.print("/"); Serial.print(Touch01_LoopCount);
        }
        // STUFF - TCH01_PIN NOT TOUCHED
        if (Touch01_IntCount > 1) { Touch01_IntCount--; } else { Touch01_IntCount = 0; }
      }
      //
      // **************************************************************
      //

      // Read Analog Input Values
      // JSAO01_Value = analogRead(JSAO01);
      // JSAO02_Value = analogRead(JSAO02);
      // Display Analog Values
      // if (DebugSerial >= 2) {
      //   Serial.print(" SAO1="); Serial.print(JSAO01_Value);
      //   Serial.print(" SAO2="); Serial.print(JSAO02_Value);
      // }

      if (main_led_mode == 0) {
        //
        // DEFAULT MODE
        //
        // First of three position groups i 0-84
        if (pos < 85) {
          //
          // LED FUNCTIONS
          BI_blink_three(pos);
        // Second of three position groups i 85-169 (pos-85 = 0-84)
        } else if (pos < 170) {
          pos = pos - 85;
          //
          // LED FUNCTIONS
          BI_blink_three(pos);
        // Third of three position groups i 170-254 (pos-170 = 0-84)
        } else {
          pos = pos -170;
          //
          // LED FUNCTIONS
          BI_blink_three(pos);
          // Split third group 3/4 (pos 0-42) for even number of transitions
          if (pos <43) {
            //
          // Split third group 4/4 (pos 43-84) for even number of transitions
          } else {
            //
          }
        }
      } else if (main_led_mode == 1) {
        //
        // BATTLE MODE
        //
        // First of three position groups i 0-84
        if (pos < 85) {
          //
          // LED FUNCTIONS
          BI_blink_two(pos);
        // Second of three position groups i 85-169 (pos-85 = 0-84)
        } else if (pos < 170) {
          pos = pos - 85;
          //
          // LED FUNCTIONS
          BI_blink_two(pos);
        // Third of three position groups i 170-254 (pos-170 = 0-84)
        } else {
          pos = pos -170;
          //
          // LED FUNCTIONS
          BI_blink_two(pos);
          // Split third group 3/4 (pos 0-42) for even number of transitions
          if (pos <43) {
            //
          // Split third group 4/4 (pos 43-84) for even number of transitions
          } else {
            //
          }
        }
      }

      // DEBUG - Print NEO color vars
      if (DebugSerial >= 2) {
        Serial.print(" C="); Serial.print(neo_col_red);
        Serial.print("/"); Serial.print(neo_col_grn);
        Serial.print("/"); Serial.print(neo_col_blu);
        Serial.print("/"); Serial.print(neo_color_bitv);
      }

      // DEBUG - Print LED mode
      if (DebugSerial >= 2) {
        Serial.print(" Mode="); Serial.print(main_led_mode);
      }

      // DEBUG - Print Carriage Return for iteration level debug output
      if (DebugSerial >= 2) {
        Serial.println();
      }

      // Display Neopixel values
      neo_show();

      // Pause the loop to display everything
      delay(LEDDelayTime);

      // END OF FOR ITERATION LOOP
    }
    // //////////////////////////////////
    //     END OF ITERATION LOOP
    // //////////////////////////////////

    // Touch Loop Counters - USE TBD
    if (Touch01_IntCount >= 1) { Touch01_LoopCount++; Touch01_IntCount = 0; } else { Touch01_LoopCount = 0; }

    // Reset Touch Iteration Flags
    Touch01_IntFlag = 0;

    // Turn off all LEDs at end of loop (Optional for troubleshooting)
    // ledAllOff();

    // //////////////////////////////////////////////////
    //
    // Launch BATT_CHRG_NOLED Alternate Mainline Code When
    // Touch01_LoopCount exceeds Touch01_Loop_Threshold
    // Touch01 is the Monarch Logo
    //
    // //////////////////////////////////////////////////
    if (Touch01_LoopCount > Touch01_Loop_Threshold) {
      //
      Serial.println("LONG TOUCH DETECTED on TCH02 - JUMP TO ALTERNATE CODE");
      //
      ledAllOff();
      //
      Touch01_LoopCount = 0;
      //
      // Alternate code loop
      batt_chrg_noled();
      //
      // END ALTERNATE MAIN LOOP
      Serial.println("****************************************");
      Serial.println("***** EXITING BATT_CHRG_NOLED MODE *****");
      Serial.println("****************************************");
      //
      ledAllOff();
      //
      Touch01_LoopCount = 0;
      //
      main_led_mode = 0;
      // Pause before exiting
      delay(100);
    }

  }
  // //////////////////////////////////
  //        END OF MAIN BADGE LOOP
  // //////////////////////////////////

}
// //////////////////////////////////
//        END OF LOOP - MAIN
// //////////////////////////////////


// //////////////////////////////////////////////////
//
// FUNCTIONS
//
// //////////////////////////////////////////////////
//
// WiFi & BT Functions
// //////////////////////////////////////////////////
void disableWiFi(){
    WiFi.disconnect(true);  // Disconnect from the network
    WiFi.mode(WIFI_OFF);    // Switch WiFi off
    Serial.println("WiFi disabled!");
}
//
void disableBluetooth(){
    btStop();
    Serial.println("Bluetooth stopped!");
}
//
void setModemSleep() {
    disableWiFi();
    disableBluetooth();
    setCpuFrequencyMhz(80);
}
//
void enableWiFi(){
    delay(200);
    // Switch Wifi ON in mode AP/STA/AP_STA
    WiFi.mode(WIFI_AP); // Defaulting to AP mode
    delay(200);
    Serial.println("WiFi Started!");
}
//
void wakeModemSleep() {
    setCpuFrequencyMhz(240);
    enableWiFi();
}
// //////////////////////////////////////////////////
//
// LED Functions
// //////////////////////////////////////////////////
void ledAllOff() {
    digitalWrite(LED_BI, HIGH); // HIGH = OFF?
    ledcWrite(LED_D1_pwm, 0);
    NEO01.setPixelColor(0, 0, 0, 0);
    NEO01.setPixelColor(1, 0, 0, 0);
    NEO01.setPixelColor(2, 0, 0, 0);
    NEO01.setPixelColor(3, 0, 0, 0);
    NEO01.show();
}
//
void ledPwmAllOn() {
    ledcWrite(LED_D1_pwm, 255);
}
//
void ledPwmAllOff() {
    ledcWrite(LED_D1_pwm, 0);
}
//
void setRandomColor() {
    // Basic Random numbers for on/off
    int colorrand41 = random(0-4); int colorrand42 = random(0-4); int colorrand43 = random(0-4);
    int colorrand4t = colorrand41 + colorrand42 + colorrand43;
    // Reset colors
    neo_col_whi = 0;
    neo_col_red = 0;
    neo_col_grn = 0;
    neo_col_blu = 0;
    // Set Red
    if (colorrand4t > 3) { neo_col_red = random(50, 255); }
    // Set Blue
    if (neo_col_red == 0 and colorrand4t > 1) { neo_col_blu = random(50, 255); } else if (colorrand4t > 3) { neo_col_blu = random(50, 255); }
    // Set Green
    if (neo_col_blu == 0 and colorrand4t > 3) { neo_col_grn = random(50, 255); } else if (colorrand4t > 5) { neo_col_grn = random(50, 255); }
    // Make sure at least one color is not zero
    if ((neo_col_red + neo_col_grn + neo_col_blu) == 0) { neo_col_red = 255; }
    // Set Color
    neo_big_color = (neo_col_whi << 24) + (neo_col_red << 16) + (neo_col_grn << 8) + neo_col_blu;
}
//
void setStaticColor(uint8_t sred, uint8_t sgrn, uint8_t sblu, uint8_t bitv) {
    // Define colors
    neo_col_whi = 0;
    neo_col_red = 0;
    neo_col_grn = 0;
    neo_col_blu = 0;
    // Neo Color bitvector 1=red 2=green 4=blue (3=R&G 5=R&B 6=G&B 7=R&G&B)
    if (bitv > 0) {
      // Red
      if (bitv == 1 || bitv == 3 || bitv == 5 || bitv == 7) { neo_col_red = 255; }
      // Green
      if (bitv == 2 || bitv == 3 || bitv == 6 || bitv == 7) { neo_col_grn = 255; }
      // Blue
      if (bitv == 4 || bitv == 5 || bitv == 6 || bitv == 7) { neo_col_blu = 255; }
      // Catchall
      if (bitv > 7) {
        neo_col_red = 255;
        neo_col_grn = 255;
        neo_col_blu = 255;
      }
    } else {
      neo_col_red = sred;
      neo_col_grn = sgrn;
      neo_col_blu = sblu;
    }
    // Make sure at least one color is not zero
    if ((neo_col_red + neo_col_grn + neo_col_blu) == 0) { neo_col_red = 255; }
    // Set Color
    neo_big_color = (neo_col_whi << 24) + (neo_col_red << 16) + (neo_col_grn << 8) + neo_col_blu;
}
//
void neo_show() {
    // Display neopixel colors set by other functions
    NEO01.show();
}
//
void BI_on() {
    digitalWrite(LED_BI, LOW); // LOW = ON?
}
//
void BI_off() {
    digitalWrite(LED_BI, HIGH); // HIGH = OFF?
}
//
void BI_blink_one(uint8_t pos) {
    if (pos <= 21) {
      digitalWrite(LED_BI, LOW); // LOW = ON?
    } else {
      digitalWrite(LED_BI, HIGH); // HIGH = OFF?
    }
}
//
void BI_blink_two(uint8_t pos) {
    if (pos <= 11) {
      digitalWrite(LED_BI, LOW); // LOW = ON?
    } else if (pos > 11 and pos <= 22) {
      digitalWrite(LED_BI, HIGH); // HIGH = OFF?
    } else if (pos > 22 and pos <= 33) {
      digitalWrite(LED_BI, LOW); // LOW = ON?
    } else {
      digitalWrite(LED_BI, HIGH); // HIGH = OFF?
    }
}
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

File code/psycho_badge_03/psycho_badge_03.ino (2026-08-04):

// psycho badge code rev03

// Include Libraries
#include <Arduino.h>
// Wifi Libraries
#include <WiFi.h>
#include <esp_wifi_types.h>
#include <esp_wifi.h>
// SPI Library
#include <SPI.h>
// ADC Library
#include <driver/adc.h>
// NeoPixel Library
#include "Adafruit_NeoPixel.h"
// Preferences library for storing persistent settings
#include <Preferences.h>
// EINK Display Libraries
#include "src/edp/Display_EPD_W21_spi.h"
#include "src/edp/Display_EPD_W21.h"
#include "src/img/psycho_img01.h"
#include "src/img/psycho_img02.h"
#include "src/img/psycho_img03.h"
#include "src/img/psycho_img04.h"
#include "src/img/psycho_img05.h"
#include "src/img/psycho_img06.h"
#include "src/img/psycho_img07.h"
// Include CTF Library
// NO CTF YET... No Time, Sorry
// #include <psycho_badge_lib.h>

// Preferences object for storing persistent settings
Preferences preferences;

// Pin Definitions
//
// Pins to Avoid:
// GPIO 32 & 33: Connected to the 32kHz crystal oscillator for deep sleep. 
// GPIO 0, 2, 12, & 15 (Strapping Pins):
//   The ESP32 evaluates the voltage on these pins at startup to determine its boot mode
// GPIO 6, 7, 8, 9, 10, & 11: Internally connected to the SPI Flash memory. 
// GPIO 34, 35, 36 (VP), & 39 (VN): Input-only pins.
//
// Safe Pins to use on the LOLIN32 Lite:
// GPIO 4, 5, 13, 14, 25, 26, 27
// GPIO 16, 17, 18, 19, 21, 23
// (Note: GPIO 22 is used for the onboard LED on this board)
//
// NeoPixel Data Pins
#define NEO01_DATA 27 // Defcon
#define NEO02_DATA 14 // Motel
//
// One color LED Pins
#define LED_D1 33 // FREE
#define LED_D2 32 // WIFI
#define LED_D3 26 // Clouds x2
#define LED_D4 25 // Clouds
#define LED_D5 19 // Mansion x2
#define LED_D6 12 // Room_Door
//
// Built-in LED
#define LED_BI 22
//
// Capacitive Touch Pins
#define TCH01_PIN 4    // Bats
#define TCH02_PIN 2    // Satelite
#define TCH03_PIN 15   // Car
#define TCH04_PIN 13   // Knife
//
// EINK Display mapping for ESP32 LOLIN D32
// BUSY -> 34
// RST -> 16
// DC -> 17
// CS -> SS(5)
// CLK -> SCK(18)
// SDI -> MOSI(23)
// GND -> GND, 3.3V -> 3.3V
#define EPD_BUSY_PIN 34
#define EPD_RST_PIN 16
#define EPD_DC_PIN 17
#define EPD_CS_PIN 5
#define EPD_CLK_PIN 18
#define EPD_SDI_PIN 23
//
// Remapping standard SPI MISO pin due to conflict
#define NEW_MISO_PIN 0  // was 19 which is now LED since EINK does not use MISO
//
// EINK Display Model Selection
// Set to EPD_MODEL_51H for the original GDEM0154F51H panel
// or EPD_MODEL_61H for the updated GDEM0154F61H panel
unsigned char display_model = EPD_MODEL_51H;

// NeoPixel Properties
//
// Define NeoPixel Strips - (Num pixels, pin to send signals, pixel type, signal rate)
Adafruit_NeoPixel NEO01 = Adafruit_NeoPixel(3, NEO01_DATA, NEO_RGB + NEO_KHZ800);
Adafruit_NeoPixel NEO02 = Adafruit_NeoPixel(5, NEO02_DATA, NEO_RGB + NEO_KHZ800);

// LED Variables
//
// Main LED mode 0=default 1=coloshift 2+=?
int main_led_mode = 0;
// Door LED mode toggles on/off - helps light eink display
int door_led_mode = 0;
// Free Wifi LED mode toggles flashing/off
int freewifi_led_mode = 1;

//
// NeoPixel Big Color Value 32 bit = (W-8bit << 24) + (R-8bit << 16) + (G-8bit <<8) + (B-8bit)
uint32_t neo_big_color = 0;
uint8_t neo_col_whi = 0;
uint8_t neo_col_red = 0;
uint8_t neo_col_grn = 0;
uint8_t neo_col_blu = 0;
// Neo Color bitvector 1=red 2=green 4=blue (3=R&G 5=R&B 6=G&B 7=R&G&B)
int neo_color_bitv = 5;

// // PWM Properties
// //
// // Signal Frequency in Hz
// const int freq = 1000;
// // Duty Cycle Resolution in bits (1-16)
// const int resolution = 8;
// // PWM channel Assignment (0-15)
// const int LED_D1_pwm = 1;

// Wireless Properties
//
// WIFI status codes
const char* wl_status_to_string(wl_status_t status) {
  switch (status) {
    case WL_NO_SHIELD: return "WL_NO_SHIELD";
    case WL_IDLE_STATUS: return "WL_IDLE_STATUS";
    case WL_NO_SSID_AVAIL: return "WL_NO_SSID_AVAIL";
    case WL_SCAN_COMPLETED: return "WL_SCAN_COMPLETED";
    case WL_CONNECTED: return "WL_CONNECTED";
    case WL_CONNECT_FAILED: return "WL_CONNECT_FAILED";
    case WL_CONNECTION_LOST: return "WL_CONNECTION_LOST";
    case WL_DISCONNECTED: return "WL_DISCONNECTED";
  }
}

// Capacitive Touch Properties
//
// Touch Thresholds
int Touch01_Threshold = 28;
int Touch02_Threshold = 28;
int Touch03_Threshold = 28;
int Touch04_Threshold = 28;
// Touch Initial Values
int Touch01_Value = 30;
int Touch02_Value = 30;
int Touch03_Value = 30;
int Touch04_Value = 30;
//
// Touch Counters
//
// Touch Iteration Counter
int Touch01_IntCount = 0;
int Touch02_IntCount = 0;
int Touch03_IntCount = 0;
int Touch04_IntCount = 0;
// Touch Iteration Flag
int Touch01_IntFlag = 0;
int Touch02_IntFlag = 0;
int Touch03_IntFlag = 0;
int Touch04_IntFlag = 0;
// Touch Loop Counter
int Touch01_LoopCount = 0;
int Touch02_LoopCount = 0;
int Touch03_LoopCount = 0;
int Touch04_LoopCount = 0;
// Touch Loop Threshold (Touch Held for X Loops of Main)
//   Used to determine if there is a 'Long' touch to trigger specific events
//   Each Loop is between 6000 and 7000 ms (6 to 7 seconds)
int Touch01_Loop_Threshold = 3;
int Touch02_Loop_Threshold = 3;
int Touch03_Loop_Threshold = 1;
int Touch04_Loop_Threshold = 1;
// Touch Iter Threshold (Touch Held for X Iterations in the main loop)
//   Used to prevent glancing touches activating the touch events
//   Each iteration is between 3 and 4 ms
int Touch01_Iter_Threshold = 9;
int Touch02_Iter_Threshold = 9;
int Touch03_Iter_Threshold = 9;
int Touch04_Iter_Threshold = 9;

// Display Image List
const unsigned char* const DisplayImage[] = {
  gImage_dying_reach_05,
  gImage_psycho_hitchcock_02,
  gImage_psycho_poster_ylw_01,
  gImage_psycho_crazy_dress_07,
  gImage_scream_red_04,
  gImage_psycho_mother_03,
  gImage_psycho_poster_red_06
};
// Display Image Names - must stay in the same order as DisplayImage[]
// Used for debugging to print the current display image name
const char* const DisplayImageNames[] = {
  "gImage_dying_reach_05",
  "gImage_psycho_hitchcock_02",
  "gImage_psycho_poster_ylw_01",
  "gImage_psycho_crazy_dress_07",
  "gImage_scream_red_04",
  "gImage_psycho_mother_03",
  "gImage_psycho_poster_red_06"
};
unsigned int ImgMax = 6;       // array index max number (0-based)
unsigned int ImgElement = 0;   // Should be set by preferences read in setup
unsigned int ImgElementPref;   // To be read from preferences in setup

int DisplayUpdateCooldownDefault = 1;  // loops to wait between display updates
int DisplayUpdateCooldown = DisplayUpdateCooldownDefault;

// Loop Control Properties
//
// Main Loop LED Iteration Delay Time [in ms] - Default 25
int LEDDelayTime = 25;
//
// Timers
unsigned long IterTimer = 0;
unsigned long LoopTimer = 0;
//
// Debug Serial - If set greater than 0 it writes to serial for debugging
// 0 = no debug text
// 1 = basic debug info once per main loop
// 2 = extra debug info
int DebugSerial = 2;
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

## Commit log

2025-05-31 initial content push
    [BatteryHolder_2466_1xAAA.step, BatteryHolder_2468_2xAAA.step, Battery_Holder_3xAAA_Simple.step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]
2025-06-01 psycho badge art and eda updates
    [psycho_badge.kicad_pcb]
2025-08-24 pre dc33 updates
    [TFT_LCD_ST7735S_MSP1443_SPI_1_44IN.STEP, psycho_badge.kicad_pcb]
2026-04-09 component updates
    [Hirose_FH12-24S-0.5SH_1x24-1MP_P0.50mm_Horizontal.step, LCSC__WM2604100066_20260410012841.csv]
2026-04-21 added eink display circuit and dev board
    [D_SOD-123.step, L_APV_ANR3015.step, SOT-323_SC-70.step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]
2026-04-24 eink dev board final
    [psycho_badge_eink_dev-B_Cu.gbl, psycho_badge_eink_dev-B_Mask.gbs, psycho_badge_eink_dev-B_Paste.gbp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]
2026-05-28 art updates
    [psycho_badge.kicad_pcb]
2026-06-22 component layout done
    [psycho_badge.kicad_pcb, psycho_badge.kicad_sch, psycho_badge_eink_dev-F_Paste.dxf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]
2026-06-24 .gitignore scratch directories
    Currently, just any directory called "testing".
2026-06-24 pcb tracing
    [psycho_badge.kicad_pcb]
2026-06-29 main pcb complete
    [psycho_badge.kicad_pcb, psycho_badge.kicad_sch, psycho_badge_back.kicad_pcb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]
2026-06-29 Psycho SAO Upload
    The template files for SAO boards. Hopefully all 8 files are included in this PR...
    [sao1.kicad_pcb, sao2.kicad_pcb, sao3.kicad_pcb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]
2026-06-30 main badge pcb updates
    [psycho_badge.kicad_pcb, psycho_badge_back.kicad_pcb]
2026-06-30 pcb updates
    [psycho_badge.kicad_pcb, psycho_badge_back.kicad_pcb]
2026-06-30 pcb updates... final?
    [psycho_badge_back.kicad_pcb]
2026-07-01 pcb gerbers
    [psycho_badge-B_Cu.gbr, psycho_badge-B_Mask.gbr, psycho_badge-B_Paste.gbr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]
2026-07-01 sao template work
    [BatteryHolder_2466_1xAAA.step, BatteryHolder_2468_2xAAA.step, Battery_Holder_3xAAA_Simple.step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]
2026-07-03 psycho sao scream done
    [psycho_sao.kicad_pcb]
2026-07-03 psycho sao final plus doc updates
    [psycho_sao-B_Cu.gbr, psycho_sao-B_Mask.gbr, psycho_sao-B_Paste.gbr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]
2026-07-07 SB Hype Train SAO work
    [psycho_sao_2.kicad_pcb, sao1.kicad_pcb, sao2.kicad_pcb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]
2026-07-10 Add 3D Parts + 3mf for board spacer
    [board_spacer.3mf, psycho_badge.FCStd]
2026-07-10 code and doc file reorg
    [board_spacer.3mf, psycho_badge.FCStd]
2026-07-12 SB SAO final and code updates
    [psycho_sao_2-B_Cu.gbr, psycho_sao_2-B_Mask.gbr, psycho_sao_2-B_Paste.gbr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]
2026-07-13 3d_part update and some snapshots
    [CE3PRO_psycho_badge_rev2-board_spacer-1.3mf, psycho_badge_rev2-board_spacer.3mf, psycho_badge_rev2.FCStd]
2026-07-15 3d_part update for 2x prints
    [CE3PRO_psycho_badge_rev2-board_spacer-2.3mf]

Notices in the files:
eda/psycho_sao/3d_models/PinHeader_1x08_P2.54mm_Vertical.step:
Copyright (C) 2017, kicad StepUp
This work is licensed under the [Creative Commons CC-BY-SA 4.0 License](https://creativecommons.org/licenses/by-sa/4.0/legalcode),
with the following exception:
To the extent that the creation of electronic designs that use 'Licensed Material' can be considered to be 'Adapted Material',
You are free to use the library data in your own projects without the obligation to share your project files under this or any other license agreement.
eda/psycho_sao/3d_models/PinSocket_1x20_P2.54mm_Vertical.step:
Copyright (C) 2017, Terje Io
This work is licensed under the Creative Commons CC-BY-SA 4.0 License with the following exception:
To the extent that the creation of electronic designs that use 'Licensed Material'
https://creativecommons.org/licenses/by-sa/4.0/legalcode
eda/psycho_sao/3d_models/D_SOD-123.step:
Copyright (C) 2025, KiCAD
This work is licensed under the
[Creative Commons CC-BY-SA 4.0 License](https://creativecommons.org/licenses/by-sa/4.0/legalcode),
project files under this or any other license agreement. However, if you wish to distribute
